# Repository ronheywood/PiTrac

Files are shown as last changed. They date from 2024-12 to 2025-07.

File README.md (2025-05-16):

**Introduction to PiTrac:**

- [Introduction](#introducing-pitrac)
  - [Project Page](#project-page)
- [PiTrac - Start Here](#getting-started)
- [PiTrac - Setup and Configuration](#setup-and-configuration)
- [PiTrac - Join the Discord](#join-the-discord)

## Introducing PiTrac
Introducing [PiTrac](https://hackaday.io/project/195042-pitrac-the-diy-golf-launch-monitor) \- the world’s first (free\!) open-source golf launch monitor (as far as we know). 



PiTrac uses low-cost Raspberry Pi(\*) computers and cameras to determine golf ball launch speed, angles and spin in three dimensions.  PiTrac interfaces with both GSPro and E6/TruGolf simulators, and its output is also accessible on a stand-alone web-based app.  \[We’ve reached out to 2k/TopGolf, but no response yet.\]

PiTrac uses off-the-shelf hardware, and includes a [parts list](https://github.com/jamespilgrim/PiTrac/blob/main/Documentation/PiTrac%20-%20DIY%20LM%20%20Parts%20List.md) with links to potential suppliers.  The only custom part is a small printed circuit board.  The fabrication instructions for that PCB are included in the open-source distribution and it can be manufactured for a few dollars.  The two Pi computers and cameras are the most expensive parts, and cost around $250 in total.

PiTrac is not a commercial product for sale–the full design is being released as open source on GitHub for folks to build themselves.  It’s not easy, but if you’re handy with a soldering iron, can figure out how to 3D print the parts, and are willing to burrow into the Linux operating system to compile and install software, you should be able to create your own PiTrac\!  

We are hoping that we can inspire a community of developers to help test and continue PiTrac’s development.  This is a really immature project right now.  The basic features usually work reliably, but the current release is a bit dodgy.  We’re looking for folks to try building their own PiTracs and help us improve the documentation and design to make it easier for other people to do the same.

## Project Page
Please visit our [project page](https://hackaday.io/project/195042-pitrac-the-diy-golf-launch-monitor) and also our YouTube channel [here](https://www.youtube.com/@PiTrac) for more details and videos.  The [GitHub repository](https://github.com/jamespilgrim/PiTrac) is in the works and already has the 3D printed part designs, the hardware design and initial software documentation.  If you’re interested in more of the details and some of PiTrac’s development history, please look through the [project logs](https://hackaday.io/project/195042-pitrac-the-diy-golf-launch-monitor#menu-logs).  

Finally, any help at our [support page](https://ko-fi.com/Pitrac) would be appreciated to continue this work and complete the release process.

(\*) Raspberry Pi is a trademark of Raspberry Pi Ltd.  The PiTrac project is not endorsed, sponsored by or associated with Raspberry Pi or Raspberry Pi products or services.

## [Getting Started](/Documentation/PiTrac%20–%20START%20HERE.md)
The process of building your own PiTrac DIY Launch Monitor is described here at a high level. There are several more-detailed instruction documents elsewhere in the PiTrac repository that are referred to below for various sub-assemblies and tasks like compiling the code and preparing the build environment.

## [Setup and Configuration](/Documentation/Raspberry%20Pi%20Setup%20and%20Configuration.md)
The instructions which are targeted toward getting setup on a step-by-step basis. These instructions start with a Raspberry Pi with nothing on it, and are meant to describe all the steps to get from that point to a working, compiled version of PiTrac.  PiTrac currently requires two Raspberry Pi’s, so the majority of these instructions will have to be repeated twice.  Because the ‘smaller’ Pi system that connects to Camera 2 is the only Pi that handles the Tomcat/Tomee web-based GUI for the system, there are a few more steps for that system.

## [Join the Discord](https://discord.gg/CP3gVkH7)
The PiTrac discord is where you can get help or show off your PiTrac build, discuss features and get to know other PiTrac builders. PiTrac is still a new project, so the Discord is a way to clear up any fuzzy parts of the initial ecosystem. Click the link above or copy this invite link in Discord: `https://discord.gg/9nEeVrPX`.

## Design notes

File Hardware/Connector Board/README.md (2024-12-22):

**Description:**

A small PCB that supports:

1. high-speed (up to 1MHz), isolated switching of a high-power signal (12V, 100W) to a device such as an LED strobe; and
2. connecting a GPIO camera shutter signal from one Raspberry Pi to the external trigger (XTR) of a Pi Global Shutter (GS) Camera that is connected to a _second_ Raspberry Pi.

The board uses high-speed opto-isolators to keep the power plane of the two Pi’s isolated from each other and from the 12V switching circuit.

The PCB itself can be manufactured fairly inexpensively from the fabrication outputs at place like <https://jlcpcb.com/> and <https://pcbway.com> .

The [PiTrac DIY golf launch monitor project](https://hackaday.io/project/195042-diy-golf-launch-monitor) is using this board to drive its infrared strobe light and to allow one Pi to trigger the shutter of a second Pi. This is all used to capture the stop-motion images for the monitor.

Please consider supporting this work and the DIY LM project here: <https://ko-fi.com/PiTrac>  

**Parts Needed for Assembly:**

| **Item** | **Qty** | **Reference(s)** | **Value** | **LibPart** | **Footprint / Details** |
| --- | --- | --- | --- | --- | --- |
| 1 | 1 | J3  | ~ | [USB B Micro Female Pinboard](https://www.amazon.com/Pinboard-MELIFE-Interface-Adapter-Breakout/dp/B07W6T97HZ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) | The included pin headers can be used for the parts below |
| 2 | 2 | R1, R4 | 330 ohm R | Resistor (1/4 Watt)<br><br>A decent assortment kit is [here](https://www.amazon.com/gp/product/B003UC4FSS/ref=ppx_yo_dt_b_search_asin_title?ie=UTF8&psc=1) | Resistor_THT:R_Axial_DIN0207_L6.3mm_D2.5mm_P10.16mm_Horizontal |
| 3 | 2 | R2, R3 | 270 ohm R | Resistor (1/4 Watt)| Resistor_THT:R_Axial_DIN0207_L6.3mm_D2.5mm_P10.16mm_Horizontal |
| 4 | 3 | Shutter1, Strobe1, Sys1_GND1 | ~ | &lt;These are just test-point holes to solder test wires into&gt; | TestPoint:TestPoint_THTPad_2.5x2.5mm_Drill1.2mm |
| 5 | 1 | Sys1_Conn1 | ~ | 4 Pin Header | Connector_PinHeader_2.54mm:PinHeader_1x04_P2.54mm_Vertical |
| 6 | 1 | Sys2_Conn1 | ~ | 3 Pin Header | Connector_PinHeader_2.54mm:PinHeader_1x03_P2.54mm_Vertical |
| 7 | 2 | U2, U3 | H11L1 | [Isolator:H11L1](https://www.amazon.com/dp/B09KM2BJCF?ref_=pe_386300_442618370_TE_sc_as_ri_0) | Package_DIP:DIP-6_W7.62mm |
| 8 | 1 | U4  | 74HC04 | 74xx:74HC04 | Package_DIP:DIP-14_W7.62mm_Socket |
| 9 | 1 | U5  | ~ | [Dual_Mos_Driver_Module](https://www.amazon.com/Anmbest-High-Power-Adjustment-Electronic-Brightness/dp/B07NWD8W26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) | Verdant_Custom_Footprint_Library:PCB Dual MOS Driver Module |
| | 2 | 2.5M Bolt<br><br>2.5M Nut | | | These help mechanically tie down the USB-B power connector to the board |
| | 2 | 6 - pin DIP socket | | &lt;Optional&gt;<br><br>A decent assortment kit is [here](https://www.amazon.com/dp/B01GOLSUAU?ref=ppx_yo2ov_dt_b_fed_asin_title) | The opto-isolators and the hex inverter chip are the most likely to be blown up or injured by solder over-temps.  So best to put them in sockets. |
| | 1 | 14 - pin DIP socket<br><br>&lt;Optional&gt; | | &lt;Optional&gt; | |

**Note:** A 5V USB-B power supply with a male micro-USB connector is currently necessary to run the board. The supply is used as an isolated, independent (downstream of a transformer) power plane to try to keep the Pi’s and the Pi Camera safe.

**Final view of top/bottom of completed PCB:**





**NOTE:** Don’t be like the people who made the above boards. For example, use flux-cleaner to get rid of the excess flux when you are done!

**Assembly Notes (see supporting images of the board):**

1. If desired (we suggest it), solder the two 6-Pin DIP sockets and one 14 pin DIP socket for the H11 opto-isolators and the 740s4 hex inverter.
2. Use the two 2.5M bolts and nuts (nuts on the bottom of the PCB) to secure the USB board to the lower-left corner. Strip 1” of a thin wire bare and cut in two half-inch pieces that will fit through the VCC and GND holes of the USB board and through the back of the Connector Board PCB. Bend the ends to hold the wires in place and solder and trim.
3. Solder a header pin post (see picture) into the GND and TRIG holes on the left side of the Dual MOS Driver Module so that at least 2mm of pin sticks out the bottom. Using these headers makes it easier to test-probe the trigger signal. Then insert the lower parts of the pins (as well as the four parts of the pins sticking out below the screw terminals) into the Connector Board PCB and solder. Alternatively, the same wire-through-the component-and-board technique used for the USB board can be used here. The four terminals below the screw terminals are not electrically important for the PCB, but soldering them helps mechanically secure the Dual-MOS switching component.
4. It is useful (but not necessary) to solder three wires to the test ports on the left of the PCB. When something is not working, the ability to hook an oscilloscope up to these ports is important. If you strip the wires on the other end away from the board, make sure you protect them from accidentally contacting other component. [These plugs](https://github.com/jamespilgrim/Wire-end-Plug) can be used for that purpose.
5. Attach the 12V input and output wire pairs to the Dual MOS component’s screw terminals. It’s best NOT to tin the ends, as the terminals seem to make better contact that way. Add some plugs (e.g.,  [Ideal Industries 30-102 Power Plug](https://www.amazon.com/Ideal-Industries-30-102-Power-72427/dp/B01LYF1WV9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).) to the ends of the leads to make it easier to connect/disconnect them later to the strobe and the LED power supply. The use of different ends for input and output (e.g., one male, one female) may make it more difficult to later plug these in wrong (output to input)!

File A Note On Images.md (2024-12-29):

One note on images in the documentation.  We don't currently have a good pipeline to convert the documentation we're writing into markdown (.md) files with embedded images.  As a short term work-around for now, we're releasing the documentation in .rtf format--with embedded images--to make it easier for folks to download and view them.  We will add images inline into documents as we can.

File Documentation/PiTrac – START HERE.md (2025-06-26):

**PiTrac – Start Reading Here**

The process of building your own PiTrac DIY Launch Monitor is described here at a high level.   There are several more-detailed instruction documents elsewhere in the PiTrac repository that are referred to below for various sub-assemblies and tasks like compiling the code and preparing the build environment.

First a bit of a caveat – this is not a beginner project.  You’ll need to be at least a little familiar with Linux and to be able to, for example, use an editor like vi that is available on Linux as well as have some experience compiling code in that environment.  Also, please read the [“What is PiTrac” missive](https://github.com/jamespilgrim/PiTrac/blob/main/Documentation/PiTrac%20-%20What%20is%20it.md) to make sure you understand the nature of the project.  We hope you’ll build one of your own PiTracs, but want to make sure you know things like the fact it only works for right-hand players right now (hopefully fixed early next year) and that you’ll have to do a little careful soldering that will void some warranties on the Pi Camera\! 😊  We’re also certain that there are still lots of mistakes in the documentation (not to mention the code).  So, you’ll have to expect that there will be some hiccups.  We are hoping to be able to rely on our first builders to help us correct the early issues, so please check the Issues section in github and email with any questions to [pitrac.lm@gmail.com](mailto:pitrac.lm@gmail.com). 

If you'd like to check out the software without needing Raspberry Pi's or building the enclosure, you can do that, too, in a limited way.  In order to just build the software and step through it's processing (with pre-made images instead of using live cameras), please read  [PiTrac - Debugging and Code Walk-Thrroughs](https://github.com/jamespilgrim/PiTrac/blob/main/Documentation/PiTrac%20-%20Debugging%20and%20Code%20Walk-Throughs.md).

With that said, here is what you need to do to make your own PiTrac:

[0\. Figure out what type of PiTrac you want to build - read the project roadmap](https://github.com/jamespilgrim/PiTrac/blob/main/Documentation/PiTrac%20RoadMap.md)

[1\. Download the PiTrac Repository](#1-download-the-pitrac-repository)

[2\. Gather the Parts You’ll Need](#2-gather-the-parts-youll-need)

[3\. Setup the Raspberry Pi Computers That You Will Use in the PiTrac](#3-setup-the-raspberry-pi-computers-that-you-will-use-in-the-pitrac)

[4\. Print the Parts That Make Up the PiTrac Enclosure](#4-print-the-parts-that-make-up-the-pitrac-enclosure)

[5\. Assemble Your PiTrac](#5-assemble-your-pitrac)

[6\. Perform Startup Testing and Final Configuration](#6-perform-startup-testing-and-final-configuration)

# 1. Download the PiTrac Repository

If you haven’t already done so, download the entire current PiTrac repository.  This can be accomplished using any one of several github utilities.  Exactly how you do this will depend on your particular environment, but here’s a few ways:

* 1\.       If you’re on an Apple or Unix computer, you probably already have git installed.  Just open a terminal window.  Change directories to where you want to land your copy of the PiTrac repository, and do:  
  * a.       git clone https://github.com/jamespilgrim/PiTrac.git  
* 2\.       For Windows (and the Mac, for that matter), there’s lots of YouTube videos.  [Here’s a decent one](https://www.youtube.com/watch?v=7ouVv6PFZGc&t=281).  Once you’ve installed git, you can use one of the tools described in the video to clone the PiTrac project as described above for Macs.  
* 3\.       You can also install Microsoft Visual Studio, which includes git management functionality.

# 2. Gather the Parts You’ll Need

We’ve listed the basic components that you’ll need to build a PiTrac in the [Parts List here](https://github.com/jamespilgrim/PiTrac/blob/main/Documentation/PiTrac%20-%20DIY%20LM%20%20Parts%20List.md).  We (at least currently) don’t sell any of these components. 

The one component that you won’t be able to just buy off the shelf is the little Connector Board printed circuit board.  However, the manufacturing input files are [here](https://github.com/jamespilgrim/PiTrac/tree/main/Hardware/Connector%20Board), and if you send those to a company like [www.jlcpcb.com](http://www.jlcpcb.com/) or [www.pcbway.com](http://www.pcbway.com/), they will often include a small run of this PCB on the unused parts of larger boards they are making for other customers.  This is usually available for only a few dollars, and the slowest shipping option to the US (for example) is also only a few dollars.  It can take a couple of weeks for this process, so you might want to get it going soonest.

The other components can be purchased at places like [www.adafruit.com](http://www.adafruit.com/) and [www.pimoroni.com](http://www.pimoroni.com/) , not to mention Amazon and directly from the [Raspberry Pi folks](https://www.raspberrypi.com/products/raspberry-pi-5/).  Most of the little nuts and bolts are best purchased as part of bulk kits.  See the [Component List](https://github.com/jamespilgrim/PiTrac/blob/main/Documentation/PiTrac%20-%20DIY%20LM%20%20Parts%20List%20.md).

NOTE:  You may want to skim through the rest of the documents to see if you want to modify the parts list.

# 3. Setup the Raspberry Pi Computers That You Will Use in the PiTrac

The next step is to get your Pi computers up and running and to install the software packages that will be needed to build the PiTrac software.  This process is done first, before putting together the 3D-printed enclosure that the Pi computers are eventually mounted to.

See the document for how to prepare the Pi’s and build the PiTrac executables [here](https://github.com/jamespilgrim/PiTrac/blob/main/Documentation/Raspberry%20Pi%20Setup%20and%20Configuration.md).

NOTE: If you are going to have someone else 3D print the enclosure, it’s probably not a bad idea to get that started while you work on getting the Pi’s setup.

# 4. Print the Parts That Make Up the PiTrac Enclosure

If you have your own 3D Printer (or access to one), you can print your own 3D parts using the [3D design models](https://github.com/jamespilgrim/PiTrac/tree/main/3D%20Printed%20Parts/Enclosure%20Models) and [assembly instructions](https://github.com/jamespilgrim/PiTrac/blob/main/Documentation/DIY%20LM%20Enclosure%20Assembly.zip).  We know that some folks have also had some luck having a third-party printing company take the models and documentation and print the parts for a fee.

Please note that there are now TWO versions of the enclosure.  The first (original) one is relatively large, as it includes room for all of the power adapters and other things that are necessary.  The Version 2 enclosure is more compact, and is set up to use the forthcoming (hopefully!) Compute Board.  The Compute Board will have all of the power supplies, networking, connections, etc. on a single board.  The board will use the smaller Pi Compute Modules instead of full Raspberry Pi Model 5s.  However, there is a variant of the Version 2 enclosure that can still use the "standard" Pi's like the Version 1 enclosure uses.

The Version 1 parts are large enough that you’ll need several spools of printer filament, not to mention a few days to get everything printed.  This is our first project open-sourcing 3D part designs, so be ready for some hiccups here.  The Version 2 enclosure can be printed with (barely) a single 1kg spool.

# 5. Assemble Your PiTrac

Once you have PiTrac compiled on each of the two Pi’s, you’re ready to attach the Pi’s to the 3D-printed PiTrac enclosure and assemble the final(ish\!) launch monitor.  See the [assembly instructions](https://github.com/jamespilgrim/PiTrac/blob/main/Documentation/DIY%20LM%20Enclosure%20Assembly.md).  The assembly requires that the cameras be calibrated as the LM is being built.  For that reason, the PiTrac software (which performs some of that calibration) needs to be ready to go before you start putting things together.

# 6. Perform Startup Testing and Final Configuration

Use [this document](https://github.com/jamespilgrim/PiTrac/blob/main/Documentation/PiTrac%20Start-Up%20Documentation.md) to perform some final sanity-checks and testing.  That document also details how to get PiTrac running.

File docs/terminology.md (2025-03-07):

---
title: Terminology
layout: home
parent: Home
nav_order: 1.2
---

### Terminology 

<table>
  <tr>
    <th>Device</th>
    <th>Description</th>
    <th>Notes</th>
  </tr>
  <tr>
    <td>Flight Camera</td>
    <td>This is the modified camera that will be installed on the first floor of the enclosure. Bottom camera.</td>
    <td> 
    - This camera is attached to Core Pi.<br>
    - Previously known as camera 2. In scripts, may be referred as such.
    </td>
  </tr>
   <tr>
    <td>Tee Camera (As in, Tee off)</td>
    <td>This is an unmodified camera that will be installed on the top floor of the enclosure. Top camera</td>
    <td> 
    - This camera is attached to Tee Pi.<br>
    - Previously known as camera 1. In scripts, may be referred as such.
    </td>
  </tr>
     <tr>
    <td>Tee Pi </td>
    <td>This Raspberry Pi that is used for the shared directory--Samba Server. It is recommended that you use a faster Pi (e.g. Pi5) for this Pi. Installed on the top floor of the enclosure.</td>
    <td> 
    - Connected to the Tee Camera (The top floor Camera).<br>
    </td>
  </tr>
       <tr>
    <td>Flight Pi </td>
    <td>Flight Pi - used for messaging running ActiveMQ and Apache Tomee. Installed on the bottom floor of the enclosure.</td>
    <td> 
    - Connected to the Flight camera (the modified camera).<br>
    </td>
  </tr>
</table>

### PiTrac 
<a href="https://1drv.ms/i/c/35c1f51c7fbc7aba/IQSr4Eu550wjRoRfLHclEgkAARA1St3Qvlx-dvPuE9Aupqc?width=1024">
PiTrac
</a>

### Diagram
<a href="https://1drv.ms/i/c/35c1f51c7fbc7aba/IQRJJ03UsL98QbZK4ppRKmdsAQ_Gr50rl9IbFNyvEkk1Wyg?width=1030&height=894">
PiTrac Diagram
</a>

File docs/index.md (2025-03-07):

---
title: Home
layout: home
nav_order: 1
---

### PiTrac - The DIY Golf Launch Monitor

- As seen on [Hackaday](https://hackaday.io/project/195042-pitrac-the-diy-golf-launch-monitor)
- Also on [Reddit](https://www.reddit.com/r/Golfsimulator/comments/1hnwhx0/introducing_pitrac_the_open_source_launch_monitor/)

The PiTrac project is a fully-functional golf launch monitor that avoids the need for expensive high shutter-speed and high frame-rate cameras. We've developed techniques for high-speed, infrared, strobe-based image capture and processing using cameras such as the Pi Global Shutter camera (~US$50 retail) and Raspberry Pi single board computers.

PiTrac determines ball speed, launch angles, and spin in 3 axes. Its output is accessible on a stand-alone web app. Interfaces to popular golf-course simulators including GsPro and E6 are working. 2k/TopGolf never responded to our requests.

<p align="center">Introduction to PiTrac's Enclosure
&nbsp;
<iframe width="640" height="420" src="https://www.youtube.com/embed/1pX95VoKsS4?si=O_Mzlwz3F93mBZXC" frameborder="0" allowfullscreen></iframe>
</p>

----

[^1]: [It can take up to 10 minutes for changes to your site to publish after you push the changes to GitHub](https://docs.github.com/en/pages/setting-up-a-github-pages-site-with-jekyll/creating-a-github-pages-site-with-jekyll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).

[Just the Docs]: https://just-the-docs.github.io/just-the-docs/
[GitHub Pages]: https://docs.github.com/en/pages
[README]: https://github.com/just-the-docs/just-the-docs-template/blob/main/README.md
[Jekyll]: https://jekyllrb.com
[GitHub Pages / Actions workflow]: https://github.blog/changelog/2022-07-27-github-pages-custom-github-actions-workflows-beta/
[use this template]: https://github.com/just-the-docs/just-the-docs-template/generate

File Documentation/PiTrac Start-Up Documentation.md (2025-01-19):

**PiTrac Testing and Start-Up Documentation**

If you are at this point, you should have PiTrac compiled on both Pi’s, your enclosure built, and your cameras calibrated.  If that’s not quite done yet, see the [START HERE](https://github.com/jamespilgrim/PiTrac/blob/main/Documentation/PiTrac%20%E2%80%93%20START%20HERE.md) document to determine where to go first.

**Start-up and Sanity Checks:**

1. Ensure that each account that you will run PiTrac in has the PITRAC\_ROOT set to the directory above the “ImageProcessing” directory where the meson.build file exists, as well as setting the other required environment variables. A typical .zshrc file in your user’s root directory will look like:  
   ```  
   export PITRAC\_ROOT=/Dev/PiTrac/Software  
   \# Note that the \~ symbol is only expanded by the shell, so  
   \# may not work if it is pulled directly into PiTrac code. However,  
   \# these variables are expanded before being injected into PiTrac  
   \# via command-line parameters  
   export PITRAC\_ROOT=/mnt/PiTracShare/Dev/PiTrac/Software/LMSourceCode  
   export PITRAC\_BASE\_IMAGE\_LOGGING\_DIR=\~/LM\_Shares/Images/  
   export PITRAC\_WEBSERVER\_SHARE\_DIR=\~/LM\_Shares/WebShare/  
   export PITRAC\_MSG\_BROKER\_FULL\_ADDRESS=tcp://10.0.0.41:61616  
   \# Only uncomment and set the following if connecting to the  
   \# respective golf sim (e.g., E6/TruGolf, GSPro, etc.)  
   \#export PITRAC\_E6\_HOST\_ADDRESS=10.0.0.29  
   \#export PITRAC\_GSPRO\_HOST\_ADDRESS=10.0.0.29   
   ```  
2. Ensure the golf\_sim\_config.json file is correctly set up.  If not sure, follow the [Configuration File documentation](https://github.com/jamespilgrim/PiTrac/blob/main/Documentation/PiTrac%20configuration%20and%20the%20golf_sim_config.json%20file.md).  
3. Check that the executable at least runs by itself:  
   1. cd $PITRAC\_ROOT/ImageProcessing  
   2. build/pitrac\_lm \--help  
   3. (the executable should show the command-line parameters)

**Check the Strobe Light and Camera Triggering:**

1. Problems can sometimes exist in the pathway from the Pi 1 to the Pi 2 Camera and the Strobe Assembly (though the Connector Board).  For example, sometimes the ribbon cable may be loose or mis-connected from the Pi 1 to the Connector Board.  So a few initial checks are good to perform before going further…  
2. Position the PiTrac so that you can see into the IR LEDs through the LED lens (the small array of square LEDs should be visible)  
3. Run a strobe-light test  
   1. cd $PITRAC\_ROOT/ImageProcessing  
   2. ./RunScripts/runPulseTest.sh  
   3. The above script will periodically send a series of short “on” pulses to the LED strobe light.  Due to the IR wavelengths used by the LED (at least the one on the parts list), you should be able to see very short groups of dark-reddish pulses in the LED lens.  
      1. **NOTE** \- Just in case, look at the LED from at least a couple feet away, especially if you are using a higher-power LED.  
4. If you can’t see the pulsing, double-check the output of the runPulseTest script as well as the connections from the Pi 1 near the top of the LM to the Connector Board.  
   1. If you can’t see the red pulses, check first to see if the little red LED on the Connector Board is pulsing.  If it is, but there is no strobe-light pulses, it’s likely one or more of the following problems:  
      1. The power-supply to the Connector Board is not connected correctly  
      2. The wiring from the output of the Connector Board to the LED strobe assembly not connected correctly  
5. You’ll have to hit Ctrl-C to stop the pulse test.  
6. **WARNING** \- Double-check after stopping the test that the LED is OFF (and not showing any red color\!)  
7. Camera 2 Shutter Triggering  
   1. When the system is running normally, the shutter for Camera 2 is triggered by a pulse from the Pi 1\.  The correct functioning of this signal pathway should be confirmed before starting the system in full.  
   2. To check the triggering, we will set the Pi 2 camera in an “external” triggering mode, where its shutter is controlled by the XTR signal that is sent to the camera from Pi 1 through the connector board.  
   3. On the Pi 2, cd $PITRAC\_ROOT/ImageProcessing  
   4. sudo ./CameraTools/setCameraTriggerExternal.sh  
   5. rpicam-hello  
   6. ./RunScripts/runCam2Still.sh  
   7. Normally, the camera would not take a picture because it is waiting for a signal from the Pi 1\.  Instead, the system’s rpicam-hello program should hang and not do anything while external triggering is set, but then should take a picture as soon as the runPulseTest.sh script is run  
   8. On the Pi 1, do:  
      1. /RunScripts/runPulseTest.sh  
   9. As soon as the Pi 1 script starts sending pulses to the Camera 2 (as well as pulses to the LED strobe array), the Camera 2 program that is running should take a picture.  Of course, the resulting picture is likely to be pretty dark if you have the IR filter on it.  
   10. Finally, return the triggering to internal on the Pi 2:  
       1. $PITRAC\_ROOT/CameraTools/setCameraTriggerInternal.sh  
8. Full System Startup  
   1. To run PiTrac, just start the runCam1.sh on Pi 1 and runCam2.sh on Pi 2\.  Start the Pi 2 executable first so that it’s ready to take a picture as soon as Pi 1 determines the ball has shown up.    
   2. The executables should be run with \--logging\_level=info or higher (e.g., warning).  Setting the executables at DEBUG or TRACE may slow the system down so much that it will not reliably take the images quickly enough to catch the flight of the golf ball.  However, the information from trace-level is often still useful.  
   3. For problems, please see the still-under-construction [troubleshooting guide](https://github.com/jamespilgrim/PiTrac/blob/main/Documentation/PiTrac%20Troubleshooting.md).

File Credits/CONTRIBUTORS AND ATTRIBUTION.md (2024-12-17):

**CONTRIBUTORS AND ATTRIBUTION**

The PiTrac team is grateful for everyone who has authored, supported, maintained and hosted the open-source technology that the system uses.  PiTrac works using, in conjunction with, or at least inspired by the following projects and technologies.  We especially thank the individual developers of these great technologies for their contributions to the community.

1. [Active-MQ](https://activemq.apache.org/) (multi-protocol messaging middleware)  
2. Apache [Jakarta](https://jakarta.apache.org/) Server Pages (serves the web-based default system GUI)  
3. [Boost](https://www.boost.org/) (various foundational libraries for logging, multi-threading, thread-safe data structures, command line processing, etc.)  
4.  [Debian](https://www.raspbian.org/) (Raspbian) Linux (OS)  
5. [ED\_Lib](https://github.com/CihanTopal/ED_Lib) (Edge detection)  
6. [fmtlib/fmt](https://fmt.dev/11.0/) (Formatting library that provides c++20 style formatting)  
7. [FreeCad](https://www.freecad.org/downloads.php) (Parametric 3D CAD/CAM software)  
8. [JSON](https://github.com/google/gson) (serialization)  
9. [JMS](https://www.oracle.com/java/technologies/java-message-service.html#:~:text=The%20Java%20Message%20Service%20\(JMS,coupled%2C%20reliable%2C%20and%20asynchronous.) (messaging)  
10. [KiCad](https://www.kicad.org/) (schematic capture and PCB layout)  
11. [Libcamera](https://libcamera.org/) and [Libcamera/rpicam-apps](https://github.com/raspberrypi/rpicam-apps) App (open-source camera stack & framework)  
12. [Maven](https://maven.apache.org/guides/getting-started/maven-in-five-minutes.html) (java build automation)  
13. [Meson](https://mesonbuild.com/) & [Ninja](https://ninja-build.org/) (build tools)  
14. [Msgpack](https://msgpack.org/index.html) (efficient architecture-independent serialization)  
15. [OpenCV](https://opencv.org/) (image processing & filtering, matrix math)  
16.  [libgpiod](https://github.com/brgl/libgpiod) (GPIO and SPI library)  
17. [Prusa MK4S](https://www.prusa3d.com/product/original-prusa-mk4s-3d-printer-kit/) and [PrusaSlicer](https://www.prusa3d.com/page/prusaslicer_424/)(3D Printer and Slicer)  
18. [Raspberry Pi](https://www.raspberrypi.com/) Single-Board Computers  
19. [Shedskin](https://shedskin.readthedocs.io/en/latest/index.html) (Certain colorsys elements)  
20. [Tomee and other Apache products](https://tomee.apache.org/) (hosts the web-based interface)  
21. [KiCad](https://www.kicad.org/) (Schematic and PCB software)

We are also thankful for individual contributors who—even if we haven’t used their code—have answered questions and who have spent a lot of their time making groups such as the Raspberry Pi community a smarter, better place.  In particular,

1. [Hermann Stamm-Wilbrandt](https://stamm-wilbrandt.de/en/) (@HermannSW)  
2. Jake Hauck and jRhodes95 @ github  
3. Senior Principal Engineer Naushir Patuck and his colleagues at Raspberry Pi  
4. @Arnold Palmer, @mca312, @DJ, @Hank, @kallikarls and others at GSPro Country Club  
5. Professor Shingo W. Kagami, Ph.D., Graduate School of Information Sciences, Tohoku University

We would not have been able to create the golf simulator interfaces without the help of the following folks:

1. The very supportive GSPro business development people  
2. The folks at TruGolf, especially Melissa and Ryan.

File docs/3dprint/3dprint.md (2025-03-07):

---
title: 3D Print
layout: home
nav_order: 3
---

3D Parent page..

----

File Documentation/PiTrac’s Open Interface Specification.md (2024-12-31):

**PiTrac’s Open Interface (POI)**

**TBD \- THIS DOCUMENT IS UNDER CONSTRUCTION**

This document describes the details of the interface PiTrac provides to allow other systems to receive shot data from PiTrac and to accept certain control instructions from outside (such as golf club selection.  The interface is also used to support control and synchronization messages between the two Pi-based computers that comprise PiTrac.  The web-based PiTrac GUI is an example of a client for the POI messages.  The GUI consumes shot data messages and displays them to the user.

The inter-PiTrac messages may be expected to continue to change, at least at this early point in the system’s development.  However, it is hoped that the messages that are sent outside of PiTrac, such as shot data, will remain fairly constant.

POI is built on the Apache [ActiveMQ](https://activemq.apache.org/) open source multi-protocol messaging platform.  Byte-by-byte encoding is based on the [MsgPack](https://msgpack.org/index.html) standard to eliminate typical encoding issues such as big-endian/little-endian, etc.  MsgPack is supported in over a dozen programming languages and across most popular operating systems.  As such, almost anything should be able to communicate with PiTrac with a minimum of code.

ActiveMQ essentially provides a payload (along with a payload type) and the required message-brokering, routing, subscriptions, tracking, etc. for that payload.  The payload is then formatted in a platform-independent manner by the MsgPack standard. 

Although this document presents various constants and formats for the POI, the most authoritative source of this information is to be found in the C++ code of PiTrac, including the following files, and especially within the macros called MSGPACK\_DEFINE:

* gs\_ipc\_message.\*  
* gs\_ipc\_result.\*  
* gs\_ip\_control\_msg.\*  
* gs\_clubs.\*

The above IPC (inter-process communication) classes provide both C++ representations of the IPC messages, as well as methods to help serialize and de-serialize the MsgPack-formatted payloads of the Active MQ messages into these classes.

When this document refers to types such as String or Float, those are to be understood as MsgPack types.

**POI Outputs:**

Each ActiveMQ IPC message sent to/from PiTrac has a particular message type that allows the receiver to determine how to de-serialize and parse the payload of the message.  The potential types and their meanings are described below:

| Value | Message Type | Notes |
| :---- | :---- | :---- |
| 0 | Unknown  | Essentially an error \- should not occur |
| 1 | RequestForCamera2Image  | Sent by the Pi 1 system to signal the Pi 2 system to be ready to take a picture.  This also signals to the Pi 2 that the Pi 1 system is going to expect a picture in a Camera2Image \- type message, and that the Pi 1  will be sending an external trigger to the Pi 2 camera. |
| 2 | Camera2Image  | Sent by the Pi 2 system when it takes a picture.  The message will include the picture itself.  The picture is an OpenCV Mat object packed as a MsgPack serialized data type.  See gpc\_ipc\_mat.\* in the PiTrac C++ source code.  |
| 3 | RequestForCamera2TestStillImage | Reserved for testing modes.  |
| 4 | Results | The result of the current system's operation, such as a ball hit |
| 5 | Shutdown  | Tells the PiTrac system to shutdown and exit  |
| 6 | Camera2ReturnPreImage  | Picture of the 'hit' area before the ball is actually hit.  Can be used for, e.g., subtractive filtering |
| 7 | ControlMessage  | A control message such as a club selection. |

| Element | Field Name | MsgPack Type | Notes |
| :---- | :---- | :---- | :---- |
| 0 | Carry\_meters  (\*) | Integer OR Float | Not currently computed.  The carry is calculated by external golf sims like GSPro. |
| 1 | speed\_mpers  (\*) | Integer OR Float | Ball speed in MPH |
| 2 | launch\_angle\_deg  (\*) | Integer OR Float | Positive degrees are from the ground up to the line of flight. Must check type before decoding, due to an apparent issue in MsgPack for float values that are integer-like (e.g., 123.0). |
| 3 | side\_angle\_deg  (\*) | Integer OR Float | Must check type before decoding. A positive side angle number means the ball will land to the right of the target, while a negative number means it will land to the left |
| 4 | back\_spin\_rpm  (\*) | Integer | Generally positive.  The spin that occurs from, e.g., a chip shot. |
| 5 | side\_spin\_rpm  (\*) | Integer | Negative is left spin (counter-clockwise from above ball) |
| 6 | confidence  (\*) | Integer | A value between 0 and 10\.  10 \- the results are as confident as the system can be.  0 \- no confidence at all, and probably an error occurred.  |
| 7 | club\_type  (\*) | Integer | kNotSelected \= 0, kDriver \= 1, kIron \= 2, kPutter \= 3  |
| 8 | result\_type | Integer |  See Result Types, below  |
| 9 | message | String | Can be NilValue |
| 10 | log\_messages | Array of Strings | Array and each string can be NilValue |

The elements with asterisks and highlighted in green, above, are only set when the result\_type \= kHit (= 6).

In the IPC Result message, the Integer result type can be any one of the following:

| Integer Value | Value | Notes |
| :---- | :---- | :---- |
| 1 | Initializing | TBD |
| 2 | WaitingForBallToAppear |  |
| 3 | PausingForBallStabilization |  |
| 4 | MultipleBallsPresent |  |
| 5 | BallPlacedAndReadyForHit |  |
| 6 | Hit |  |
| 7 | Error |  |
| 8 | CalibrationResults |  |
| 9 | ControlMessage |  |

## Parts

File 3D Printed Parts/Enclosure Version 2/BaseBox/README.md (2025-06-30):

**Description:**

The Basebox is the base of the PiTrac version 2 enclosure.  The Basebox consists of three parts - a Main Body, an End-Cap that fits into the body, and a Light Shield that fits into the other two parts.  The Basebox houses the Meanwell power supply unit and secures the tower that holds all of the electronics, cameras, and other parts. 
A [FreeCAD 1.0](https://www.freecad.org/downloads.php) compatible parameterized model is included here along with .stl files.

**Printing Notes:**

PLA works well for this, but PETG probably would as well. The main body is printed standing on its closed end, which makes for a pretty high print.  You may need to make sure your printer won't have problems near the top of the print.

Recommended print settings: 2 perimeter layers (3 for a little more strength), 15% infill, grid or rectilinear infill patterns, custom painted-on supports (see the Prusa Slicer .3mf file for where the supports are needed). The main body requires glue-stick glue on the printer bed and we recommend a 7mm brim assist because of the height and relatively small print base.  
The end-cap is a pretty easy print, and should not need glue or a brim.

The Light Shield Body prints pretty well with any settings, but we use 2 perimeter layers, 15% infill, grid infill and no supports, brims, or glue.

Note that a beginning of a sketch for an x-shaped leveling support base has been started in the model, but is not finished and not yet printable.

Note also that the "shank shield" is not designed for 3D printing.  The hope is that the .dxf file can be used to laser cut or mill that part out of acrylic or (better) polycarbonite.
**Assembly Notes:**

See the [main assembly instructions](https://github.com/jamespilgrim/PiTrac/blob/main/Documentation/PiTrac%20Version%202%20Assembly.md).

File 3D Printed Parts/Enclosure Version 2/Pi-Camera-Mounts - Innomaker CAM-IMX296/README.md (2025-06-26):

**Description:**

A camera mount that accommodates the Innomaker CAM-IMX296 cameras with an attached 3.6mm M12 or 6mm 3MP Wide Angle Lens for Raspberry Pi Cameras. The mount can tilt up/down and swivel around a bolt that attaches the base of the mount to a flat surface. A [FreeCAD 1.0](https://www.freecad.org/downloads.php) compatible parameterized model is included here along with .stl files.

The [DIY golf launch monitor project](https://hackaday.io/project/195042-diy-golf-launch-monitor) is using these mounts for two Pi Global Shutter Cameras that capture the images for the monitor. Several variations can be printed—see the annotated printed-part image. One variation is relatively low for use with a camera whose up/down tilt is minimal. Another variation is taller, allowing the camera to be tiled down by at least 30 degrees. The model is parameterized, so the mount can easily be modified to fit other needs by modifying the parameters in the “Master Document” spreadsheet, such as the “GSCam2GimbalHoleHeight” parameter. Ensure that there will be sufficient clearance between the CSI ribbon cable on the bottom of the camera and the gimbal base of the mount.

Please consider supporting this work and the DIY LM project here: <https://ko-fi.com/PiTrac>

**Printing Notes:**

PLA or PETG works well with this mount.

Recommended print settings: 4 perimeter layers (less if the bolts are not expected to be tightened very much), 15% infill, grid infill patterns, no supports. For some printers, supports to help with the curved surfaces that rotate around the horizontal axes. See .3mf file. Does not required glue-stick or brim assists.

**Parts Needed for Assembly:**

| **Quantity** | **Hardware** | **Purpose** |
| --- | --- | --- |
| 4 each | 2M x 12mm<br><br>2.0 Hex Nuts | Pi Camera Attachment Bolts (camera to back plate) |
| --- | --- | --- |
| 2 each | M4 x 12mm <br><br>M4 Hex Nuts | Pi Cam Gimbal Attachment Hinge |
| --- | --- | --- |
| 1 each | M5 x 12<br><br>M5 Hex Nut | Pi Cam (Pan) Swivel Mount (on bottom of mount) |
| --- | --- | --- |

**Note:** For the screws, stainless steel seems to be stronger than black carbon steel, though both can work. Especially in the stiffer PLA material, stainless is preferable because black carbon can break if torqued too much. For parts supply examples see [HanTof 525 Pcs 304 Stainless Steel M2 M3 M4 Phillips Pan Head Self Tapping Wood screws Assortment Kit](https://www.googleadservices.com/pagead/aclk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)., mxuteuk M2.5 Screw Assortment Set,M2.5 x 4/6/8/10/12/16/20/25mm Hex Socket Head Cap Screws Bolts Nuts Kit,400PCS 304 Stainless Steel Assorted Screws with Hex Wrench G035-M2.5, and [Besitu 1760pcs M2 M3 M4 M5 Metric Screw Assortment, Grade 12.9 Alloy Steel Hex Socket Head Cap Metric Bolts and Nuts Kit, Black Zinc Plated and Anti Rust Metric Screw Set with 4 pcs Hex Wrenches](https://www.amazon.com/dp/B0C38YFL3D?ref=ppx_yo2ov_dt_b_fed_asin_title)

**Assembly Notes:**

Start by placing the nuts in their positions. It’s easier to place each of the three nuts into its respective indent, and then temporarily place a strip of tape (e.g., scotch) over the nut to keep it in place while assembling the mount. Next, mount the camera to the backplate using 4 2.5M bolts and nuts. Then mount the backplate to the gimbal base using 2 M4 bolts. Finally, secure the entire mount to whatever base will hold it by using an M5 bolt.

The mount’s tilt and pan angles will generally stay put once the nuts are tightened, simply based on the friction between the parts. If the angles cannot be finely tuned, sanding the parts helps.

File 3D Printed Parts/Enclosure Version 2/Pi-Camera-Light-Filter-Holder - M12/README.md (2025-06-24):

**Description:**

This holder secures a 1”x1” filter on the front of a standard M12 Lens for Raspberry Pi Cameras. The filter slips into the pocket (held by friction), and then the holder attaches to the front of the lens via a simple friction mount. A [FreeCAD 1.0](https://www.freecad.org/downloads.php) compatible parameterized model is included here along with .stl files.

The [DIY golf launch monitor project](https://hackaday.io/project/195042-diy-golf-launch-monitor) is using this filter to restrict the light entering a Pi Global Shutter Camera sensor to just infrared (IR) light. The filter for the project is a [1" x 1", Optical Cast Plastic IR Longpass Filter](https://www.edmundoptics.com/p/1quot-x-1quot-optical-cast-plastic-ir-longpass-filter/5421/) (1.5mm nominal thickness), but the model is parameterized, so the holder can easily be modified to fit other thicknesses (or sizes) by modifying the parameter in the “Master Document” spreadsheet named “'PiFilterHolderFilterThickness”.

Consider supporting this work and the DIY LM project here: <https://ko-fi.com/PiTrac> Please and Thank You!

**Printing Notes:**

PETG works better for flexibility of the holder, but PLA also works. The holder is modeled in two pieces because we struggled with the mess added by supports in a single filter. But, if folks can improve on this, that would be great! Maybe print the whole thing at 45 degrees?

Recommended print settings: 2 perimeter layers, 20% infill, gyroid infill patterns, no supports. Does not required glue-stick or brim assists.

**Assembly Notes:**

Use just a few small drops of cyanoacrylate (super) glue to attach the outer filter holder to the part of the holder that slips over the lens. Otherwise, the glue may restrict the passage into which the filter is placed. Use the little lip around the holder to position the two pieces while gluing. Avoid gluing top portion of filter window where the little retainer bumps are. This allows the retainer to flex a bit when the filter moves past it. After setting/drying, a 1” filter should just slip in and click securely into place.

To remove the filter, if necessary, use a small screw-driver to push the filter out using the little window on the bottom of the holder.

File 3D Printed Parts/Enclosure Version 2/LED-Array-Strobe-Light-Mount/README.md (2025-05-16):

**Description:**

A 3D-printed mount that secures an LED array with a lens in front of the LED. An example infrared LED is: [High Power LED Chip IR 850nm 100W COB Integrated Matrix Light Beads for Night Vision Camera](https://www.amazon.com/dp/B09DPJYRQN?ref=ppx_yo2ov_dt_b_product_details&th=1), and an example lens is: [60 / 120 Degree LED Lens Optical Glass 44mm + Reflector Collimator + Fixed Bracket for 20W 30W 50W 100W COB High Power Chip (60Degree 100W lens kit](https://www.amazon.com/dp/B09XK7QTV5?ref=ppx_yo2ov_dt_b_fed_asin_title)).

**WARNING: This mount is not designed for high temperatures, and would melt if a high-power (>= 20W) LED array was left on for any more than a second or so. There is no room for a heat sink. This mount is intended ONLY for an LED that is operated as a very short-pulse strobe light, where the LED is powered for only a few milliseconds per second and with a very low duty cycle. Ensure that the LED is not inadvertently powered.**

The mount can tilt up/down and swivel around a bolt that attaches the base of the mount to a flat surface. A [FreeCAD 1.0](https://www.freecad.org/downloads.php) compatible parameterized model is included here along with .stl files.

The [DIY golf launch monitor project](https://hackaday.io/project/195042-diy-golf-launch-monitor) is using this mount for its infrared strobe light that helps capture the stop-motion images for the monitor. The mount assumes that the power wires that go to the LED will be attached to the sides of the array (see image of printed part).

Please consider supporting this work and the DIY LM project here: <https://ko-fi.com/jamespilgrim>

**Printing Notes:**

PLA or PETG works well with this mount.

Recommended print settings: 4 perimeter layers (less if the bolts are not expected to be tightened very much), 15% infill, grid infill patterns, no supports. See .3mf file. Does not required glue-stick or brim assists.

**Parts Needed for Assembly:**

| **Quantity** | **Hardware** | **Purpose** |
| --- | --- | --- |
| 4 each | M3 x 8mm self-tapping screws | LED Array Attachment Screws (array to back plate) |
| --- | --- | --- |
| 4 each | M3 x 10mm self-tapping screws | LED Lens Holder Attachment Screws (lens to back plate) |
| --- | --- | --- |
| 2 each | M4 x 12mm <br><br>M4 Hex Nuts | Strobe Gimbal Attachment Hinge |
| --- | --- | --- |
| 1 each | M5 x 12<br><br>M5 Hex Nut | Strobe (Pan) Swivel Mount (on bottom of mount) |
| --- | --- | --- |

Also required is the LED array and lens (see example suppliers, above).

**Note:** For the screws, stainless steel seems to be stronger than black carbon steel, though both can work. Especially in the stiffer PLA material, stainless is preferable because black carbon can break if torqued too much. For parts supply examples see [HanTof 525 Pcs 304 Stainless Steel M2 M3 M4 Phillips Pan Head Self Tapping Wood screws Assortment Kit](https://www.googleadservices.com/pagead/aclk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)., mxuteuk M2.5 Screw Assortment Set,M2.5 x 4/6/8/10/12/16/20/25mm Hex Socket Head Cap Screws Bolts Nuts Kit,400PCS 304 Stainless Steel Assorted Screws with Hex Wrench G035-M2.5, and [Besitu 1760pcs M2 M3 M4 M5 Metric Screw Assortment, Grade 12.9 Alloy Steel Hex Socket Head Cap Metric Bolts and Nuts Kit, Black Zinc Plated and Anti Rust Metric Screw Set with 4 pcs Hex Wrenches](https://www.amazon.com/dp/B0C38YFL3D?ref=ppx_yo2ov_dt_b_fed_asin_title)

**Assembly Notes:**

Start by placing the three nuts in their recessed positions on the two sides of the backplate and the one nut in the top of the base. It is easier to place each of the three nuts into its respective indent, and then temporarily place a strip of easy-to-remove tape (e.g., scotch) over the nut to keep it in place while assembling the mount.

If not already done, securely solder the two power lead wires to the LED array. Make sure that the positive and negative terminals and wires are clearly (and correctly!) labelled.

Mount the LED array to the backplate using four M3 self-tapping screws. Avoid touching the LEDs in the process. Run the power wires through the clips on either side of the top of the mount. It’s best to have these wires terminated in a quick-connect like an [Ideal Industries 30-102 Power Plug](https://www.amazon.com/Ideal-Industries-30-102-Power-72427/dp/B01LYF1WV9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).

Next, place the lens standoff/riser, lens, and lens holder bracket on top of the array, making sure that the mirrored separate between the LED and the lens is centered and appropriately aligned.

Then mount the lens to the backplate using four more M3 self-tapping screws. **IMPORTANT: Only tighten the screws enough to secure the holder bracket lightly against the lens and mirrored riser. There will be a gab between the bracket and the plastic risers that accept the screws of the mount. This is by design. Over-tightening can crack or break the lens, standoff, and/or LED itself. Note the gap in the annotated print part image.**

Mount the backplate to the gimbal base using 2 M4 bolts. Finally, secure the entire mount to whatever base will hold it by using an M5 bolt.

The mount’s tilt and pan angles will generally stay put once the nuts are tightened, simply based on the friction between the parts. If the angles cannot be finely tuned, sanding the parts helps.

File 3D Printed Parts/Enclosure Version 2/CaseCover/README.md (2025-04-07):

**Description:**

The Case Cover is the output protective (and aethetic) case that surrounds the inner component tower of the PiTrac version 2 enclosure.  The Case Cover consists of two parts - a Lower Half and an Upper Half.  This part separation is to allow the cover to printed on most standard-size 3D printers. The top part of the Case Cover also acts as a way of easily picking up the entire PiTrac unit.
A [FreeCAD 1.0](https://www.freecad.org/downloads.php) compatible parameterized model is included here along with .stl files.

**Printing Notes:**

PLA works well for this, but PETG probably would as well. 

Recommended print settings: 2 perimeter layers, 15% infill, grid or rectilinear infill patterns, custom painted-on supports (see the Prusa Slicer .3mf file for where the supports are needed). Both upper and lower halves require glue-stick glue on the printer bed and we recommend a 7mm brim assist because of the very small print base surface.
You'll want to paint on supports and support-exclusions so that the only places with support on the upper half of the case are the three rectangular holes that provide access to the Compute Board.

**Assembly Notes:**

See the [main assembly instructions](https://github.com/jamespilgrim/PiTrac/blob/main/Documentation/PiTrac%20Version%202%20Assembly.md).
Ultimately, the two parts will be glued together with something like thick, slower-drying super-glue such as Starbond Gap Filler Thick High Performance Super Glue.

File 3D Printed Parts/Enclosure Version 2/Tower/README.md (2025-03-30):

**Description:**

The Tower component is the backbone of PiTrac.  Most of the components (cameras, strobe, and Compute Board PCBA) are mounted on the front of the Tower. The Tower consists of two parts - a Frontplate and a Backplate.  This part separation is to allow the Tower to printed with a minimum of supports.  The top part of the Case Cover (and particularly the Shank Shield risers that the shield scews into) can also act as a way of easily picking up the entire PiTrac unit.
The Tower does not include the Shank Shield, which is made from a piece of 3/16" or 1/4" polycarbonite (recommended for durability) or plexiglas.
The Frontplate and Backplates parts are each further split into two halves to allow printing.  The height would otherwise be too tall for most printers.  
As discussed in the Assembly Notes, these resulting four parts are glued and screwed together to make up the tower.
A [FreeCAD 1.0](https://www.freecad.org/downloads.php) compatible parameterized model is included here along with .stl files.

**Printing Notes:**

If you are slicing the parts yourself, you will need to manually split each of the Frontplate and Backplate.  See the [FIGURE- 'Frontplate Split Example - Prusa.png'] for how to do this on the Prusa Slicer.  Other Slicers have a similar ability to slice the parts.  
In order to result in a strong combined tower part with strong lap-joints, we suggest splitting the Frontplate 104mm up from the bottom and the Backplate up 145mm).  See the two Datum planes in the FreeCad 3D model called 'Suggested Frontplate Split DatumPlane' and 'Suggested Backplate Split DatumPlane' for confimation of these cut-planes.

PLA works well for this, but PETG probably would as well. 

Recommended print settings: 2 perimeter layers, 15% infill, grid or rectilinear infill patterns.  No supports or brims should be necessary.

**Assembly Notes:**

See the [main assembly instructions](https://github.com/jamespilgrim/PiTrac/blob/main/Documentation/PiTrac%20Version%202%20Assembly.md).
Ultimately, the four parts will be glued together with something like thick, slower-drying super-glue such as Starbond Gap Filler Thick High Performance Super Glue and then screwed together with 
12 M2 x 6 self-tapping screws.

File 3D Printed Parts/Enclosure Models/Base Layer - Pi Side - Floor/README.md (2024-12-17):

**Middle  Layer – Pi Side – Floor - Description:**

Please see the main Enclosure Assembly instructions in the Documentation folder for additional information on this part.

This is the lower-right-most floor portion of the PiTrac Launch Monitor. A [FreeCAD 1.0](https://www.freecad.org/downloads.php) compatible parameterized model is included here along with .stl files. This part provides a floor to mount the Pi 2 computer component and the Camera 2. The floor mounts to the four screw holes on the tops of the mounting pads of the Base Layer – Pi Side – Wall part.

The model is parameterized for ease of modifications, though the part is complex enough that any changes can sometimes lead to issues in FreeCAD. Modifiable parameters are in the “Master Document” spreadsheet, which is assumed to be in the directory immediately above wherever this part’s FreeCAD file exists.

Please consider supporting this work and the DIY LM project here: <https://ko-fi.com/PiTrac>

**Printing Notes:**

Both PLA or PETG can work for this part. It is a fairly simple part to print successfully.

Recommended print settings: 3 perimeter layers), 15% infill, gyroid infill patterns, no supports (see Prusa Slicer .3mf file for details). Some JT16 Glu-Stick glue (or similar) is recommended to prevent pull-up and warping of the part if printing in PLA.

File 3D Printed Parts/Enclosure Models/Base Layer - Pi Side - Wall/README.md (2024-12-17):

**Base Layer – Pi Side – Wall - Description:**

Please see the main Enclosure Assembly instructions in the Documentation folder for additional information on this part.

This is the lower-right-most portion of the PiTrac Launch Monitor. A [FreeCAD 1.0](https://www.freecad.org/downloads.php) compatible parameterized model is included here along with .stl files. It provides a base for the Pi-Side (right) portion of the LM, including an area to mount LED light strips. This part of the LM houses the Pi 2 computer and the Camera 2, along with an LED Light Power Supply that screws into the bottom of this base. A nut-insert area is provided on the bottom, but is not currently used.

The model is parameterized for ease of modifications, though the part is complex enough that any changes can sometimes lead to issues in FreeCAD. Modifiable parameters are in the “Master Document” spreadsheet, which is assumed to be in the directory immediately above wherever this part’s FreeCAD file exists.

Please consider supporting this work and the DIY LM project here: <https://ko-fi.com/PiTrac>

**Printing Notes:**

The two base parts (this one included) are the most difficult to print in the entire PiTrac project. Both PLA or PETG can work for this part, though we recommend PLA. PLA is more likely to have warping issues, but is generally more forgiving, and PETG is more likely to have issues with layer separation or drooping or mis-aligned supports, which are harder to deal with.

Ensure that automatic supports in your slicer do not accidentally create supports within the screw and bolt holes and nut indents.  They can be hard to remove.  See the Prusa Slicer file’s custom support painting for how we print this part.
Recommended print settings: 4 perimeter layers (less if the bolts are not expected to be tightened very much), 15% infill, gyroid infill patterns, custom-assigned supports (see Prusa Slicer .3mf file for details). Due to potential warping issues (especially in what will be the center (left-most) portion of the print), we recommend using a glue-stick (see here) and brim assists.

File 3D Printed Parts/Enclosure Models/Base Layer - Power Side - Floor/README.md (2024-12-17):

**Base Layer – Power Side – Floor - Description:**

Please see the main Enclosure Assembly instructions in the Documentation folder for additional information on this part.

This is the lower-left-most floor portion of the PiTrac Launch Monitor. A [FreeCAD 1.0](https://www.freecad.org/downloads.php) compatible parameterized model is included here along with .stl files. This part provides a support to keep a utility power strip up off the bottom of the base as well as a wall to prevent the power supplies and associated wiring from spilling into the area on the Pi side that is reserved for the Pi Camera.

The model is parameterized for ease of modifications, though the part is complex enough that any changes can sometimes lead to issues in FreeCAD. Modifiable parameters are in the “Master Document” spreadsheet, which is assumed to be in the directory immediately above wherever this part’s FreeCAD file exists.

Please consider supporting this work and the DIY LM project here: <https://ko-fi.com/PiTrac>

**Printing Notes:**

Both PLA or PETG can work for this part. It is a fairly simple part to print successfully.

Recommended print settings: 3 perimeter layers), 15% infill, gyroid infill patterns, no supports (see Prusa Slicer .3mf file for details). Some JT16 Glu-Stick glue (or similar) is recommended to prevent pull-up and warping of the part if printing in PLA.

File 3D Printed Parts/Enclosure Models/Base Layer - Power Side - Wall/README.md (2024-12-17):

**Base Layer – Power Side – Wall - Description:**

Please see the main Enclosure Assembly instructions in the Documentation folder for additional information on this part.

This is the lower-left-most portion of the PiTrac Launch Monitor. A [FreeCAD 1.0](https://www.freecad.org/downloads.php) compatible parameterized model is included here along with .stl files. It provides a base for the Power-Side (left) portion of the LM, including an area to place a power strip and all of the required power supplies. This part of the LM may also store a small network switch to allow for a hard-line connect of the LM. A nut-insert area is provided on the bottom, but is not currently used.

**NOTE:** This part was created by taking the right-side base-layer, modifying a few things, and then creating a re-scaled, basically reversed, object. We have not figured out how to create the mirror-image part without still retaining the original part. For that reason, please ignore the right-hand-side (Pi-side) part when printing.

The model is parameterized for ease of modifications, though the part is complex enough that any changes can sometimes lead to issues in FreeCAD. Modifiable parameters are in the “Master Document” spreadsheet, which is assumed to be in the directory immediately above wherever this part’s FreeCAD file exists.

Please consider supporting this work and the DIY LM project here: <https://ko-fi.com/PiTrac>

**Printing Notes:**

Print only the body named “Base Layer - Wall - Power Side Scale”. The other body is the base part from which this mirrored-image Power-side part is created.

Ensure that automatic supports in your slicer do not accidentally create supports within the screw and bolt holes and nut indents. They can be hard to remove. See the Prusa Slicer file’s custom support painting for how we print this part.

The two base parts (this one included) are the most difficult to print in the entire PiTrac project. Both PLA or PETG can work for this part, though we recommend PLA. PLA is more likely to have warping issues, but is generally more forgiving, and PETG is more likely to have issues with layer separation or drooping or mis-aligned supports, which are harder to deal with.

Recommended print settings: 4 perimeter layers (less if the bolts are not expected to be tightened very much), 15% infill, gyroid infill patterns, custom-assigned supports (see Prusa Slicer .3mf file for details). Due to potential warping issues (especially in what will be the center (left-most) portion of the print), we recommend using a glue-stick (see here) and brim assists.

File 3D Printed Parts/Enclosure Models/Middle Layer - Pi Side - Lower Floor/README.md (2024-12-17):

**Middle Layer – Pi Side – Lower Floor - Description:**

Please see the main Enclosure Assembly instructions in the Documentation folder for additional information on this part.

This is the lower floor of the middle-right-most portion of the PiTrac Launch Monitor. A [FreeCAD 1.0](https://www.freecad.org/downloads.php) compatible parameterized model is included here along with .stl files. This part provides a floor to mount the PiTrac Connector Board component and the LED Strobe assembly. The floor mounts to the four screw holes on the bottom of the bottom pads of the Middle Layer – Pi Side – Wall part.

The model is parameterized for ease of modifications, though the part is complex enough that any changes can sometimes lead to issues in FreeCAD. Modifiable parameters are in the “Master Document” spreadsheet, which is assumed to be in the directory immediately above wherever this part’s FreeCAD file exists.

Please consider supporting this work and the DIY LM project here: <https://ko-fi.com/PiTrac>

**Printing Notes:**

Both PLA or PETG can work for this part. It is a fairly simple part to print successfully.

Recommended print settings: 3 perimeter layers), 15% infill, rectilinear infill patterns, no supports (see Prusa Slicer .3mf file for details). Some JT16 Glu-Stick glue (or similar) is recommended to prevent pull-up and warping of the part if printing in PLA.

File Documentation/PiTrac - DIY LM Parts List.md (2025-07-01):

**PiTrac \- DIY LM  Parts Lists**

**Computing Hardware:**

| Quantity | Hardware | Purpose |
| :---- | :---- | :---- |
| 1 | [Raspberry Pi 5](https://www.raspberrypi.com/products/raspberry-pi-5/) and power supply, 4 GB minimum, 8 FB recommended. | Getting a bundled kit with the Pi and power supply and some other things can be economical if you don’t have any Pi-related stuff yet. |
| 1 | [MAY BE DEPRCATED SOON] Raspberry Pi 4 Model B](https://www.raspberrypi.com/products/raspberry-pi-4-model-b/) and power supply, 4 GB minimum.  It may also make sense for a little more money just to get a second Pi 5\.  PLEASE NOTE - An experimental version of a PiTrac that requires only a single Pi 5 appears to be working and the code has been checked in.  So, if you're building a new PiTrac, you probably don't need a second Pi. |  |
| 1 | [Pimoroni NVMe Base for Raspberry Pi 5 \- PIM699](https://www.adafruit.com/product/5845) ((optional, but recommended for speed and longevity). [This board](https://www.amazon.com/gp/product/B0CQ4D2C9S/ref=ppx_yo_dt_b_search_asin_title?ie=UTF8&psc=1) or the 
Geekworm M901 PCIe to M.2 HAT Key-M NVMe SSD PIP PCIe Peripheral Board for Raspberry Pi 5 Support M.2 2230/2242/2260/2280 SSD works well, too.  Whatever you use, try to get one that leaves access for jumpers into the GPIO pins. | For the Pi 5, this allows use of an NVMe memory drive instead of an MicroSD card. |
| 1 | An [NVMe solid state (SSD) memory drive](https://www.amazon.com/gp/product/B0BGFRZDTB/ref=ppx_yo_dt_b_search_asin_title?ie=UTF8&psc=1) (optional, but recommended for speed and longevity) | Typically with an M.2 M key edge connector, in the 2230 and 2242 form factors.  Should probably get at least 256 GB capacity. |
| 2 | Micro SD cards (to bootstrap the Pi’s). | We recommend 64GB size |
| 1 | An Active Cooler fan for the Pi 5 (optional) | The Pi 5 can get pretty hot if you’re doing a lot of big compiles on it.  If so, having a cooler seems like decent insurance. |

**Hardware \- Bolts and Nuts:[^1]**

| Quantity | Hardware | Purpose |
| :---- | :---- | :---- |
| 4 | M4 x 12 screws | LED Power supply hold-downs |
|  |  |  |
| 4 | 2.5M x 12mm bolt | Pi 1 Board Bolt-down |
| 4 | 2.5 Hex Nuts | Pi 1 Board Bolt-down |
| 3 | 2.5M x 10mm bolt | Pi 2 Board Bolt-down |
| 1 | 2.5M x 12mm bolt (odd one\!) | Pi 2 Board Bolt-down |
|  |  |  |
| 2 x 4 | 2.5M x 16mm 2.5 Hex Nuts | Pi Camera Attachment Bolts (to back plate) |
| 3 x 2 3 x 2 | M4 x 12mm  M4 Hex Nuts  | Pi Cam Gimbal Attachment Hinge (2 cameras and strobe gimbal) |
| 2 x 1 2 x 1 | M5 x 12 M5 Hex Nut | Pi Cam (Pan) Swivel Mount (on bottom of mount) |
|  |  |  |
| 3 x 2 | M3 | Horizontal Center-Side Body Attachment |
| 4 | 2.5 x 10 or 12 | Connector Board Bolt-down |
| 3 x 6 \= 18 | M3 x 10mm | Floor hold-down screws |
|  |  |  |
| 2 x 4 | 2.5M x 12mm bolt | Connector Board Mounting Bolts |
| 2 x 4 | 2.5 Hex Nuts | Connector Board Mounting Bolts |
| 8 | M3 x 8mm | LED and LED Lens Hold-down screws |
|  |  |  |
| 2 2 | M3 x 12mm M3 Nuts | Half-Join bolts and nuts for ceiling level walls |
| 2 2 | M3 x 16mm M3 Nuts | Half-Join bolts and nuts for base and middle level walls |
| 5 x 4 | M3 x 10mm self-tapping screws | These screws secure the five “floor” components to their respective “wall” components and/or other floor components |

**Camera and Lighting Hardware:**

| 2  | [Raspberry Pi Global Shutter Camera – CS Lens Mount](https://www.adafruit.com/product/5702)&nbsp; Alternatively, the following camera also appears to work with PiTrac.  This camera should be much easier to work with than the 'official' Raspberry Pi camera, but we haven't had a chance to test it much.  Consider trying it out!  [innomaker GS Camera Module with IMX296 Mono Sensor ](https://www.amazon.com/gp/product/B093BY2TK2/ref=ewc_pr_img_1?th=1)| The cameras currently used by the LM.  The Pi cameras do not come with lenses (see below), but the Innomakers come with M12 lenses.  The M12 lenses are not tested out with PiTrac yet, but may work if the ball is close.  The Innomakers also come with a short ribbon cable to connect the Pi 5 to the camera, but it's probably only long enough to work with one of the two PiTrac cameras, so you'll want a longer one. |
| :---- | :---- | :---- |
| 1 | [Raspberry Pi 5 FPC Camera Cable \- 22-pin 0.5mm to 15-pin 1mm \- 300mm long](https://www.adafruit.com/product/5819) | The current Pi Cameras have a CSI cable that needs a conversion to fit into the smaller CSI ports on the Pi 5\.  The 200mm should probably work as well. |
|  | [200 mm Flex Cable for Pi 4](https://www.adafruit.com/product/2087) | This likely comes with most Pi Cameras, so may not be necessary |
| 2 | [6mm 3MP Wide Angle Lens for Raspberry Pi HQ Camera \- 3MP](https://www.adafruit.com/product/4563) | Wide angle lens for the Pi GS cameras (which come without a lens) |
| 1 | [1" x 1", Optical Cast Plastic IR Longpass Filter](https://www.edmundoptics.com/p/1quot-x-1quot-optical-cast-plastic-ir-longpass-filter/5421/) (1.5mm nominal thickness) | Blocks visible light below ~700nm from entering the Camera 2 sensor |
|  |  |  |
| 1 | [60 / 120 Degree LED Lens Optical Glass 44mm \+ Reflector Collimator \+ Fixed Bracket for 20W 30W 50W 100W COB High Power Chip (60Degree 100W len kit)](https://www.amazon.com/dp/B09XK7QTV5?ref=ppx_yo2ov_dt_b_fed_asin_title) \Consider getting both a 60 an 120-degree lens for flexibility. | The lens helps focus the infrared IR light. |
| 1 | [High Power LED Chip IR 730nm (you want the 730nm) 850nm 940nm 3W 5W 10W 20W 30W 50W 100W COB Integrated Matrix Light Beads for Night Vision Camera (Select the 730NM, 100W 1Pieces)](https://www.amazon.com/dp/B09DNRT2R4?ref=ppx_yo2ov_dt_b_product_details&th=1)  | The 730nm IR Led used for strobe light.  NOTE \- this device can get very hot if left constantly on for even a few seconds.  PiTrac just uses it in short pulses. |
| 1 | [Aclorol USB COB LED Strip Lights for TV 5V USB Powered LED Tape Lights Daylight White 6.56FT 320Leds/M 6000K COB Flexible Light Strip TV Led Backlight for Bedroom Under Cabinet Kitchen DIY](https://www.amazon.com/Aclorol-Powered-Daylight-Flexible-Backlight/dp/B0D1FYV3LM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) | LED strip for lighting the teed-up ball- long enough to double it for more light. 
NOTE - The Strip should produce NO infrared light, or else it will interfere with the IR strobing that the system uses.
|

**Power-Related Parts:**

| 1 | RECOMMENDED NOW: At this point in time, it's probably safe (and better) to get a higher-power LED driver that can over-voltage the LED.  For example, [a 3000mA 18-39V 120W driver](https://www.aliexpress.com/i/2251832563139779.html?gatewayAdapt=4itemAdapt) | Driver for LED strobe array. Because of the short pulses that are used in the LM, a much smaller (and cheaper) driver may also work, possibly even a non-constant-current driver. ORIGINAL VERSION:  LED Driver, 12-26V, Output Current DC 3600mA, such as: https://www.aliexpress.us/item/2251832563139779.html NOTE - Also need a power-plug for some of these drivers that just come with power wires.  For the US, see, e.g., [this](https://www.amazon.com/sspa/click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)  |
| :---- | :---- | :---- |
| 1 | A 5V USB-B power supply with a male micro USB connector  | This is currently necessary to run the Connectro Board.  The supply is used as an isolated, independent (downstream of a transformer) power plane to try to keep the Pi’s and the Pi Camera safe. |
|  |  |  |

**Connector Board Parts:**

| Item | Qty | Reference(s) | Value | LibPart | Footprint / Details |  |
| :---- | :---- | :---- | :---- | :---- | :---- | ----- |
| 1 | 1 | J3 | \~ | [USB B Micro Female Pinboard](https://www.amazon.com/Pinboard-MELIFE-Interface-Adapter-Breakout/dp/B07W6T97HZ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) | The included Pin headers can be used for the parts below |  |
| 2 | 2 | R1, R4 | 330 ohm R | Resistor A decent assortment kit is [here](https://www.amazon.com/gp/product/B003UC4FSS/ref=ppx_yo_dt_b_search_asin_title?ie=UTF8&psc=1) | Resistor\_THT:R\_Axial\_DIN0207\_L6.3mm\_D2.5mm\_P10.16mm\_Horizontal |  |
| 3 | 2 | R2, R3 | 270 ohm R | Resistor | Resistor\_THT:R\_Axial\_DIN0207\_L6.3mm\_D2.5mm\_P10.16mm\_Horizontal |  |
| 5 | 1 | Sys1\_Conn1 | \~ | 4 Pin Header | Connector\_PinHeader\_2.54mm:PinHeader\_1x04\_P2.54mm\_Vertical |  |
| 6 | 1 | Sys2\_Conn1 | \~ | 3 Pin Header | Connector\_PinHeader\_2.54mm:PinHeader\_1x03\_P2.54mm\_Vertical |  |
| 7 | 2 | U2, U3 | H11L1 | [Isolator:H11L1]([https://www.amazon.com/dp/B09KM2BJCF?ref_=pe_386300_442618370_TE_sc_as_ri_0](https://www.amazon.com/10PCS-H11L1M-Photoelectric-Coupler-Optocoupler/dp/B09PK3V339)) | Package\_DIP:DIP-6\_W7.62mm. NOTE: Make sure you get the DIP pin style, NOT the shorter surface-mount style.  The Connector Board is setup for through-hole pins, not surface mounting. |  |
| 8 | 1 | U4 | 74HC04 | 74xx:74HC04 | Package\_DIP:DIP-14\_W7.62mm\_Socket |  |
| 9 | 1 | U5 | \~ | [Dual\_Mos\_Driver\_Module](https://www.amazon.com/Anmbest-High-Power-Adjustment-Electronic-Brightness/dp/B07NWD8W26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) | Verdant\_Custom\_Footprint\_Library:PCB Dual MOS Driver Module |  |
|  | 1 | 2.5M Bolt 2.5M Nut |  |  | These help mechanically tie down the USB-B power connector to the board |  |
|  |  | \<Optional\> |  |  |  |  |
|  | 2 | 6 \- pin DIP socket |  | A decent assortment kit is [here](https://www.amazon.com/dp/B01GOLSUAU?ref=ppx_yo2ov_dt_b_fed_asin_title) | The opto-isolators and the hex inverter chip are probably the most likely to be blown up or injured by solder over-temps.  So best to put them in sockets |  |
|  | 1 | 14 \- pin DIP socket |  | A decent assortment kit is [here](https://www.amazon.com/dp/B01GOLSUAU?ref=ppx_yo2ov_dt_b_fed_asin_title) |  |  |

**Miscellaneous Parts/Supplies:**

| Quantity | Hardware | Purpose / Notes |
| :---- | :---- | :---- |
| 2 |  [Ideal Industries 30-102 Power Plug](https://www.amazon.com/Ideal-Industries-30-102-Power-72427/dp/B01LYF1WV9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). | Enables easy connect/disconnects |
| N/A | 3 and 4-pin ribbon cables For example, [here](https://www.amazon.com/Kidisoii-Dupont-Connector-Pre-Crimped-5P-10CM/dp/B0CCV1HVM9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). | These are used for the wiring harness connects between the various GPIO pins and the Connector Board |
| 1 | 15.5cm x 24cm plexiglass anti-ball-strike protective window | Protects the cameras and strobe **NOTE:**  Ensure the plexi is not IR-blocking\!  Most hardware stores can cut plexi in this size for a few US$ |
| 1 | Power Strip | A relatively short power strip that is compact enough to fit into the enclosure. 10” or less, and with some type of power filtering to protect the rest of the components |

[^1]:  Stainless Steel seems to be stronger than black carbon steel, though both can work.  Especially in the stiffer PLA material, stainless is preferable because black carbon can break if torqued too much..  For parts supply example see [HanTof 525 Pcs 304 Stainless Steel M2 M3 M4 Phillips Pan Head Self Tapping Wood screws Assortment Kit](https://www.googleadservices.com/pagead/aclk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)., 

**NOTE \-The following is a work in progress \- Version 2 of the Enclosure is not complete**

**Enclosure Ver. 2 \- Hardware \- Bolts and Nuts:[^2]**

| Quantity | Hardware | Purpose |
| :---- | :---- | :---- |
| 2 | M3 x 8 self-tapping screws | AC Power inlet plug (side of base box) (if using a PSU, or potentially putting a LED driver inside the basebox. |
| 2 | M3 x 8 self-tapping screws | Secures the end-cap of the base box into the rest of the box |
| 2 | M3 x 8 machine screws | Secures PSU to bottom of base box.  No PSU will generally be used if using the original Connector Board variant of the Version 2 enclosure. |
| 3 | M3 x 10 machine screws (or x 8\) | Secures PSU to the side of the base box (If using the new PiTrac Compute Board). NOTE \- in order to efficiently use screw assortment sets, either x8 or x10 screws can be used.  There is space in the PSU for either, so just use what you have more of. |
| 12 | M2 x 6 self-tapping screws | Secures and aligns the tower back and front plate parts |
| 2 x 4 | M3 x 6 self-tapping screws | Secures Pi Microcontrollers to Backplane (Only if using Compute Board variant and Pi Microcontrollers instead of Compute Modules |
| 4 | M4 x 12  self-tapping screws | Secures tower (feet) to top of base box.  Could use longer screws if they don’t interfere with the power supply. |
| 2 | Pan head M4\*12 or \*16 self-tapping screws  | For the top of the Shank Shield.  Pan-head is preferred in order to avoid countersinking, but could also use flat-head. |
| 2 | Flat head self-tapping M4\*12 or \*14 screws | For the bottom of the Shank Shield \- screws go through the front of the basebox and the shield. |
| 4 | M4 x 12 | Secures Case Cover to the top of the Basebox |
| 6 12 (variant) | Self-tapping M2.5 x 8 screws | Secure Compute Board to the Backplane of the Tower.  If using the original Connector Board and two Raspberry Pi’s, will need 12, not 6 screws. |
| 5 | Heat Shrink Ring-type Wire Connectors | [Ring connectors](https://www.amazon.com/dp/B0CYM3J44Q?ref=ppx_yo2ov_dt_b_fed_asin_title&th=1) to connect the various power supply wires to the screw terminals of the PSU. |

**Enclosure Ver. 2 \- Components (WORK IN PROGRESS)**

| 1 | AC 250V 15A IEC320 C14 Male Power Cord Inlet Socket with Fuse Holder,3Pin Inlet Module Power Connector Socket with 3pcs Wires | [AC Power inlet plug](https://www.amazon.com/IEC320-Socket-Holder-Module-Connector/dp/B081ZFHRGW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) (for the side of base box)  (when using a PSU, or potentially putting a LED driver inside the basebox. |
| :---- | :---- | :---- |
| 1 | Mean Well LRS-150-24 150W Single Output Switching Power Supply(24V 6.5A) (ONLY when we get the new PiTrac Compute Board that doesn't use AC adapters) | [150 W Power supply unit.](https://www.amazon.com/dp/B07GTY6R4H?ref=ppx_yo2ov_dt_b_fed_asin_title) |
| TBD | TBD | TBD |

[^1]:  Stainless Steel seems to be stronger than black carbon steel, though both can work.  Especially in the stiffer PLA material, stainless is preferable because black carbon can break if torqued too much..  For parts supply example see [HanTof 525 Pcs 304 Stainless Steel M2 M3 M4 Phillips Pan Head Self Tapping Wood screws Assortment Kit](https://www.googleadservices.com/pagead/aclk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)., 

[^2]:  You may choose to buy some assortment sets of screws and bolts.  That hardware on this list can be satisfied by a combination of:

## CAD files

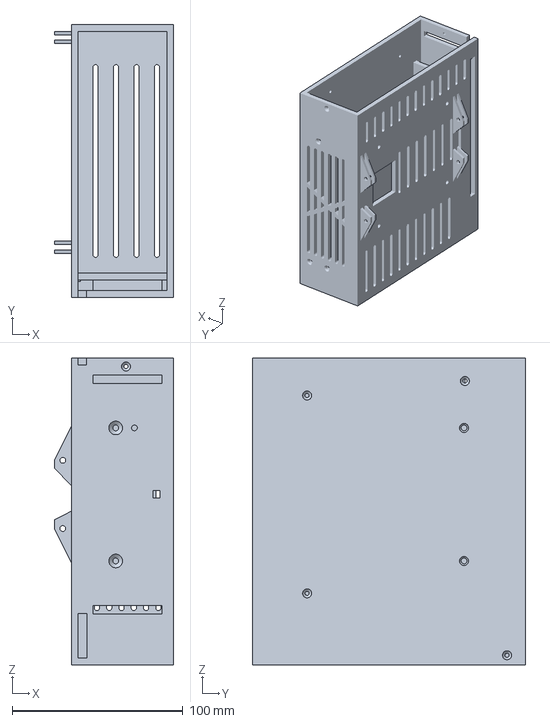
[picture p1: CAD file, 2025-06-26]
3D Printed Parts/Enclosure Version 2/BaseBox/BaseBox- Main Body.3mf
70.0 x 160.0 x 180.0 mm

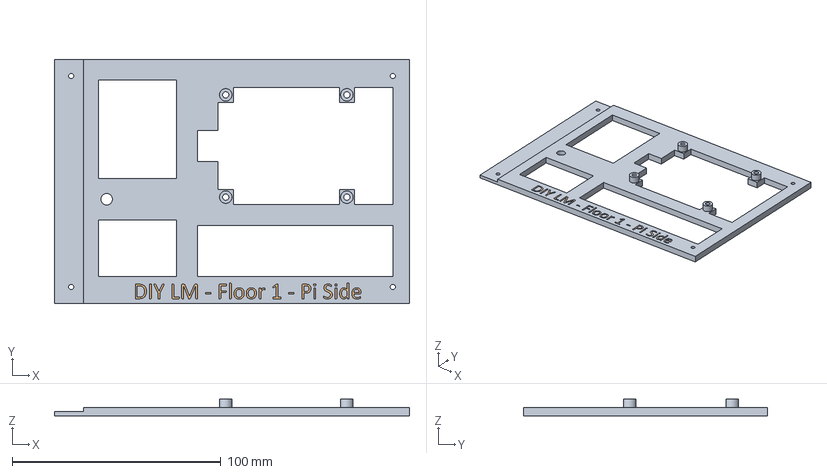
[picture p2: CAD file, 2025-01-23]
3D Printed Parts/Enclosure Models/Base Layer - Pi Side - Floor/Base Layer - Pi Side - Floor.FCStd
170.0 x 117.0 x 8.00 mm
Base Layer - Pi Side - Lower Floor Body
ShapeString001

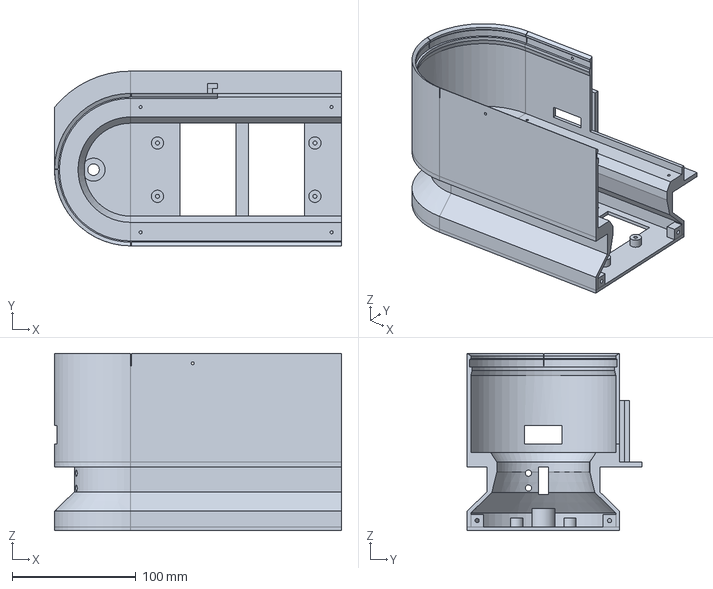
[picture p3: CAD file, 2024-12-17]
3D Printed Parts/Enclosure Models/Base Layer - Pi Side - Wall/Base Layer - Pi Side - Wall.FCStd
231.5 x 141.0 x 143.0 mm

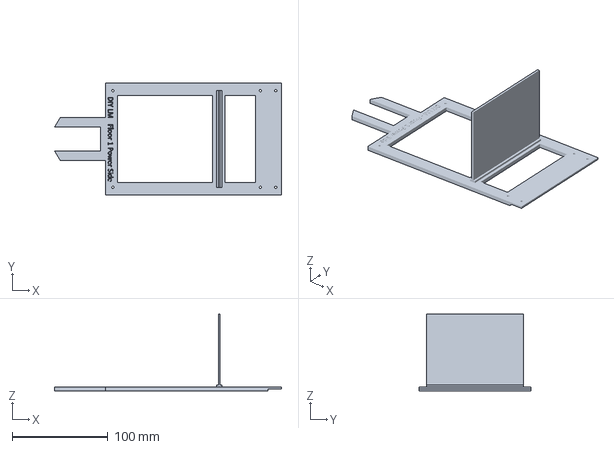
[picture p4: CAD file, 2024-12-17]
3D Printed Parts/Enclosure Models/Base Layer - Power Side - Floor/Base Layer - Power Side - Lower Floor.3mf
237.0 x 117.0 x 80.0 mm

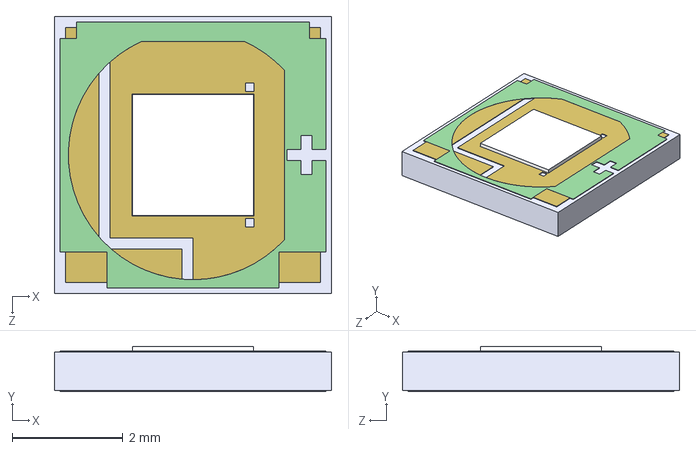
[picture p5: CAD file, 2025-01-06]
3D Printed Parts/Enclosure Models/Combined Enclosure Model (DO NOT PRINT)/Cree XLamp XM-L LED.STEP
5.00 x 0.815 x 5.00 mm

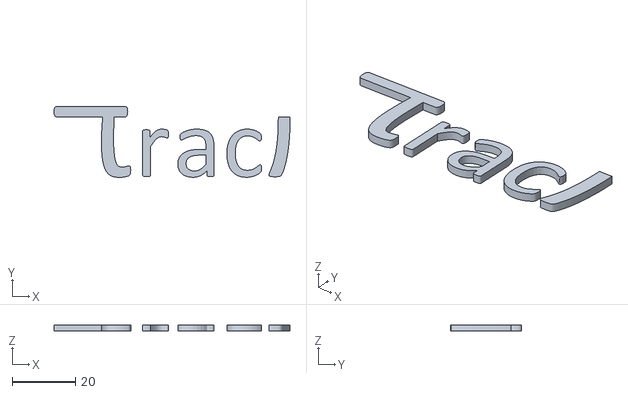
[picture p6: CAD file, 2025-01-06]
3D Printed Parts/Enclosure Models/Logo Badge/PiTrac Logo-Individual Characters Body.stl
74.5 x 22.4 x 2.00

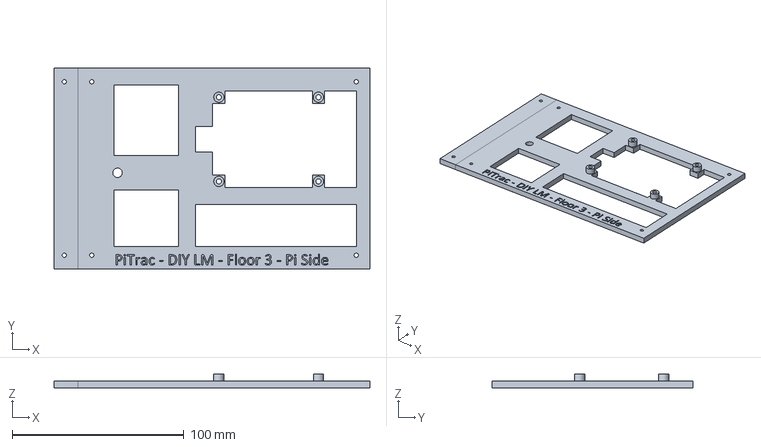
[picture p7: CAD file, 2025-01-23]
3D Printed Parts/Enclosure Models/Middle Layer - Pi Side - Upper Floor/Middle Layer - Pi Side - Upper Floor.FCStd
184.0 x 117.0 x 8.00 mm

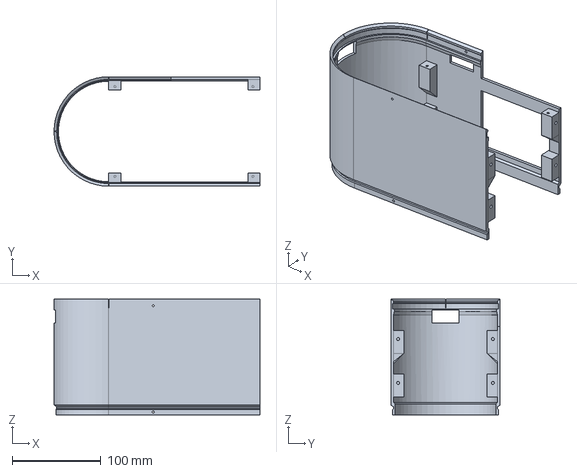
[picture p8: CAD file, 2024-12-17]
3D Printed Parts/Enclosure Models/Middle Layer - Pi Side - Wall/MIddle Layer - Pi Side - Wall.FCStd
231.5 x 123.0 x 130.0 mm

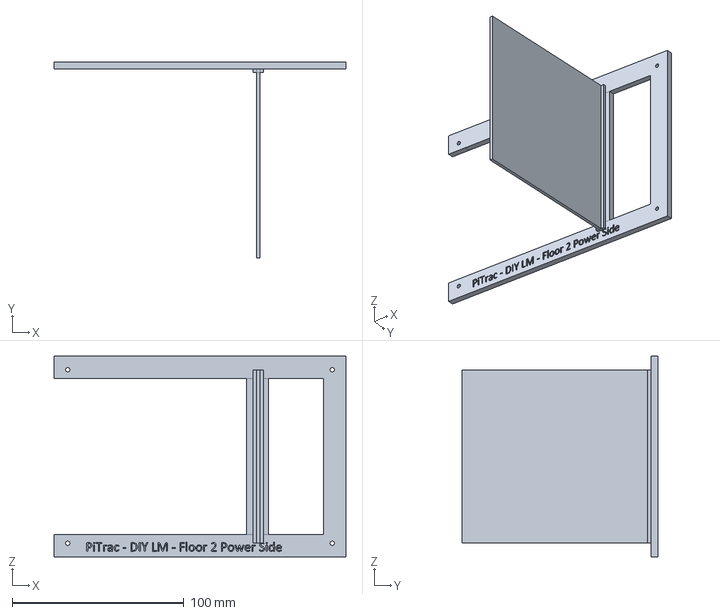
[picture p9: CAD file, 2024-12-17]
3D Printed Parts/Enclosure Models/Middle Layer - Power Side - Lower Floor/Middle Layer - Power Side - Lower Floor.FCStd
170.0 x 114.0 x 117.0 mm

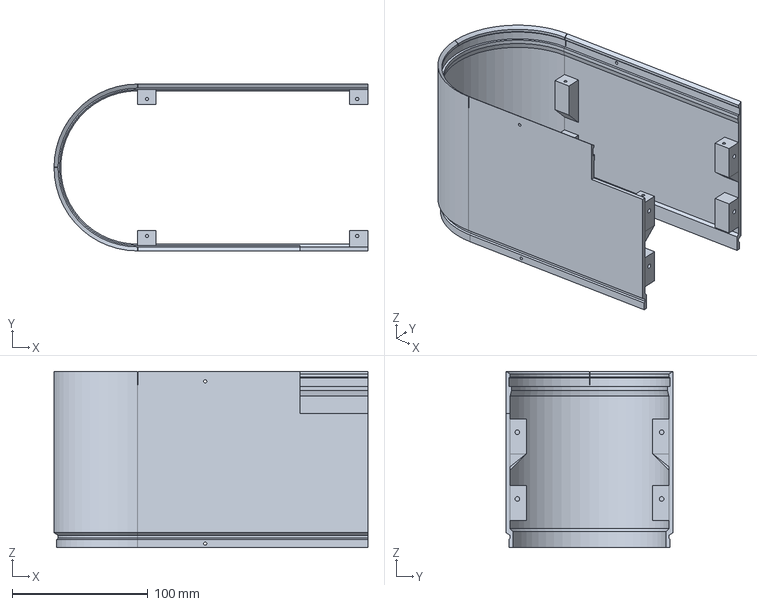
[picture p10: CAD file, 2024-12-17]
3D Printed Parts/Enclosure Models/Middle Layer - Power Side - Wall/Middle Layer - Power Side - Wall.FCStd
231.5 x 123.0 x 130.0 mm

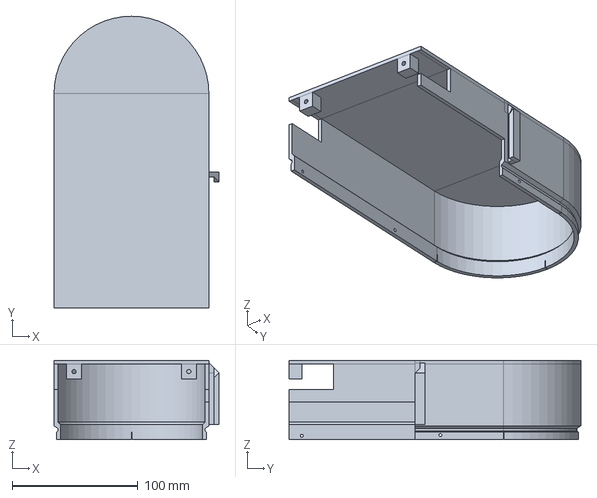
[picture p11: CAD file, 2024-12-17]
3D Printed Parts/Enclosure Models/Top Layer - Pi Side - Wall/Top Layer - Pi Side - Wall.FCStd
131.0 x 231.5 x 63.0 mm

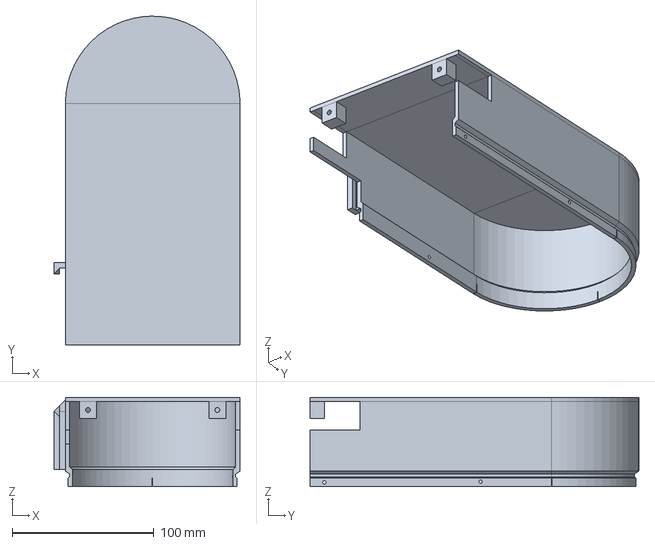
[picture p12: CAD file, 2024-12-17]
3D Printed Parts/Enclosure Models/Top Layer - Power Side - Wall/Top Layer - Power Side - Wall.FCStd
131.0 x 231.5 x 63.0 mm

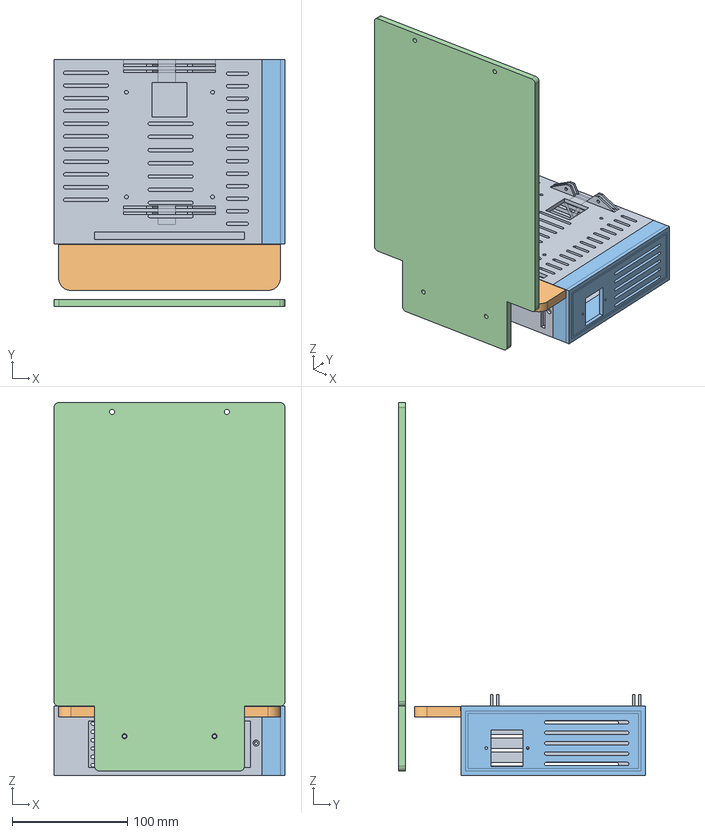
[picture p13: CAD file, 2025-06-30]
3D Printed Parts/Enclosure Version 2/BaseBox/BaseBox.FCStd
200.0 x 214.1 x 323.0 mm
BaseBox Body
Light Shield Body
Cap Body
Shank Shield Body

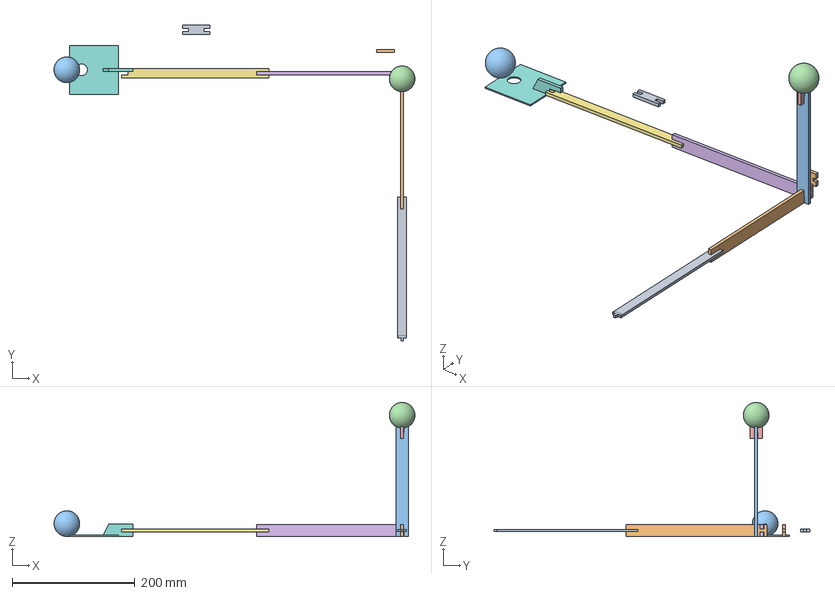
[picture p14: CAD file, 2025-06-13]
3D Printed Parts/Enclosure Version 2/Calibration Rig/CalibrationRig.FCStd
588.7 x 514.5 x 218.9 mm
Base Connection Leg Body
Z-Axis Leg Body
High Ball Holder Body
Test Golf Ball 1
High Ball Holder Cross Body
X Axis Near Leg
X Axis Far Leg
X-Axis Ball Holder Body
X Axis Far Leg Short Version
X Axis Near Leg Short Version
Test Golf Ball 2

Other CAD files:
3D Printed Parts/Enclosure Models/Base Layer - Power Side - Wall/Base Layer - Power Side - Wall.FCStd
3D Printed Parts/Enclosure Models/Master Document.FCStd
3D Printed Parts/Enclosure Models/Middle Layer - Pi Side - Lower Floor/Middle Layer - Pi Side - Lower Floor.FCStd
3D Printed Parts/Enclosure Version 2/CaseCover/CaseCover.FCStd
3D Printed Parts/Enclosure Models/Base Layer - Pi Side - Floor/Base Layer - Pi Side - Floor.3mf
3D Printed Parts/Enclosure Models/Base Layer - Pi Side - Floor/Base Layer - Pi Side - Floor.stl
3D Printed Parts/Enclosure Models/Base Layer - Pi Side - Wall/Base Layer - Pi Side - Wall.3mf
3D Printed Parts/Enclosure Models/Base Layer - Pi Side - Wall/Base Layer - Pi Side - Wall.stl
3D Printed Parts/Enclosure Models/Base Layer - Power Side - Floor/Base Layer - Power Side - Lower Floor.stl
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

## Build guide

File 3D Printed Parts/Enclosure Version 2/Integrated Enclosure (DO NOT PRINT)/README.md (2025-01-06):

DO NOT PRINT FROM THIS DIRECTORY!

Please note that this model is build using a technique where most of the parts are symbolic links to the individual 3D part models in the sibling directories.  This makes the model pretty fragile, but this is the best practice we've developed so far to avoid making copies of the individual parts.

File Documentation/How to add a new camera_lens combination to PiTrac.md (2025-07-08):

**How to add a new camera/lens combination to PiTrac**

This document describes how to add a new camera type and/or a new lens type to the PiTrac source code so that the system will behave in a (hopefully) optimal manner with that equipment.  For our example, we will be adding a new combination of an Innomaker GS camera with a 3.6 focal length M12 lens.

1. Make sure you have your own github “fork”.  A fork will allow you to make changes and then make a push request (PR) to have those changes checked into the main github repository so that everyone can benefit.  
2. Check out the latest source code in your fork.   Usually, just go to wherever your forked source code resides and execute:   git pull  
3. Edit the file camera\_hardware.h and add a new camera/lens combination with a new (and next-highest) ordinal number (emphasized part is new).  
   1.   
   2.             enum CameraModel {  
   3.                 PiCam13 \= 1,  
   4.                 PiCam2 \= 2,  
   5.                 PiHQCam6mmWideLens \= 3,  
   6.                 PiGSCam6mmWideLens \= 4,  
   7.                 PiGSCam3\_6mmLens \= 5,  
   8.                 **InnoMakerIMX296GS3\_6mmM12Lens \= 6,**  
   9.                 kUnknown \= 100  
   10.             };  
4. Add a corresponding line in the camera\_hardware.cpp file:  
   1.   
   2.         std::map\<std::string, int\> camera\_table \=  
   3.         { { "1", CameraModel::PiCam13 },  
   4.             { "2", CameraModel::PiCam2 },  
   5.             { "3", CameraModel::PiHQCam6mmWideLens },  
   6.             { "4", CameraModel::PiGSCam6mmWideLens },  
   7.             { "5", CameraModel::PiGSCam3\_6mmLens },  
   8.             **{ "6", CameraModel::InnoMakerIMX296GS3\_6mmM12Lens },**  
   9.             { "100", CameraModel::kUnknown },  
   10.         };  
5. Add whatever code is necessary to setup the camera’s member parameter values in the camera\_hardware.cpp file’s CameraHardware::init\_camera\_parameters method.  Typically, this will be the focal length, resolution, whether it is a monochrome camera, and importantly, the expected\_ball\_radius\_pixels\_at\_40cm\_ value.  That value can be determined by running rpicam-still of a ball at that distance from the camera.  This value helps the system to pick a reasonable range of ball radii when searching for ball circles.    
6. Most of the code will probably be taken care of by a similar camera, so you can just piggy-back on that code by adding your camera as a potential alternative in an OR statement:  
   1.         // This section deals with the common characteristics of some of the cameras  
   2.         if (model \== PiGSCam6mmWideLens **|| model \== InnoMakerIMX296GS3\_6mmM12Lens**) {  
7. Otherwise, add your specifics prior to the common code:  
   1.         **if (model \== InnoMakerIMX296GS3\_6mmM12Lens) {**  
   2.             **focal\_length\_ \= 3.6f;**  
   3.             **horizontalFoV\_ \= 70.0f;**  
   4.             **verticalFoV\_ \= 70.0f;**  
   5.             **is\_mono\_camera\_ \= true;**  
   6.             **expected\_ball\_radius\_pixels\_at\_40cm\_ \= 57;**  
   7.         **}**  
8. Recompile (ninja) and then setup your environment variables (typically in .basrc or .zshrc) to reference the new ordinal number, e.g.:  
   1. PITRAC\_SLOT1\_CAMERA\_TYPE=6  
   2. PITRAC\_SLOT2\_CAMERA\_TYPE=6

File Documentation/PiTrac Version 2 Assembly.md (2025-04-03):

**The PiTrac Assembly Guide - Version 2**

Overview:  
This document explains the process of building a typical PiTrac DIY Launch Monitor (LM) using the Version 2 Enclosure and the new PiTrac Compute Board.  This process includes the assembly of all of the physical components, including the 3D-printed parts and hardware, such as cameras and Raspberry Pi computers.  Detailed printing instructions for the 3D parts are contained in the directories that have the respective part files.  Instructions for certain stand-alone sub-assemblies such as the camera mounts are contained in separate documents, but linked to from this main document.  Instructions for the software components of the LM are separate and available [here](https://github.com/jamespilgrim/PiTrac/blob/main/Documentation/Raspberry%20Pi%20Setup%20and%20Configuration.md).

TBD - This is just a placeholder document for now - Please ignore.

New Material for Enclosure 2:
Tower Construction
Screw the M2x6 self-tapping screws into the back plate just far enough so that a little of the tip of the screw goes beyond the other side.
WARNING - These little screws are delicate (especially if carbon steel), so don't over-tighten
The screws will act to help register the back plate and front plate halves of the parts of the tower.
Use thick, slower-drying super-glue such as Starbond Gap Filler Thick High Performance Super Glue to glue the halves together
The tower halves do not always have material in the same places, so take care not to add glue to portions of one half that will not be adjacent to the other half.
NOTE - make sure that the bottoms of the halves (especially for the base parts) are well-registered so that the completed, glued tower will sit and attach flat to the base box.
<PICTURES>
Use clamps judiciously to make sure the parts are glued securely
Tight the screws through the two sides as you work your way up the tower

Shank Shield Installation
2 x Pan head M4*12 or *16 self-tapping screws for the top of the shield (avoid counter-sinking, but could also use flat-head)
2 x flat head self-tapping M4*12 or *14 screws for the bottom of the shield
Put the shield in place and mark where the upper-left hold should be that goes into the top-left riser of the tower frontplate
Drill a hole in the shield using a 5/32" drill bit or something else that is very nearly as wide as the screw threads
WARNING - it's very easy to shatter or chip the shield when screwing in the screws.  For that reason, the holes must be nearly as large (or even larger) than the screws.  This may compromise the rigidity of the lower-shield mount, but better than a cracked shield.
WARNING - Plexiglas or polycarbonite is very sharp.  Make sure you sand everything.
Mount the shield using just the top-left screw.  Using a 1/8" (or other small bit), drill through the sheild in the top-right where tthe shield will mount into the top-right tower riser.  
Drill (straigh) through the two counter-sunk shield-securing holes in the front of the base-box.  The reasons for using the smaller bit is sot that there is enough plastic in the basebox hole to tightly grip the screw.
Unattach the shield, put it on something you can drill into, and drill out the three new holes with a 5/32" drill.
Attach the shield using the four screws listed above.

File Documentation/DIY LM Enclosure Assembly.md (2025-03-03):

**The PiTrac Assembly Guide**

Overview:  
This document explains the process of building a typical PiTrac DIY Launch Monitor (LM).  This process includes the assembly of all of the physical components, including the 3D-printed parts and hardware, such as cameras and Raspberry Pi computers.  Detailed printing instructions for the 3D parts are contained in the directories that have the respective part files.  Instructions for certain stand-alone sub-assemblies such as the camera mounts are contained in separate documents, but linked to from this main document.  Instructions for the software components of the LM are separate and available [here](https://github.com/jamespilgrim/PiTrac/blob/main/Documentation/Raspberry%20Pi%20Setup%20and%20Configuration.md).

This document also refers to the calibration steps for the camera sub-system, which should be consulted prior to building the enclosure.  This calibration is most easily done *as the LM is being assembled*, because doing so allows for easier access to the cameras and camera mounts before the LM is completed.  The calibration process can be found [here](https://github.com/jamespilgrim/PiTrac/blob/main/Documentation/PiTrac%20-%20Camera%20Calibration.zip).

At least currently, the LM is not a simple, complete kit that just requires attaching Part A to Part B.  Instead, it’s a general design for an LM that we hope the builder will customize, adapt and improve depending on their own goals and skills.  The particular parts referenced here may not even be available when someone builds the LM. For that reason, this document is less of a plan and more of a guide for building what is expected to be a ‘typical’ PiTrac LM.  The authors hope that the individual creativity, and ingenuity of the builders will help improve PiTrac and help it continue to evolve.

Conventions:  
Any references to left/right/back/front in this document are by default referring to the LM as it faces the user, with the camera side toward the builder.  “Pi-side” refers to the right half where the Pi’s, cameras, and the Connector Board are placed.  “Power side” refers to the left side where the power adapters and cables are contained.

The 3D parts are named using a house analogy.  The curved parts that make up the outside of the LM are referred to as walls.  The flat horizontal parts that will be mounted within those walls are called floors.  Some additional terminology is shown below:  


Tools Needed:

1. M2.5, M3, M4, and M5 hex wrenches.  Right-angle wrenches as well as straight (screw-driver-type) wrenches are helpful.  
2. Needle-nose pliers.  
3. Medium-sized Phillips screwdriver, at least a 6” length  
4. Soldering tools  
5. Wiring tools such as wire strippers, clippers, and anything necessary to build custom wiring harnesses  
   1. If custom-making the harnesses ribbon cable, a pin connector kit, crimping tool, etc.  
6. Optional:  
   1. A magnifying, lighted headband and/or a magnifying desk light  
   2. A Dremel tool can come in handy for trimming parts if needed.  
   3. A soft/hard rubber hammer or mallet.  Because sometimes things need a little gentle persuasion.

Parts  and Materials:

1. See the [parts list document](https://github.com/jamespilgrim/PiTrac/blob/main/Documentation/PiTrac%20-%20DIY%20LM%20%20Parts%20List.md) for a full list of parts, including all of the bolts and screws  
2. The 3D-printed parts that make up the enclosure (of course).  
3. Solder, flux, flux-cleaner  
4. Wires.    
   1. We use stereo-speaker wire for higher-voltage portions of the system and whenever keeping the two \+/i wires together for most of the wire-run is helpful.  
5. Optional:  
   1. Sand paper, sanding block  
   2. To use as a contrasting backdrop, a half-dozen (or so) square feet of non-IR-reflective cloth material, such as most black felts  
      1. You’ll have to experiment with what types of cloth show up as black when lit with IR light.  Some cloth that appears black to the eye actually looks white in IR light, which makes a poor-contrasting backdrop with a white-colored ball.

Assembly Instructions:

1. Printing the Enclosure Components  
   1. First, see the individual printing and assembly instructions for each of the 3D parts that make up the LM, [here](https://github.com/jamespilgrim/PiTrac/tree/main/3D%20Printed%20Parts/Enclosure%20Models). The 3D printing is a multi-day project in itself due to the size of some of the parts.  
   2. If possible, having the hardware components that you expect to use in hand ***before*** printing the parts will allow you to customize the part models as necessary to fit those parts.  For example, if your LED power supply is different from the one used by the authors, you’ll want to customize the mounting risers and holes on the Pi-Side Base layer to accommodate it.  
2. Base Layer (the part of the LM that touches the ground\!\!)  
   1. Overview  
      1. Several parts such as the LED power supply will be placed in the lowest section of each of two Base Layer wall parts first.  Then, the two base wall parts are connected together in the middle.  The camera assembly and Pi 2 are then attached to the Pi-side Floor.  Finally, the Pi-side and power-side floors are screwed into the mounting risers on the inside of the walls.  
   2. Wall Halves and Lower Component Bays (the areas just above the floor)  
      1. Before putting anything in the base bays, place two M3 nuts into the indents on the Pi-side half-join pads while there is still room to do so.  If tight, the nuts can be pulled into the indents by using a temporary bolt from the outside.  A little temporary scotch tape really helps hold the nuts in.  
      2. It’s easier to install the LED supply before the two bottom wall halves are joined.  The part is typically heavy, so best to keep it low in the enclosure.   
      3. Place the LED power supply in the right-hand half and secure to the risers on the floor with four M4 x 12 screws.  The design is set up to accommodate [this supply](https://www.aliexpress.us/item/2251832563139779.html), though others should work.  Different supplies will require different distances between the LED supply riser mounts, of course.    
      4. The output wires of the supply should have a quick-connect to make it easier to connect to the Connector Board later.  Make sure the polarity of the two wires is clearly marked.  Putting polarity markings on the quick-connect helps.  The input should have a 3-prong plug that can be plugged into a utility strip on the power-side of the LM.    
      5. If your network switch will fit and still allow for cable connections, place it in the Power-side bay now.  One cable will be routed out the back of the LM, and two cables will lead from the switch over to the Pi’s on the right side of the LM.  
         1. It may be easier to lay down two Cat-5/6 cables through the Pi-Side bay now rather than after the floor is attached.  They may be threaded between the LED power supply and the base floor later (see completed Base Layer, below)  
      6. Join the two base halves using two pairs of M3 x 16mm bolts and nuts.  
   3. External (Tee-up) LED lighting  
      1. Install LED lighting under the overhang near the bottom of the Base Layer.  This lighting helps the high-FPS camera 1 see the ball more clearly despite the short shutter speeds.  This can be done after mounting the floors, but it’s more difficult.  However, the pictures below show the LED strips being installed after the floor.  Because we messed up.  
      2. If you’re using [the same LED strips we are](https://www.amazon.com/Aclorol-Powered-Daylight-Flexible-Backlight/dp/B0D1FYV3LM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), it’s best to make it brighter by using two levels of stripping.  To do this, start by tacking down one end of the strip on the left-side of the Base Layer under the overhang.  Position it so the end goes inside the LED light port by a few inches     
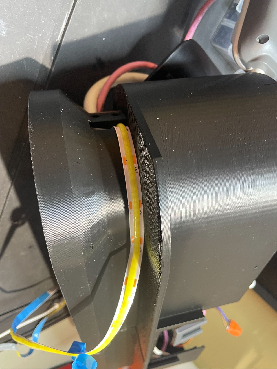
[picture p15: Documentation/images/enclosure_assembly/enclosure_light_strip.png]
      3.   
      4. Then, remove the sticky backing and stick one layer down just below the overhang, making a small, loose bend that is pushed about 4 inches into the right-hand LED port.  Stick down the next layer of the strip just below the first layer so that there are two rows of LED lights under the overhang.  
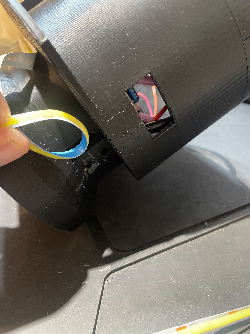
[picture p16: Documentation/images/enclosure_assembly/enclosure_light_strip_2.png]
      5.  
      6. Pull the end of the LED strip that has the USB (or whatever) power plug through the left-most LED port.  This end will either plug into the power strip within the PiTrac, or (usually better), will be pulled back out the back port that has the main power cable and the network cable.  Doing so allows the power to stay on to the Pis and the rest of the monitor, but the LED strip can be turned off when the ball is not actively being hit.  It’s quite bright and can get warm, so it’s nice to be able to turn it off.  
      7. Use the two small holes at the ends of the Base Layers to thread zip-ties through.  Use the zip-ties to (lightly) secure the ends of strips.  If your LED strip is super-sticky, you may not need the zip-ties.  
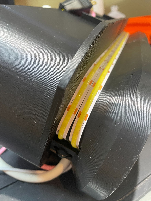
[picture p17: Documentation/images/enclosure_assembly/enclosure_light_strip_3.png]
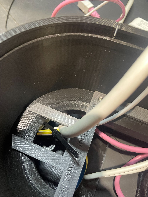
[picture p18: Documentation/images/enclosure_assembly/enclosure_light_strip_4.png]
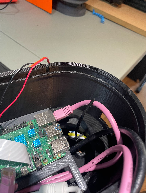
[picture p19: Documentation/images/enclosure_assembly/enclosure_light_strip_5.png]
      8.   
   4. Camera 2 (the camera on the bottom that takes pictures of the ball in flight)  
      1. Camera modifications  
         1. First, one [GS camera](https://www.raspberrypi.com/products/raspberry-pi-global-shutter-camera/) has to be modified to (1) use IR light instead of visible light, and (2) to allow for external triggering of its shutter .    
            1. **WARNING** \- these modifications will void the warranty on the camera.  They are also pretty delicate, and can wreck the camera if performed incorrectly  
         2. Remove the internal IR filter that would otherwise keep any IR light from entering the sensor.  Use [official instructions here](https://www.raspberrypi.com/documentation/accessories/camera.html#filter-removal).  
         3. Modify the Global GS Camera to accept external triggering.  Use the [instructions from RPi](https://github.com/raspberrypi/documentation/blob/develop/documentation/asciidoc/accessories/camera/external_trigger.adoc) as a guideline. The removal of the resistor is a particularly difficult step, and you’ll want to use a good magnifying work light and some steady hands\!  
         4. Because you’ll likely be connecting and disconnecting the camera several times, use wires with jumper pin ends (or other quick-connect devices) to make the process easier.    
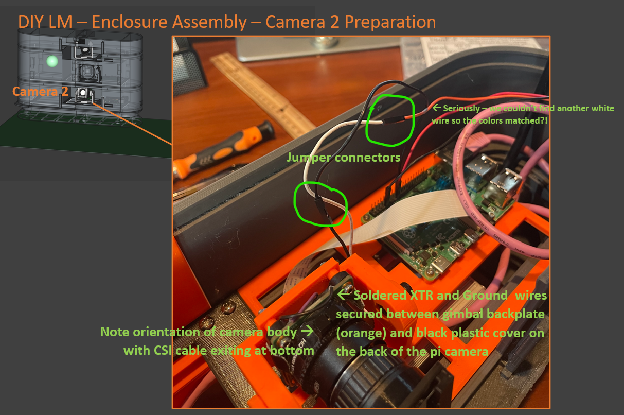
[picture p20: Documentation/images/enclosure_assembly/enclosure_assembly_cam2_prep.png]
         5.  
         6. This is the most delicate part of the entire DIY LM assembly process, so work slowly.  Removing the extra resistor is especially difficult, so consider practicing first on an old surface-mount PCB that you don’t use any more. (doesn’t everyone have those?:)  
         7. Once the XTR and GND wires are soldered to the board, add a small drop of thick glue over the wire and solder to help act as a strain relief.  Also for strain relief, we ran the wires down from the top of the camera (see picture above) and gently pinched the wires between the camera and the backplate of the camera gimbal assembly.  Doing so protects the wires a bit by having them come out near the bottom of the gimbal away from other things they might snag on.  
      2. Assemble the Pi GS Camera and its gimbal camera mount for the bottom camera 2  
         1. NOTE:  The bottom camera mount is shorter than the top camera mount because the bottom camera (camera 2\) does not need to point downward  
         2. Use the instructions in the Camera Mount sub-project’s README.md file [here](https://github.com/jamespilgrim/PiTrac/tree/main/3D%20Printed%20Parts/Enclosure%20Models/Pi-Camera-Mounts).  
      3. Mounting the camera to the gimbal  
         1. It is easier to attach the camera CSI cable ***before*** bolting the camera to the camera assembly’s backplate.  Make sure the cable-lock is locked on the camera so that the ribbon cable doesn’t fall out..  
         2. Carefully thread the CSI ribbon cable out the back of the camera mount making sure it does not get pinched between the backplate and the gimbal mounting base.  
      4. Add visible-light cut filter  
         1. Assemble the filter holder by gluing the two parts of the filter together using the registration wings to position the two parts together.:  
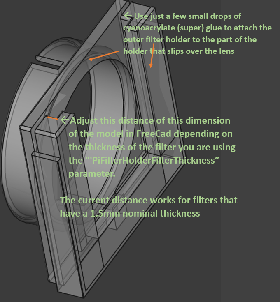
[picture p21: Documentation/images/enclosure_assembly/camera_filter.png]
         2.  
         3. See instructions [here](https://github.com/jamespilgrim/PiTrac/tree/main/3D%20Printed%20Parts/Enclosure%20Models/Pi-Camera-Light-Filter-Holder).   
         4. Insert the visible light-cut filter and attach the holder to the lens with the opening at the top so the filter doesn’t drop out  
   5. Pi-side Base Layer Floor  
      1. NOTE:  The two floors holding the RPis are similar.  Double check the labeling on the part to ensure the correct floor is used in each step  
      2. Mount Camera 2 on Floor 1 using an M5 bolt and nut.  It’s best to have the CSI cable and GND and XTR (external trigger) wires all in place and secure before mounting.  
      3. Mount the Pi 4 (a 5 works, too) on the right side of Floor 1 using 4 M2.5 x 12 bolts and nuts, with the nuts on the bottom side.  Put the Micro-SD card (if used) in place beforehand when it’s more accessible.    
      4. Connect the camera’s flat CSI cable to the Pi.  
      5. Connect the camera’s GND to pin 9 of the Pi.  
      6. Create the Pi 2-to-Connector-Board ribbon cable and plug it in  
         1. To do so, fashion a three-wire ribbon cable harness with female plugs on each end.  If possible, have a black and a red wire, with the third wire for the Camera 2 XTR.  See the lower half of this photo for finished wiring:  
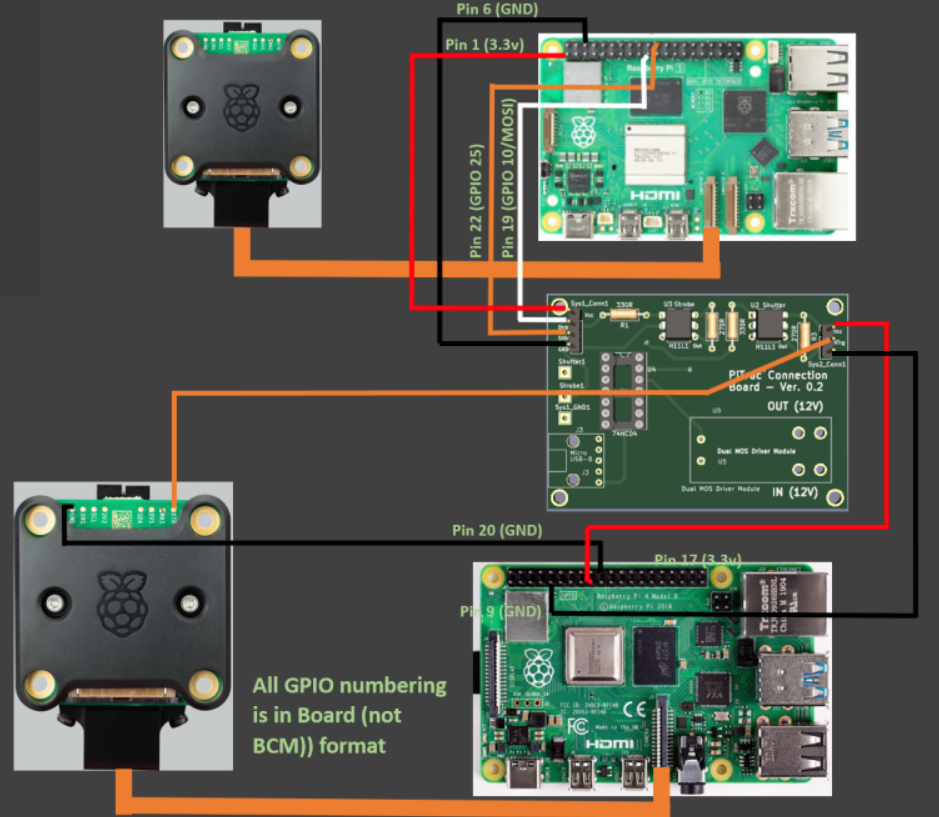
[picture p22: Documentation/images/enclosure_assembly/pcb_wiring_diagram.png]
         2. 
         3. NOTE \- Low-quality wiring harnesses in this part of the build can lead to random, difficult-to-diagnose problems later.  Make sure that the wiring harnesses will connect firmly and without any play to the pins on the Connector Board.  Making the cables a little longer than necessary also makes life easier.  
         4. Pre-crimped ribbon cable parts are by far easier to use than having to solder your own.  See [here](https://www.amazon.com/Kidisoii-Dupont-Connector-Pre-Crimped-5P-10CM/dp/B0CCV1HVM9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) for an example assortment kit.  
         5. An example (with more intermediate connectors than necessary) is:  
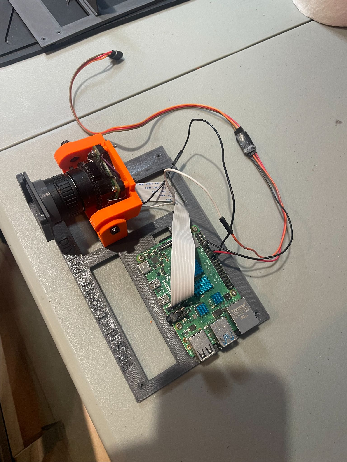
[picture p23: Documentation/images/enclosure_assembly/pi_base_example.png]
         6.  
   6. Joining the two Base Layer Floor halves  
      1. The two base-floor halves join in an overlapping lap joint in the middle.  The lap joint helps secure the two halves of the LM together.  
      2. Ensure that any printing supports on the power-side floor lap joint are removed and that the joint is smooth and will mate well with the pi-side floor.  A careful belt-sanding may help.  
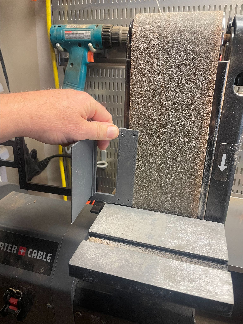
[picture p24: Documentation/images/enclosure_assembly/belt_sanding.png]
      3. 
      4. Start by screwing 6 M3 x 10mm screws a few turns into the 4 holes on the power-side floor and the right-most (outside) 2 holes on the Pi-side floor.  It’s easier than placing them later  
      5. Slip the lap joint of the Power-side floor between the camera base and the lap joint of the Pi-side floor so that the right-most screws of the power-side are aligned with the left-most two holes on the Pi-side.  It will likely be a little tight.  Screw just the two screws in the overlapping holes so that the two sides are held (barely) together.  This process is easier than trying to join the two floors after they are both placed inside the base walls.  
      6. Set the tenuously-joined Pi-side Floor 1 and Pi-side Floor into the joined Base-Layer walls, with the Pi on the right..  The lap-joint (and two screw holes) should be aligned in the middle.   
      7. Screw the floors into the mounting pads on the side of the walls using M3 x 10mm screws.  Note that the two screws on the lap joint go through both floors and into the side pads of the Pi-side wall.  
      8. Make sure any cables you will need later such as network cables are not trapped or pinched.  Also make sure the LED Power Supply power cable is accessible on the left side.  
      9. The joined base layer assembly will look like:  
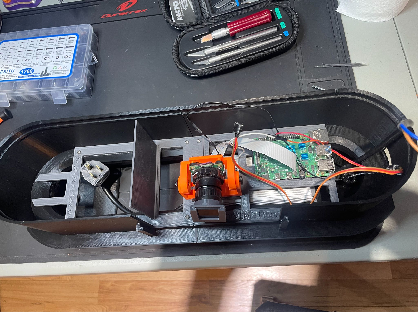
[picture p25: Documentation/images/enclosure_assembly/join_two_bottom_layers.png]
      10. 
   7. Completing the Base Layer  
      1. Run the power cable from whatever power-strip will be used down through the left-most power-strip support and down and out the hole on the power-side base.  This is usually a tight fit, so do it first.  
      2. Route a power cable from the Pi power supply to the Pi 2 computer board.  It may be a little tight with the network cables.  
      3. Route one of the network cables to the Pi.  
      4. The completed Base (lowest) Layer should look similar to:  
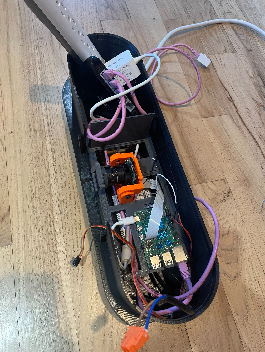
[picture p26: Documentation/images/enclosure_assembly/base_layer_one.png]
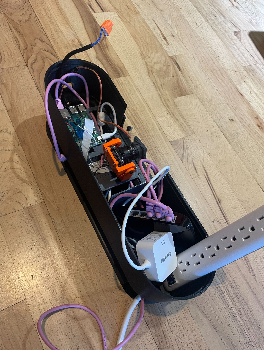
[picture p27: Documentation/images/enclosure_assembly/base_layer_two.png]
      5.  
      6.   
      7. Preparation for Middle Layer  
         1. In preparation for mounting the Middle Layer on the Base Layer, gently move the cables that will connect from the Base Layer to components in the Middle (and above) layers:  These cables include:  
            1. Network cable from the network switch (will connect to the Pi 1 on the upper floor of the Middle Layer)  
            2. 3-wire wiring harness from the Pi 2 on the base layer (will connect to the Connector Board on the lower floor of the Middle Layer  
            3. LED strobe power cable from the LED power supply in the Base Layer (will connect to the LED strobe on the lower floor of the Middle Layer  
         2. Each of these cables typically are routed off to the right.  
   8. Camera 2 Calibration  
      1. Now is the time to calibrate Camera 2\.  The camera is easily accessible at this point, and it will be more difficult to deal with once the Middle Layer of the LM is in place above it.  
      2. See Calibration Document [here](https://github.com/jamespilgrim/PiTrac/blob/main/Documentation/PiTrac%20-%20Camera%20Calibration.zip).  
3. Middle Layer assembly, including Second (middle) and Third (top) floors  
   1. Overview  
      1. Like the Base Layer, the Middle Layer consists of two wall halves that join together in the middle.  However, there are two floors on the right (Pi) side in the Middle Layer.  The lower Pi-side floor holds the strobe LED and the Connector Board.  The upper floor holds the Pi 1 computer and Camera 1\.  The wall halves are joined first.  Then, the components are attached to the Pi-Side lower floor half, and then the Pi-side and Power-Side Lower Floors are secured to the lower part of the Middle Layer.  Inter-floor wiring is completed, then the Pi-side Upper Floor is put in place in its respective half above the Lower Floor.  
   2. Build the Strobe Assembly  
      1. See Strobe Mount instructions [here](https://github.com/jamespilgrim/PiTrac/tree/main/3D%20Printed%20Parts/Enclosure%20Models/LED-Array-Strobe-Light-Mount).  
   3. Build the Connector Board  
      1. See Connector Board instructions (separate project) [here](https://github.com/jamespilgrim/PiTrac/tree/main/Hardware/Connector%20Board).  
      2. Ensure the two 12V IN and OUT wiring pairs and the 4-wire harness is attached to the Connector Board’s screw terminals before mounting the Floor to the Wall half  
         1. Attaching the wiring harnesses to the Connector Board on the ***lower*** floor early is essential because it is difficult to access the board once the ***top*** layer Pi-side floor is installed.  
         2. The 3-wire harness should already have been attached to the Pi 2 and the Pi Camera 2 in the Bottom Layer  
   4. Joining the Middle Layer Wall Halves  
      1. Place four M3 nuts into the indents on the Pi-side half-join pads.  If the fit is tight, the nuts can be pulled into the indents by using a temporary bolt from the outside.  Tape can help hold the nuts in their indents.  
      2. Join the two base halves using four pairs of M3 x 16mm bolts and nuts.  
      3. If necessary, disconnect the two sides and sand the half-join areas to ensure the two halves come together tightly without unsightly gaps.  
   5. Build the Middle Layer Lower Floor (Strobe & Connector Board) Assembly  
      1. Mount the Connector Board to the Lower Floor so that the 4-pin connection header is on the left and the writing is upright.  Mount the Board with four self-tapping M3 x 8mm or 10mm screws.    
      2. Mount the strobe assembly (LED and gimbal) using an M5 bolt that comes up from below the floor through an M5 nut in the indent in the base below the LED strobe light.  Position the LED power wires so that they lead back through the side wire holders on the Strobe Assembly.  Face the strobe straight out from the LM and tighten the M5 bolt now while it is easily accessible.  
   6. Mount the Lower Pi-side and power-side Middle Layer floors to the bottom of the lower mounting pads on the side of the Middle Layer walls.  
      1. Both of the lower floors mount on four screw holes on the ***underside*** of the lower floor mount pads using four self-tapping M3 x 10mm screws.  Do not over-tighten.  Note that the floor is below the pads, but the components are on the upper side of the floor.    
      2. The Middle Layer (without the 3- and 4- wire wiring harnesses or power) with the two lower floors looks like:  
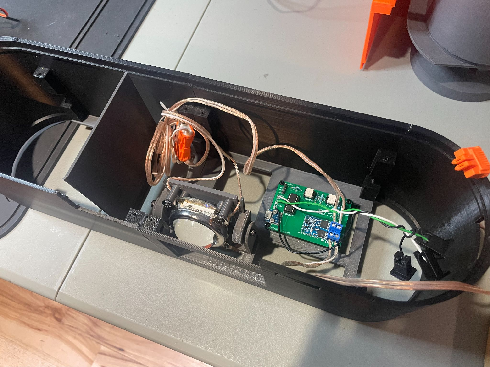
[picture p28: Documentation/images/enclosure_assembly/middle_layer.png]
      3.   
      4. Now is the time to route a 5V micro-USB power cord to the Connector Board and attach it.  Whatever 5V adapter is left on the left side bay.  
   7. Assemble the Camera 1 camera assembly  
      1. This assembly is similar to the Camera 2 assembly, but Camera 1 will be pointing downward fairly steeply, so the Camera 1 assembly has the camera mounted a little higher on a taller riser than the other camera.  Make sure you use the correct camera assembly so that the camera can point at a downward angle.  See the Camera Mount Assembly instructions, [here](https://github.com/jamespilgrim/PiTrac/tree/main/3D%20Printed%20Parts/Enclosure%20Models/Pi-Camera-Mounts): See photo below::   
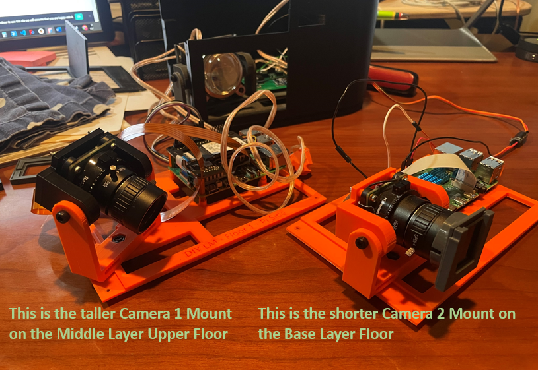
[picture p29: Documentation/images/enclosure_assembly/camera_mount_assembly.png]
      2.  
      3. Camera 1 uses visible light, so no external filter or modifications are necessary.  
   8. Assemble the Pi-side Middle Layer Upper Floor  
      1. **NOTE**\- this step follows the directions for the ***Base*** Layer Pi-side floor pretty closely, since both of these floors have a Pi and a Pi camera..  The two floors holding the RPis are similar.  Double check the labeling on the part to ensure the correct floor is used in each step  
      2. Mount the Camera 1 Assembly on the Middle Layer Upper Floor using an M5 bolt and nut.  It’s best to have the CSI cable in place and secure before mounting.     
         1. **NOTE:** Camera 1 uses a different adapter cable than Camera 2\.  
         2. See photo, above.  
      3. Mount the Pi 5 on the right side of Floor 1 using 4 M2.5 x 12 bolts and nuts, with the nuts on the bottom side.  Put the Micro-SD card (if used) in place beforehand when it’s more accessible.    
         1. Because we expect this Pi 5 to be used as a development platform in addition to being an operational part of the PiTrac, using an NVmE memory instead of an SD card is recommended.  An active cooler is also a good idea for those long compiles.  
      4. Connect the camera’s flat CSI cable to the Pi 5\.  Note that a special cable is necessary here because the Pi 5 uses a smaller size-format connector.  
   9. Mounting the Pi-side Middle Layer Upper Floor to the Middle Layer Wall  
      1. After confirming that both wiring harnesses are connected to the Connector Board, guide the 4-wire harness and the second network cable  to the right of the upper floor as you place the upper floor on the four mounting pads of the Pi-Side Middle Wall.  This will enable those wire wires to be connected to the Pi 1 on the Middle Layer upper floor.  
      2. Mount the upper floor to the side pads using four M3x10mm self-tapping screws.  
      3. Connect the 4-wire ribbon cable from the left side of the Connector Board in the lower floor to the GPIO pins of the Pi 1 computer on the upper floor.  See the upper part of the wiring diagram here:  
         1.  
      4. Connect the second network cable to the Pi from the switch in the base layer  
      5. Connect a Pi-5 compatible power supply (we used [this one](https://www.amazon.com/CanaKit-PiSwitch-Raspberry-Power-Switch/dp/B07H125ZRL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)) from the Power-Side to the Pi 5\.  Try to keep the cable out of the way of the strobe and other hardware on the lower layer beneath.  
      6. The Pi 5 should be operational at this point and the camera ready to be calibrated.  
   10. Middle-Layer Power-Side Assembly on the Middle Wall  
       1. There is no upper floor for the Middle-Layer power side.  The lower floor’s separator wall is high enough to partition off the entire power-side of the Middle Layer.  
   11. Mount the Middle Layer on the Base Layer (it’s really coming together now\!)  
       1. Before connecting the MIddle and Base Layers, make sure you have the wires from the Base Layer (especially the 3-wire harness) that will connect to the Connector Board in the Middle Layer.  
       2. Grip the Middle Layer securely by its back wall and hold it above the Base Layer with one hand so you can move things around with your other hand..  
       3. Push the network, LED power output, and Connector Board wiring harness off to the right of the Base Layer and thread them through the space on the right side of the Middle Layer as the Middle Layer is placed into position on the Base Layer.  These cables need to be connected to the components of the upper floor of the Middle Layer.  
          1. On the left-hand side: Guide whatever utility strip and power adapters you are using up through the void on the left side of the Middle Layer.  
          2. On the right-hand side: Thread the cables coming up from the Lower Layer through the space on the far-right of the Middle Layer, just to the right of the lower floor.  See below for what this should look like as we start to put the two layers together:  
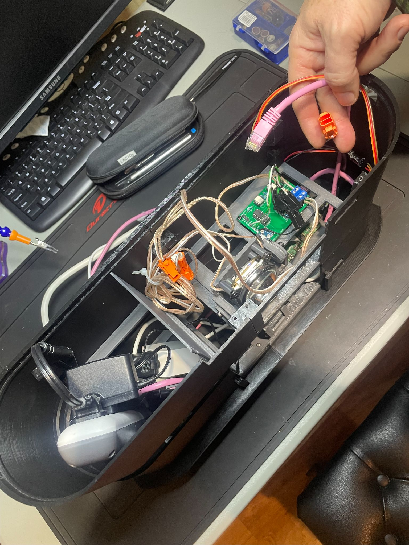
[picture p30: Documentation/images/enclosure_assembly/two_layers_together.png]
       4.  
       5. ***BEFORE*** trying to fully connect (snap together) the two layers, make sure that all of the various wires are well inside the walls and will not be pinched or cut between the layers when they come together\!  
       6. Gently insert the inner-wall click-tabs at the bottom of the Middle Layer into the inside of the wall tabs at the top of the Base Layer.  It’s often easier to set the upper layer into the back of the lower layer and then pull outward on the front of the Base Layer to help the top layer tabs click into the Base Layer.  
       7. Resist the temptation to hit the top–most layer down into the base layer.  And NOTE \- the top of the MIddle Layer is fairly sharp\!  
   12. Connect the output of the LED power supply in the Base Layer to the wires screwed into the Dual MOS switch of the Connector Board – marked as “IN (12V)”  
       1. **WARNING** \- Check and then double-check that the polarity of the wires is correct.  Using wires that have clear markings (such as a white-strip on one wire of a wire pair) helps.  If the LED is connected backward, it could be destroyed.  
       2. Using ‘keyed’ wire connector blocks that can only be connected in one way  (and not flipped) is a sound practice.  
       3. Most of the MOS switches that can be used with the Connector Board will have polarity markings on the MOS switch board.  For example, see below:  
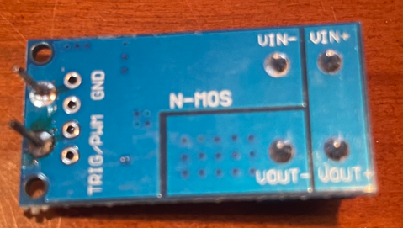
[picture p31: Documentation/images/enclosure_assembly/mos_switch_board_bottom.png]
       4. 
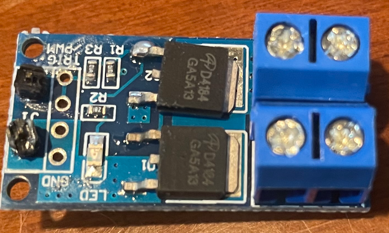
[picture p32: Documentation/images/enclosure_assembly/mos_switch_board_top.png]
       5.  
       6. Note however, that the components you source may be different\!  
   13. Connect the wire leads from the “OUT (12V)” terminals of the Connector Board to the  LED Strobe.  
       1. Make sure you don’t accidentally connect the strobe directly to the ***output*** of the LED power supply.  Doing so could melt the strobe assembly or worse.  
       2. Same warning on polarity as above.  
   14. Connect the wiring harness from both the Pi 2 (the Pi on the Base Layer floor) and the Pi Camera 2 from the Base Layer below up to the Connector Board   
       1. Using the schematic layout in the next subsection, below), ensure that the correct wires from the Camera 2 and the Pi 2 in the Base Layer are connected to the correct header pins on the Connector Board  
4. Securing the Base and Middle Layers  
   1. Secure the layers using M3 x 6mm self-tapping screws in the four screw holes at the interfaces of the bottom of the Middle Layer and the top of the Base layer.  Dulling the tips of the inter-floor screws (which currently overhang into the layer interiors) for safety is a good idea.  
5. Camera 1 Calibration  
   1. Prior to putting the ceiling over the upper camera 1, calibrate that camera using the separate Camera Calibration document [here](https://github.com/jamespilgrim/PiTrac/blob/main/Documentation/PiTrac%20-%20Camera%20Calibration.zip)  
6. Top Wall (Ceiling) section assembly  
   1. Connect the two ceiling halves using four M3 bolts and screws.  
   2. Snap the ceiling section onto the top of the Middle Layer.  Secure with 4  M3 x 6mm self-tapping screws in the four screw holes at the interfaces of the bottom of the Ceiling Layer and the top of the Middle Layer.  Dulling the tips of the inter-floor screws (which currently overhang into the layer interiors) for safety is a good idea.  
7. Add the Front Window  
   1. Add the protective 15.5cm x 24cm  plexiglass anti-ball-strike window by sliding it down into the mounting slots in the ceiling and base-layers.  The plexi window should be far enough away from the cameras and strobe light so that a ball strike against the window should not hit those expensive components.  
8. PiTrac Badge/Logo  
   1. The PiTrac badge is built from separately printing the back plate of the badge, and the letters (and parts of the “PiTrac” letters) and then putting them together.  
   2. You can pick the colors you’d like to use, of course.  We use the following palette:  
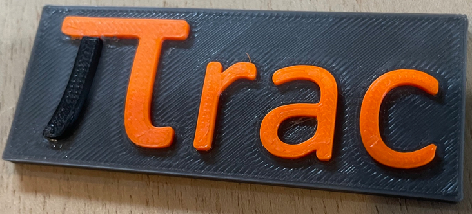
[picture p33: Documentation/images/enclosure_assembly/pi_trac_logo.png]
   3.  
   4. The parts fit better if they are printed full-sized for the back plate, and at 99% size for the characters.  After printing out the parts shown above, a hard-rubber hammer makes it easy to tap the characters into place.  Friction is enough to hold the parts together, but a little cyanoacrylate glue wicked into the joints will secure them permanently.  
   5. We attach the badge using 2-sided tape, as the rough surfaces don’t glue together very well.  
9. Next step is to go through the Start Up documentation [here](https://github.com/jamespilgrim/PiTrac/blob/main/Documentation/PiTrac%20Start-Up%20Documentation.md).

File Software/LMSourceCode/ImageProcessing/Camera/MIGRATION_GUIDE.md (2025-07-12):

# Camera Bounded Context - Migration Guide

## Overview
Migrate from monolithic `GolfSimCamera` to a clean Camera bounded context architecture.

### Current Status
✅ **Foundation exists**: Domain objects, infrastructure abstractions, tests, and build system are ready  
🔄 **Next step**: Namespace alignment and legacy integration

### Key Decision
**Use `golf_sim::camera` namespace** - aligns with existing codebase patterns rather than creating inconsistency.

## Legacy Codebase Issues

### Naming Inconsistencies
The legacy code mixes multiple naming conventions, **with patterns related to access levels**:

**Public vs Private Patterns Discovered:**
- **Public Constants**: Consistently use `kConstantCase` (good pattern)
- **Public Methods**: Mixed `camelCase` (`getNextFrame()`) and `PascalCase` (`GetCalibratedBall()`)  
- **Private Methods**: Mostly `camelCase` (`getExpectedBallRadiusPixels()`, `getBallDistance()`)
- **Variables**: `camera_number_` (snake_case_) and `exposureTime` (camelCase) mixed together
- **Namespaces**: Uses `golf_sim::camera::domain` aligned with existing `golf_sim` pattern

**Root Cause**: The inconsistency appears to follow **intended conventions** where:
- Private methods tend toward `camelCase` 
- Public methods mix both conventions inconsistently
- Constants are consistently `kConstantCase`

### Strategic Decision: Use `golf_sim::camera`
- **Why**: `golf_sim` represents the domain function, not the brand
- **Benefit**: No massive refactoring needed across codebase
- **Consistency**: 99% of existing code already uses `golf_sim` namespace

## Migration Strategy

### Phase 0: Foundation Assessment (COMPLETED ✅)
- ✅ **Complete**: Domain value objects exist (`Size`, `Transform`, `PixelFormat`, `ColorSpace`)
- ✅ **Complete**: Infrastructure abstraction layer established
- ✅ **Complete**: Test framework with Boost Test configured  
- ✅ **Complete**: CMake build system ready
- ✅ **Complete**: Namespace alignment from `libcamera_domain` to `golf_sim::camera::domain`
- 🔄 **Next**: Integration with legacy `GolfSimCamera` class

### Phase 1: Namespace Alignment and Integration Preparation (COMPLETED ✅)

#### Step 1: Update Existing Domain Namespace ✅
```cpp
// COMPLETED (in domain/camera_domain.hpp)
namespace golf_sim::camera::domain {
    struct Size { /*...*/ };
    struct Transform { /*...*/ };
    // ...
}

// VALIDATION: All tests pass (25 test cases)
namespace golf_sim::camera::domain {
    struct Size { /*...*/ };
    struct Transform { /*...*/ };
    // ...
}
```

#### Step 2: Extend Domain with Business Logic
Add camera entities and use cases to existing domain:
```cpp
namespace golf_sim::camera::domain {
    // Existing value objects...
    struct Size { /*...*/ };
    
    // NEW: Business entities
    class CameraEntity {
        // Camera state and behavior
    };
    
    // NEW: Domain services
    class CameraCalibrationService {
        // Calibration algorithms
    };
}

namespace golf_sim::camera::application {
    // NEW: Use cases and commands
    class CaptureImageUseCase { /*...*/ };
    class CalibrateCommand { /*...*/ };
}
```

#### Step 3: Create Legacy Integration Layer
```cpp
namespace golf_sim::camera::integration {
    class LegacyCameraAdapter {
        // Bridge to existing GolfSimCamera
    };
}
```

### Phase 2: Incremental Migration (RECOMMENDED NEXT STEPS)

#### Step 1: Update IPC Integration
Replace the camera usage in `gs_ipc_system.cpp`:

```cpp
// OLD (in gs_ipc_system.cpp)
#include "gs_camera.h"
GolfSimCamera* camera = GetCameraInstance();
int result = camera->TakeStillPicture();

// NEW
#include "ImageProcessing/Camera/integration/CameraContext.h"
auto cameraContext = golf_sim::camera::integration::CameraContext::Create();
auto adapter = std::make_unique<golf_sim::camera::integration::LegacyCameraAdapter>(cameraContext);
int result = adapter->TakeStillPicture();
```

#### Step 2: Update FSM Event Handling
Replace camera calls in `gs_fsm.cpp`:

```cpp
// OLD
void ProcessCameraEvent(const CameraEvent& event) {
    auto camera = GetGolfSimCamera();
    camera->TakeStillPicture();
}

// NEW
void ProcessCameraEvent(const CameraEvent& event) {
    // Use command pattern
    using namespace golf_sim::camera::application;
    commands::CaptureImageCommand command(
        event.exposureTime,
        event.gain,
        event.resolution
    );
    cameraContext_->ExecuteCommand(command);
}
```

#### Step 3: Replace Direct Hardware Calls
Update any direct hardware access:

```cpp
// OLD (scattered throughout codebase)
#ifdef __unix__
    // Unix-specific camera code
#else
    // Windows fallback
#endif

// NEW (all handled by factory)
auto cameraContext = CameraContext::Create();  // Automatically selects platform
```

### Phase 3: Event-Driven Integration

#### Subscribe to Camera Events
```cpp
// In main application setup
auto eventBus = cameraContext->GetEventBus();

// Subscribe to image capture events
eventBus->Subscribe<Application::Events::ImageCapturedEvent>(
    [](const auto& event) {
        // Process captured image
        const auto& result = event.GetResult();
        if (result.IsSuccess()) {
            // Send to ball tracking system
            ProcessBallImage(result.GetImageData());
        }
    }
);

// Subscribe to error events
eventBus->Subscribe<Application::Events::CameraErrorEvent>(
    [](const auto& event) {
        // Log error and notify monitoring system
        LogError("Camera error: " + event.GetError());
        NotifyMonitoringSystem(event.GetError());
    }
);
```

### Phase 4: Remove Legacy Code

#### Files to Remove After Migration:
1. Remove conditional compilation from business logic
2. Clean up `gs_camera.cpp/.h` (keep only what's needed for other bounded contexts)
3. Remove platform-specific `#ifdef` blocks
4. Consolidate hardware interfaces

#### Dependencies to Update:
1. Update CMakeLists.txt to include new Camera module
2. Update include paths
3. Remove deprecated header includes

## Integration Examples

### Example 1: Basic Camera Usage
```cpp
#include "ImageProcessing/Camera/integration/CameraContext.h"

// Create camera context
auto cameraContext = golf_sim::camera::integration::CameraContext::Create();

// Configure settings
golf_sim::camera::domain::CameraSettings settings;
settings.exposureTime = 0.001;  // 1ms
settings.gain = 2.0;
settings.resolution = {1920, 1080};
cameraContext->UpdateSettings(settings);

// Capture image
golf_sim::camera::domain::CaptureSettings captureSettings{
    settings.exposureTime,
    settings.gain,
    settings.resolution,
    golf_sim::camera::domain::TriggerMode::SOFTWARE
};

auto result = cameraContext->TakeStillPicture(captureSettings);
if (result.IsSuccess()) {
    // Process image data
    ProcessImageData(result.GetImageData());
}
```

### Example 2: Event-Driven Processing
```cpp
// Set up event handling
auto eventBus = cameraContext->GetEventBus();

// Handle image capture completion
eventBus->Subscribe<golf_sim::camera::application::events::ImageCapturedEvent>(
    [&ballTracker](const auto& event) {
        const auto& result = event.GetResult();
        if (result.IsSuccess()) {
            // Forward to ball tracking bounded context
            ballTracker.ProcessImage(result.GetImageData());
        }
    }
);

// Handle camera errors
eventBus->Subscribe<golf_sim::camera::application::events::CameraErrorEvent>(
    [&logger](const auto& event) {
        logger.LogError("Camera failure: " + event.GetError());
        // Trigger recovery procedures
    }
);
```

### Example 3: Command Pattern Usage
```cpp
using namespace golf_sim::camera::application;

// Create capture command
commands::CaptureImageCommand captureCmd(
    0.001,  // exposure time
    2.0,    // gain
    {1920, 1080},  // resolution
    golf_sim::camera::domain::TriggerMode::EXTERNAL
);

// Execute command
cameraContext->ExecuteCommand(captureCmd);

// Create calibration command
commands::CalibrateCommand calibrateCmd(
    commands::CalibrateCommand::CalibrationType::FULL
);

cameraContext->ExecuteCommand(calibrateCmd);
```

## Testing Strategy

### Unit Tests
- Test each bounded context component in isolation
- Mock hardware interfaces for reliable testing
- Test command/query handlers independently

### Integration Tests
- Test camera context with real hardware
- Test event publishing/subscription
- Test legacy adapter compatibility

### Migration Tests
- Run existing system alongside new system
- Compare outputs to ensure functional equivalence
- Performance benchmarking

## Benefits After Migration

### 1. Platform Independence
- No more `#ifdef __unix__` in business logic
- Clean separation of platform-specific code
- Easier to add new platforms (ARM, different Linux distros, etc.)

### 2. Testability
- Mock hardware interfaces for unit testing
- Test business logic without hardware dependencies
- Faster test execution

### 3. Maintainability
- Single Responsibility Principle enforced
- Clear separation of concerns
- Easier to understand and modify

### 4. Extensibility
- Easy to add new camera features
- Plugin architecture for different camera types
- Event-driven architecture enables loose coupling

### 5. Performance
- Reduced conditional compilation overhead
- Better compiler optimizations
- More efficient resource usage

## TODO LIST AND REFACTORING STRATEGY

### Complexity Identified During Investigation

#### 1. Namespace Architecture Issues
**Problem**: Should we follow existing `golf_sim` namespace convention or modernize to brand-specific namespaces?

**Revised Solution Strategy** (Domain-Focused Approach):
- **Embrace `golf_sim::camera` namespace** for new bounded context (domain-aligned, not brand-aligned)
- **Rationale**: 
  - `golf_sim` represents the **system domain** (golf simulation) not the brand
  - Brand names can change (PiTrac today, could be different tomorrow)
  - Domain functions are more stable than product branding
  - Minimal disruption to existing codebase patterns
  - Follows established conventions throughout the codebase
- **Implementation**: All new Camera bounded context code uses `golf_sim::camera` namespace
- **Legacy Integration**: No namespace translation needed - seamless integration

#### 2. Naming Convention Standards for New Code
**Decision**: Establish consistent naming standards to address legacy inconsistencies

**Adopted Standards** (based on analysis of legacy codebase patterns):
```cpp
// Classes: PascalCase
class CameraEntity { };
class CaptureCommand { };
class HardwareCameraInterface { };

// Methods: PascalCase (following existing Format(), Configure() pattern)
class CameraService {
public:
    void CaptureImage();           // NOT captureImage()
    std::string Format() const;    // Consistent with legacy
    void Configure();              // Consistent with legacy
};

// Member Variables: snake_case_ (following existing member pattern)
class Camera {
private:
    double exposure_time_;         // Consistent with existing
    int camera_number_;           // Consistent with existing
    std::string device_path_;     // Consistent with existing
};

// Constants: kConstantCase (following existing kCamera1, kTest pattern)
namespace Constants {
    static constexpr double kDefaultExposureTime = 0.001;
    static constexpr int kMaxRetryAttempts = 3;
    static constexpr std::string_view kDefaultDevice = "/dev/video0";
}

// Enums: PascalCase with scoped values
enum class TriggerMode {
    Software,    // NOT SOFTWARE or kSoftware
    Hardware,
    External
};

// Namespaces: Domain-aligned hierarchical (following existing patterns)
namespace golf_sim::camera::domain { }
namespace golf_sim::camera::application { }
namespace golf_sim::camera::infrastructure { }
```

**Integration with Legacy Code**:
```cpp
// Seamless integration - no namespace translation needed
namespace golf_sim::camera {
    class CameraService {
        // New code uses consistent naming within established namespace
        void CaptureImage() {
            // Direct integration with legacy code in same namespace
            legacy_camera_->takeStillPicture();  // camelCase legacy method
        }
        
    private:
        golf_sim::GolfSimCamera* legacy_camera_;  // Same namespace
    };
}
```

#### 3. Interface Design Philosophy  
**Decision Needed**: How to handle domain vs application interfaces
- Option A: Single interface serving both domain and application needs
- Option B: Separate domain and application interfaces with adapters
- **Recommendation**: Option A for simplicity in this context

#### 4. Error Handling Strategy
**Decision Needed**: How to propagate errors through layers
- Option A: Exceptions throughout
- Option B: Result<T, Error> pattern  
- Option C: Error codes and error callbacks
- **Recommendation**: Option A for consistency with existing code

#### 5. Threading Model
**Critical Performance Requirement**: Spin rate detection is performance-critical
- **Current Performance**: ~2 seconds, optimized for multi-core processing
- **High Impact**: Improving this performance would be very valuable
- **Risk**: Degrading this performance would be undesirable

**Strategic Threading Approach**:
- **Preserve**: Existing multi-core spin analysis (don't break what works)
- **Enhance**: Add async camera capture to improve overall system responsiveness
- **Avoid**: Any threading changes that could slow down the core spin detection

**Threading Strategy**:
- **Option A**: Synchronous operations with multi-threaded image processing
- **Option B**: Async capture with parallel spin analysis pipelines  
- **Option C**: Full async/await with thread pools for compute-heavy operations
- **Recommendation**: Option B - Preserve multi-core spin processing, add async capture

### IMMEDIATE NEXT STEPS

#### Critical: Hardware-Independent Testing Strategy
**Open Source Success Requirement**: Automated testing without external hardware dependencies is **critical** for:
- **PR Validation**: Confidence that pull requests don't break existing functionality
- **Release Quality**: Assurance that code can be safely released to end users
- **Contributor Onboarding**: New developers can run tests without specialized hardware
- **CI/CD Pipeline**: Automated builds and tests in cloud environments

**Testing Architecture Requirements**:
```cpp
// Hardware abstraction enables testing without cameras
namespace golf_sim::camera::testing {
    class MockCameraHardware : public ICameraHardware {
        // Simulate camera behavior with deterministic responses
    };
    
    class ImageSimulator {
        // Generate synthetic golf ball images for testing
    };
}
```

#### Implementation Priorities

1. **Start with Hardware Abstraction**
   - Create `ICameraHardware` interface first
   - Implement mock camera for testing
   - Generate synthetic test images
   - **Validate**: All tests pass without real hardware

2. **Minimal Bounded Context Extension**
   - Implement ONLY value objects first
   - Test compilation and unit tests
   - Add ONE interface with stub implementation
   - **Validate**: Clean build + passing tests

3. **Incremental Growth with Test Coverage**
   - Add one method at a time
   - Write tests BEFORE implementation
   - Don't move to next layer until current layer has 100% test coverage
   - **Do not change any code not covered by an automated test unless it is changed using a provable refactoring**
   - **Validate**: Each increment maintains test suite health

**Provable Refactoring Resources**:
- **Arlo Belshee's Provable Refactorings**: 
https://github.com/digdeeproots/provable-refactorings

- **Arlo Belshee's Risk Aware Commit Notation**: 
[Arlo's Commit Notation](https://github.com/RefactoringCombos/ArlosCommitNotation) - A notation for small commits messages that show the risk involved in each step

- **Martin Fowler's Refactoring**: [Catalog of Refactorings](https://refactoring.com/catalog/) - Authoritative reference for safe transformations

- **Michael Feathers' "Working Effectively with Legacy Code"** - [Essential techniques for adding tests to untested code](https://archive.org/details/working-effectively-with-legacy-code)

#### Success Criteria for Each Phase
- **Phase 1**: All files compile without errors
- **Phase 2**: All unit tests pass
- **Phase 3**: Integration tests pass  
- **Phase 4**: One legacy usage successfully replaced

### RISK MITIGATION

#### Build Failures
- Make many small and reversible changes
- Test on a clean environment regularly
- Aim to improve the [pipeline](https://github.com/jamespilgrim/PiTrac/blob/a3b3f1baad0ded3066b0c9585ce4879ef6314d18/.github/workflows/camera-tests.yml) test coverage
- Maintain a working baseline with frequent small pull requests and short lived branches

#### Integration Issues  
- Create comprehensive test coverage before migration
- Use feature flags to enable/disable new implementation
- Maintain legacy code until migration complete

#### Performance Issues
- Benchmark existing performance before migration
- Monitor performance after each migration step
- Have a rollback plan for any performance regressions

---

## **Next Steps:**
1. Execute Phase 1: Namespace alignment and business logic extension  
2. Create integration adapters for legacy `GolfSimCamera`
3. Begin incremental migration of specific usage points
4. Leverage existing test framework for validation

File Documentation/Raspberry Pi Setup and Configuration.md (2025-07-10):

**PiTrac \- Raspberry Pi Setup and Configuration**

- [Summary](#summary)  
- [Necessary & Recommended Components](#necessary--recommended-components)  
  - [Standard Setup](#standard-setup)  
    1. [Environment](#environment)  
    2. [Operating System](#operating-system)  
    3. [Log Into Pi](#log-into-pi)  
    4. [Remote Log Into Pi](#remote-log-into-pi)  
    5. [Sudo Priviledges](#sudo-priviledges)  
    6. [Install NVME Board](#install-nvme-board)  
    7. [NAS Drive Setup and Mounting](#nas-drive-setup-and-mounting)  
    8. [Samba Server Setup](#samba-server-setup)  
    9. [SSH Stored Key](#ssh-stored-key)  
    10. [Additional Setup](#additional-setup)  
    11. [Git and Github](#git-and-github)  
    12. [Clock Configuration](#clock-configuration)  
    13. [Build and Install OpenCV](#build-and-install-opencv)  
    14. [Install Boost](#install-boost)  
    15. [Build and Install LGPIO](#build-and-install-lgpio)  
    16. [Build and Install Libcamera](#build-and-install-libcamera)  
    17. [Build RPICAM-Apps](#build-rpicam-apps)  
    18. [Install Java OpenJDK](#install-java-openjdk)  
    19. [Install MsgPack](#install-msgpack)  
    20. [Install ActiveMQ C++ CMS](#install-activemq-c-cms)  
    21. [Install ActiveMQ Broker](#install-activemq-broker)  
    22. [Install Maven](#install-maven)  
    23. [Install Tomee](#install-tomee)  
    24. [Install Launch Monitor Dependencies](#install-launch-monitor-dependencies)  
- [Build Launch Monitor](#build-launch-monitor)  
  - [Setup PiTrac](#setup-pitrac)

## Summary

These instructions are targeted toward folks who do not have a lot of experience building software systems in the Pi Operating System and who could benefit from more step-by-step direction. Someone who’s familiar with using tools like meson and ninja to build software can likely skip over many of these steps. However, the instructions contain a number of idiosyncratic steps and configuration requirements that are particular to PiTrac.
r
These instructions start with a Raspberry Pi with nothing on it, and are meant to describe all the steps to get from that point to a working, compiled version of PiTrac.  PiTrac currently requires two Raspberry Pi’s, so the majority of these instructions will have to be repeated twice.  Because the ‘smaller’ Pi system that connects to Camera 2 is the only Pi that handles the Tomcat/Tomee web-based GUI for the system, there are a few more steps for that system.

NOTE - The new "single-pi" version of PiTrac does not have its own documentation yet.  Until then, please note that these instructions can work when using only a single Pi.  You just need to do everything with what we consider here to be the "Pi 1" system even if the instructions refer to the Pi 2 system.  For example, if a step in this document says "Log into the Pi 2 computer...", you will just log into the (only) Pi 1 system.

## Necessary & Recommended Components

- A Raspberry Pi 4 and a Pi 5 with at least 4 GB of memory (8 GB recommend for the Pi 5\)  
- A Micro SD card with at least 64Gig  
- Especially if you are planning on using the larger Pi 5 as a development environment, an NVMe hat with an NVMe SSD drive is a great investment.  
- Power supplies for the Pi’s  
- Network cabling if using the Pi’s wired ethernet port (recommended \- some of the packages we’ll be downloading are large and slow over WiFi)  
- Monitor, keyboard and mouse to connect to the Pi (recommended, but can also run the Pi ‘headless’ without any direct connections  
- Especially if running headless, a Mac, PC, or other Linux machine that you will use to interact with the Pi, along with a terminal tool to login to the Pi, such as Putty.  
- Visual Studio (optional) for your PC or MAC  
  - Most of the PiTrac system runs not only in the Pi, but can also (mostly) run from a Visual Studio platform on a PC or Mac.  The more comfortable graphical  programming environment in VS is great for testing and debugging and coding new features into the same code base.  
- A separate file server, such as a NAS is highly recommended if you expect to be making changes to the PiTrac system.  Pi’s are a little fragile, so keeping the PiTrac files elsewhere in a safer environment (and then mounting those files on the Pi remotely) is a good practice.  
  - We typically have a separate server that we use both from the Pi and also from a PC running Visual Studio that is used to help debugging.  
  - It’s wise to think of the Pi as a temporary, write-only device that could be erased at any time.

### Standard Setup

#### Environment

1. Create a secure, static-safe environment to run your Pi’s on.  3D-Printing the two Pi-Side “Floors” from the plans on github is one way to provide this environment, and you’ll need to print them at some point anyway.

#### Operating System

2. Raspian O/S and Pi Initialization  
   a. Start with the Pi powered off (unplugged).  Have a Cat5/6 cable that is connected to your local network plugged in if possible.  
   b. On a PC, connect a Micro SD card via USB to use to boot the Pi for the first time.  
   1. Use a 64GB card so we have room to expand  
      c. Install and run the [RPi Imager utility](https://www.raspberrypi.com/software/)  
      d. Select Pi 4 or 5 for the device depending on what you have, for Operating System choose the 64-bit OS.  Make sure the “Storage” is pointing to the MicroSD card (and not something like your hard-drive\!), as it will be overwritten entirely.  Hit NEXT.  
      e. Answer “EDIT SETTING” when asked if you want to apply customisations  
   2. If you are American, ignore the clearly-incorrect spelling of “customization.” ;)  
   3. In the GENERAL tab,:  
      1. Select a hostname that will easily distinguish between the two Pi’s in the system, such as rsp01, rsp02, etc.  
      2. Add a \<PiTracUsername\> username that will be used to compile and run PiTrac, and that can log into your NAS, if you’re using a server (recommended).  E.g., “pitrac” as a user (or just use “pi”)  
         1. This will be the username and password necessary to log into the system for the first time, so double-check you’ve verified both.  
         2. Use the actual user name whenever you see \<PiTracUsername\> below  
      3. Make sure the wireless LAN credentials are setup in case you can’t connect a hard line  
   4. In the SERVICES tab,  
      1. Enable SSH and use password authentication  
         f. After setting up the customizations, select YES to “apply OS customisation settings” to the card setup and start the write process.  Should take about 20 minutes.  
         g. Once the SD Card is written and verified, if you have a keyboard, mouse, and monitor, hook those up first.  This can all be done via a remote login, but it’s nice to be able to have a full user setup from the beginning if there are any issues.  
         h. Insert the Micro SD card into the Pi and start up the Pi by plugging in the power (don’t insert or disconnect the SD card when the Pi is on\!)..  
   2. The first bootup takes a while.  Better to be able to monitor it with an attached monitor if possible.

#### Log into Pi

4. Log into the Pi using whatever credentials you expect to use to run PiTrac (the \<PiTracUserName\>  
   a. If running headless, remotely login using putty or a ssh tool of your choice  
   1. Logging in from whatever computer you are reading this setup document on will make it easy to copy-paste from this document into files on the Pi  
   2. For example,  
      1. putty rsp02 \-l \\\<username\\\>    (the boot image should already allow putty)  
         b. If running directly with a monitor and keyboard, click on updates icon near top-right to make sure everything is up to date  
   3. Install everything to get up to date  
      c. Or, equivalently, do the following from the command line:  
   4. sudo apt \-y update  
   5. sudo apt \-y upgrade  
   6. sudo reboot now      (to make sure everything is updated)

#### Remote Log into Pi

5. Remotely login (to be able to paste from this setup document)  
   a. putty rsp01 \-l \\\<username\\\>    (the boot image should already allow putty)  
   b. Then, follow the instructions below…

#### Sudo Privileges

6. If necessary, make sure that \<PiTracUserName\> has sudo privileges  
   a. Some guidance [here](https://askubuntu.com/questions/168280/how-do-i-grant-sudo-privileges-to-an-existing-user).

#### Install NVME Board

7. To Install an NVME Board on the Pi  \[Optional, and probably only for the Pi 5 (confusingly referred to as the “Pi 1” computer in the PiTrac project):  
   a. If you have a SSD drive, best to get it up and booting now before you install everything on the slower, smaller MicroSD card instead.  
   b. See also the instructions here, which will work in most cases: [https://wiki.geekworm.com/NVMe\_SSD\_boot\_with\_the\_Raspberry\_Pi\_5](https://wiki.geekworm.com/NVMe_SSD_boot_with_the_Raspberry_Pi_5)  
   Although the instructions below should work as well.  
   c. With the Pi off, Install the NVMe Board and NVMe SSD drive per instructions of whatever board you are using.  
   d. Power up and Enable the PCIe interface (your instructions may differ):  
   1. cd /boot/firmware/  
   2. sudo cp config.txt config.txt.ORIGINAL  
   3. By default the PCIe connector is not enabled.  
   4. To enable it you should add the following option into /boot/firmware/config.txt before the last “\[all\]” at the end of the file and reboot (sudo reboot now):  
      1. \# Enable the PCIe External Connector.  
      2. dtparam=pciex1  
         1. A more memorable alias for pciex1 exists, so you can alternatively add dtparam=nvme to the /boot/firmware/config.txt file.  
            e. After the reboot, we will image the NVMe drive  
   5. First, ***if using a non-HAT+ adapter***, add on first non-commented line of /boot/firmware/config.txt:   PCIE\_PROBE=1  (see instructions for you device)  
   6. Change BOOT\_ORDER to BOOT\_ORDER=0xf416 (to boot off NVM first), OR \- better yet,  
      1. sudo raspi-config  
      2. Go to the Advanced Options /s Boot Order  
      3. Select whatever order you want, usually NVMe card first  
   2. Shutdown, remove power to the Pi, and reboot.  Afterward, an lsblk command should show something like this (see last line):  
        
      pitrac@rsp05:\\\~ $ lsblk    

      NAME        MAJ:MIN RM   SIZE RO TYPE MOUNTPOINTS    
        
      mmcblk0     179:0    0  29.7G  0 disk    
        
      |-mmcblk0p1 179:1    0   512M  0 part /boot/firmware    
        
      \\\`-mmcblk0p2179:2    0  29.2G  0 part /    
        
      nvme0n1     259:0    0 238.5G  0 disk    
        
   3. At this point, the NVMe drive should be accessible, and we will make a copy (image) of the bootup Micro SD card onto the SSD drive  
   4. From the Pi Graphical Desktop, Applications \=\>Accessories \=\>SD Card Copier on the main screen, run the SD Card Copier program, and copy the OS to the NVME ssd.  There’s no need to select the separate UUID option.  
      1. If running headless, see the internet for other ways to image the SSD  
   2. Power down, remove power, then remove the SSD card  
   3. When you turn the power on, the Pi should reboot from the SSD drive, and it should be pretty quick\!

#### NAS Drive Setup and Mounting

8. Setup mounting of a remote NAS drive (or similar)  
   a. Many folks use an external NAS drive for development so that you can’t lose everything if an individual Pi has an issue.  An external drive also allows for easier transfers of files to the Pi from another computer that can also see that drive.  
   b. The remote drive will store the development environment, though you can obviously set up the PiTrac not to need a separate drive once you have everything working.  However, it’s really a good idea to have the development and test environment on a different computer than on the individual Pi’s.  
   c. There are many ways to automatically mount a removable drive to a Pi.  The following is just one way that assumes you have a NAS with NFS services enabled and with a shareable drive that the Pi can read/write to.  
   1. NOTE:  If this Pi will be anywhere in a public network, obviously do not include your password in the fstab\!  
      d. `sudo mkdir /mnt/PiTracShare`  
      e. `cd /etc`  
      f. `sudo cp fstab fstab.original`  
      g. `sudo chmod 600 /etc/fstab`   \[to try protect any passwords in the file\]  
      h. `sudo vi fstab`  
   2. If using NFS (usually easier) put the following the fstab file:  
      1. \<NAS IP Address\>:/\<NAS Shared Drive Name\> /mnt/PiTracShare nfs \_netdev,auto 0 0  
      2. For example:  
         1. 10.0.0.100:/NAS\_Share\_Drive /mnt/PiTracShare nfs \_netdev,auto 0 0  
   3. If using CIFS:  
      1. Add the following to /etc/fstab after the last non-comment line, replacing PWD and other things in \[\]’s with the real pwd and info  
         1. //\<NAS IP Address\>:/\<NAS Shared Drive Name\> /mnt/PiTracShare cifs username=\[PiTracUserName\],password=\[PWD\],workgroup=WORKGROUP,users,exec,auto,rw,file\_mode=0777,dir\_mode=0777,user\_xattr 0 0  
            i. `sudo systemctl daemon-reload`  
            j. `sudo mount -a`  
      2. If there’s an error, make sure the password is correct  
      3. ls \-al /mnt/PiTracShare    should show any files there

#### Samba Server Setup

9. Setup Samba server (to allow the two Pi’s to share a folder between themselves)  
   a. Need to allow the Pi’s to serve out directories to the other Pi to share information like debugging pictures from one Pi to the other  
   b. See [https://pimylifeup.com/raspberry-pi-samba/](https://pimylifeup.com/raspberry-pi-samba/) for the basics  
   c. We suggest the faster Pi 5 (or whatever will be connected to Camera 1\) be the Pi from which the shared directory is shared.  
   d. For the Pi from which the directory will be shared, something like:  
   1. sudo apt-get install samba samba-common-bin  
   2. sudo systemctl restart smbd  
   3. sudo systemctl status smbd  
      1. Should show “active (running)”  
   2. mount \-t cifs  
   3. Create the directory structure that the two Pis will share (this helps facilitate transfer of debugging images between the two Pis, as well as images for the PiTrac GUI)  
      2. mkdir -p /home/\<PiTracUsername\>/LM\_Shares/WebShare  
      3. mkdir /home/\<PiTracUsername\>/LM\_Shares/Images  
   2. sudo vi /etc/samba/smb.conf   and add the following lines at the bottom  
      1. \[LM\_Shares\]  
      2. path \= /home/\<PiTracUsername\>/LM\_Shares  
      3. writeable=Yes  
      4. create mask=0777  
      5. directory mask=0777  
      6. public=no  
   2. sudo smbpasswd \-a \<PiTracUsername\>  
      1. Enter the same password you used for the PiTracUsername  
   2. sudo systemctl restart smbd  
      e. For the Pi to which the directory will be shared:  
   3. Add the following to /etc/fstab after the last non-comment line, replacing PWD and other things in \[\]’s with the real pwd and info for the PiTracUserName and password  
      1. //\<Pi 1’s IP Address\>/LM\_Shares /home/\<PiTracUser\>/LM\_Shares cifs username=\[PiTracUserName\],password=\[PWD\],workgroup=WORKGROUP,users,exec,auto,rw,file\_mode=0777,dir\_mode=0777,user\_xattr 0 0  
   3. mkdir /home/<PiTracUsername>/LM_Shares      (this will be the Pi 2 mount point)
   4. sudo systemctl daemon-reload  
   5. sudo mount \-a  
   6. Check to make sure the second Pi can “see” the other Pi’s LM\_Shares sub-directories (Images and WebShare)

#### SSH Stored Key

10. Setup ssh to use a stored key make it easier to login securely and quickly (w/o a pwd) \[optional, but really useful to avoid having to type a password every time\]  
    1. **WARNING \-** This step assumes your PiTrac is secure in your own network and that the machine you use to log in is not used by others (given that this helps automate remote logins)  
    2. If not already, remotely log into the Pi from the machine where you’re reading this document  
    3. Create an ssh file  
       1. install \-d \-m 700 \~/.ssh  
    4. Install putty on the remote (non-Pi Mac/PC) machine that you’ll use to log in  
    5. Use the puttygen utility to generate a public key.  This is just a long text string or two  
    6. vi \~/.ssh/authorized\_keys and paste in the public key for putty  
    7. (or can just use the mount to get a copy of the file from another Pi)  
    8. The key would have been generated using puttygen  
    9. The file should simply have each key (no spaces\!)  preceded on the same line with “ssh-rsa ”  
    10. sudo chmod 644 \~/.ssh/authorized\_keys

#### Additional Setup

11. If you don’t already have your development world setup the way you want it, we suggest trying now some of the environments/tools at the bottom of these instructions labeled “[**Nice-to-Haves for an easy-to-use development environment**](#nice-to-haves)”

#### Git and Github

12. Git and GitHub  
    1. If the project will be hosted on a shared drive, and you 100% control of that drive and it’s not public, then let github know that we’re all family here.  On the pi and on whatever computer you log in from, do::  
       1. git config \--global \--add safe.directory "\*"  
       2. Otherwise, Git desktop and Visual Studio often have problems

#### Clock Configuration

13. Configure the clock to not vary (as our timing is based on it\!)  
    1. cd /boot/firmware  
    2. sudo cp config.txt config.txt.ORIGINAL  
    3. sudo vi config.txt:  
    4. For Pi 4 & 5:  
       1. Set force\_turbo=1   in /boot/firmware/config.txt  
       2. E.g.,  
       3. \# PiTrac MOD \-  force fast clock even at low load  
       4. force\_turbo=1  
    5. For Pi 5 also add  
       1. arm\_boost=1 in /boot/firmware/config.txt

#### Build and Install OpenCV

14. Install and build OpenCV \- for both python and C++  
    a. Latest version of OpenCV as of this writing (late 2024\) is 4.10  
    b. See e.g., [https://itslinuxfoss.com/install-opencv-debian/](https://itslinuxfoss.com/install-opencv-debian/) for more information on installing  
    c. If necessary, increase swap space to have around 6 Gig of usable space.  For a 4 Gig or larger Pi, you can skip this step and just go to compiling  
    1. See [https://qengineering.eu/install-opencv-4.5-on-raspberry-64-os.html](https://qengineering.eu/install-opencv-4.5-on-raspberry-64-os.html)  
       1. \# enlarge the boundary (CONF\_MAXSWAP)  
       2. $ sudo nano /sbin/dphys-swapfile  
       3. \# give the required memory size (CONF\_SWAPSIZE)  
       4. $ sudo nano /etc/dphys-swapfile  
       5. \# reboot afterwards  
       6. $ sudo reboot  
    2. See also [https://docs.opencv.org/3.4/d7/d9f/tutorial\\\_linux\\\_install.html](https://docs.opencv.org/3.4/d7/d9f/tutorial\\_linux\\_install.html)  
       d. Compile OpenCV  
    3. mkdir \~/Dev  
    4. cd Dev    (this is where we will compile the packages PiTrac needs)  
    5. See [https://qengineering.eu/install-opencv-4.5-on-raspberry-64-os.html](https://qengineering.eu/install-opencv-4.5-on-raspberry-64-os.html)  
    6. You can use the fully-automated script from the above webpage, though you might learn more if you follow the steps in the guide (which mirror the script).  
       1. The script is named OpenCV-4-10-0.sh and is available as described in the above URL.  
       2. In the OpenCV-4-10-0.sh script, it’s useful for testing to change the following before running:  
          1. INSTALL\_C\_EXAMPLES=ON  
          2. INSTALL\_PYTHON\_EXAMPLES=ON  
       3. In addition, if your Pi only has 4 GB or less, change the “-j4” to “-j 2” to prevent the compile process from consuming all the memory.  
       4. Run the script and review the output to make sure there were no errors.  The script takes quite a while to run on some Pi’s.  
    2. Ensure the script runs the sudo make install step at the end after the script runs

#### Install Boost

15. Install Boost (a set of utilities that PiTrac uses)  
    1. Install the current version of the boost development environment  
       1. `sudo apt-get install libboost1.74-all`  
    2. NOTE - This next step should no longer be needed.  Only do this if the "meson setup build" step does not work.   Create a boost.pc file to tell meson how to find boost files when PiTrac is compiled  
       1. `sudo vi  /usr/share/pkgconfig/boost.pc`    and in it place:
       ```
       # Package Information for pkg-config  
       # Path to where Boost is installed  
       prefix=/usr  
       # Path to where libraries are  
       libdir=${prefix}/lib  
       # Path to where include files are  
       includedir=${prefix}/boost  
       Name: Boost  
       Description: Boost provides free peer-reviewed portable C++ source libraries  
       Version: 1.74.0   #  OR WHATEVER VERSION YOU DOWNLOAD  
       Libs: -L${libdir} -lboost_filesystem -lboost_system -lboost_timer -lboost_log -lboost_chrono -lboost_regex -lboost_thread -lboost_program_options  
       Cflags: -isystem ${includedir}
       ```
    2. Finally, because of a problem when compiling boost under C++20 (which PiTrac uses), add `#include <utility>` as the last include before the line that says “namespace boost” in the awaitable.hpp file at /usr/include/boost/asio/awaitable.hpp”  
       1. `sudo vi /usr/include/boost/asio/awaitable.hpp`  
       2. This is a hack, but works for now.

#### Build and Install LGPIO

16. Install and build lgpio (this is a library to work with the GPIO pins of the Pi)  
    1. `cd ~/Dev`  
    2. wget [http://abyz.me.uk/lg/lg.zip](http://abyz.me.uk/lg/lg.zip)  
    3. `unzip lg.zip`  
    4. `cd lg`
    5. `make`  
    6. `sudo make install`  
    7. Create `sudo touch /usr/lib/pkgconfig/lgpio.pc` containing the following:
    ``` bash
    # Package Information for pkg-config  
    prefix=/usr/local  
    exec_prefix=${prefix}  
    libdir=${exec_prefix}/lib  
    includedir=${prefix}/include/  
    Name: lgpio  
    Description: Open Source GPIO library  
    Version: 1.0.0  
    Libs: ${exec_prefix}/lib/liblgpio.so  
    Cflags: -I${includedir}
    ```
    2. Enable the SPI pins on the Pi  
       1. `sudo raspi-config`  
       2. Select 3 Interface Option  
       3. Select l4 SPI Enable/Disable  
       4. Select Yes on the next screen  
       5. Finish

#### Build and Install Libcamera

17. Install and build libcamera (for c++ camera control)  
    1. Install Prerequisites  
       1. `sudo apt-get install -y libevent-dev`  
       2. `sudo apt install -y pybind11-dev`  
       3. `sudo apt -y install doxygen`  
       4. `sudo apt install -y python3-graphviz`  
       5. `sudo apt install -y python3-sphinx`  
       6. `sudo apt install -y python3-yaml python3-ply`  
       7. `sudo apt install -y libavdevice-dev`  
       8. `sudo apt install -y qtbase5-dev libqt5core5a libqt5gui5 libqt5widgets5`  
    2. NEW \- MARCH 7 2024 \- Use [https://www.raspberrypi.com/documentation/computers/camera\_software.html\#building-libcamera-and-rpicam-apps](https://www.raspberrypi.com/documentation/computers/camera_software.html#build-libcamera-and-rpicam-apps)  
       1. BUT \-  
          1. Perform the git clone at \~/Dev where we’ve been building the other software  
          2. Do not install boost dev as a prerequisite- we built it already above  
          3. When done (after the install step), do sudo ldconfig to refresh the shared libraries  
          4. On the Pi 4 (if it has less than 6GB memory), add “-j 2” at the end of the ninja \-C build command to limit the amount of memory used during the build.  E.g., ninja \-C build \-j 2  
             - On low-memory Pi’s, if you run out of memory, the computer will often just freeze and hang, requiring a hard-reboot
          5. libcamnera can be very verbose for higher logging levels if you are using an early version of libcamera.  We suggest you effectively disable some of the logging by editing the file `libcamera/subprojects/libpisp/src/libpisp/common/logging.hpp` and replacing the contents with the following in order to help minimize the trace-log junk.  If the file does not exist, ignore this step.
             `#pragma once

#include <cassert>

#ifndef PISP_LOGGING_ENABLE
#define PISP_LOGGING_ENABLE 0
#endif

#if PISP_LOGGING_ENABLE

#define PISP_LOG(sev, stuff) do { } while(0)

#else

#define PISP_LOG(sev, stuff) do { } while(0)

#endif

#define PISP_ASSERT(x) assert(x)

namespace libpisp
{
        // Call this before you try and use any logging.
        void logging_init();
} // namespace libpisp

// Ensure NO logging occurs.  It's usually too verbose
#ifdef PISP_LOG
#undef PISP_LOG
#endif

#define PISP_LOG(sev, stuff) do { } while(0)`
       2. If the build fails at the last install step, see: [https://github.com/mesonbuild/meson/issues/7345](https://github.com/mesonbuild/meson/issues/7345) for a possible solution.  Specifically, exporting the following environment variable and re-building.  
          1. `export PKEXEC\_UID=99999`  
          2. `cd build && sudo ninja install`

#### Build RPICAM-Apps

18. Build rpicam-apps:  
    1. See the following for instructions, but with a couple exceptions…[https://www.raspberrypi.com/documentation/computers/camera\_software.html\#building-libcamera-and-rpicam-apps](https://www.raspberrypi.com/documentation/computers/camera_software.html#building-libcamera-and-rpicam-apps)  
       1. BUT, we will add `-Denable_opencv=enabled` to the meson build step because we have installed OpenCV and will wish to use OpenCV-based post-processing stages  
       2. Also, we don’t need to re-install most of the prerequisites listed in the Pi website.  Just do:  
          1. sudo apt install \-y libexif-dev  
    2. Specifically, do this:  
       1. cd \~Dev  
       2. git clone [https://github.com/raspberrypi/rpicam-apps.git](https://github.com/raspberrypi/rpicam-apps.git)  
       3. cd rpicam-apps  
       4. meson setup build \-Denable\_libav=enabled \-Denable\_drm=enabled \-Denable\_egl=enabled \-Denable\_qt=enabled \-Denable\_opencv=enabled \-Denable\_tflite=disabled \-Denable\_hailo=disabled  
       5. meson compile \-C build  
       6. sudo meson install \-C build  
       7. sudo ldconfig \# this is only necessary on the first build

#### Install Java OpenJDK

19. Install recent java (for activeMQ)  
    1. `sudo apt install openjdk-17-jdk openjdk-17-jre`

#### Install MsgPack

20. Install msgpack  
    1. Info at:  [https://github.com/msgpack/msgpack-c/wiki/v1\_1\_cpp\_packer\#sbuffer](https://github.com/msgpack/msgpack-c/wiki/v1_1_cpp_packer#sbuffer)  
    2. cd \~/Dev  
    3. git clone [https://github.com/msgpack/msgpack-c.git](https://github.com/msgpack/msgpack-c.git)  
    4. For some reason, the above does not grab all the necessary files. So, also go here: [https://github.com/msgpack/msgpack-c/tree/cpp\_master](https://github.com/msgpack/msgpack-c/tree/cpp_master) and click on “Code” and down load the zip file into the \~/Dev directory  
    5. unzip /mnt/PiTracShare/dev/tmp/msgpack-c-cpp\_master.zip  
    6. `cd msgpack-c-cpp_master`  
    7. `cmake -DMSGPACK_CXX20=ON .`  
    8. `sudo cmake --build . --target install`  
    9. `sudo /sbin/ldconfig`

#### Install ActiveMQ C++ CMS

21. Install ActiveMQ C++ CMS messaging system (on both Pi’s)  
    1. This code allows PiTrac to talk to the ActiveMQ message broker  
    2. Pre-requisites:  
       1. `sudo apt -y install libtool`  
       2. `sudo apt-get -y install libssl-dev`  
       3. `sudo apt-get -y install libapr1-dev`  
       4. `sudo apt install -y libcppunit-dev`  
       5. `sudo apt-get install -y autoconf`  
    3. Download and unzip [activemq-cpp-library-3.9.5-src.tar.gz](http://www.apache.org/dyn/closer.lua/activemq/activemq-cpp/3.9.5/activemq-cpp-library-3.9.5-src.tar.gz)  
       1. This version is a little old, but we’re not aware of a newer one  
       2. May also able to do:  
          1. git clone [https://gitbox.apache.org/repos/asf/activemq-cpp.git](https://gitbox.apache.org/repos/asf/activemq-cpp.git) if the available version is new enough (3.9.5 or later)  
       3. ([https://activemq.apache.org/components/cms/developers/building](https://activemq.apache.org/components/cms/developers/building) has more information on the installation process, if necessary)  
    2. `cd ~/Dev`  
    3. `gunzip /mnt/PiTracShare/tmp/activemq-cpp-library-3.9.5-src.tar.gz` (or wherever you put the .gz zip file)  
    4. `cd activemq-cpp-library-3.9.5`  
    5. `./autogen.sh`  
    6. `./configure`  
    7. `make`  
    8. `sudo make install`

#### Install ActiveMQ Broker

22. Install ActiveMQ Broker (need only do on the Pi 2 system, as it is the only system that will be running the broker ?)  
    1. We will install the binary (non-source code version)  
    2. Get Apache Pre-Reqs (most should already have been installed)  
       1. `sudo apt -y install libapr1-dev`  
       2. `sudo apt -y install libcppunit-dev`  
       3. `sudo apt -y install doxygen`  
       4. `sudo apt -y install e2fsprogs`  
       5. `sudo apt -y install maven`  
    3. [https://activemq.apache.org/components/classic/download/](https://activemq.apache.org/components/classic/download/) has the source code zip file that you will want to download with the ActiveMQ Broker  
       1. E.g., [apache-activemq-6.1.4-bin.tar.gz](https://www.apache.org/dyn/closer.cgi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)  
    2. Follow these instructions to install (but NOT the source-install option - we're just installing the executables, not building them):  
       1. [https://activemq.apache.org/version-5-getting-started.html\#installation-procedure-for-unix](https://activemq.apache.org/version-5-getting-started.html#installation-procedure-for-unix)  
       2. Set the following environment variable to ensure you don’t run out of memory:  
          1. `export MAVEN_OPTS=-Xmx1024M` (ignore for RaspberryPi 5 8GB)
       3. We suggest you install activemq at `/opt`, so…  
          1. `cd /opt`  
          2. `sudo tar xvf /mnt/PiTracShare/tmp/apache\*.tar`  (or wherever you put the tarball file  
       2. Test it manually once, and then we’ll start it automatically later:  
          1. `cd /opt/apache-activemq` 
          2. `sudo ./bin/activemq start`   (NOTE \- must start in main directory to ensure that the files like logs get created in the correct place)  
          3. Wait a half-minute and then check the data/activemq.log file to make sure everything is good  
          4. `netstat -an|grep 61616` should then return “LISTEN”  
          5. `sudo ./bin/activemq stop`  
       2. Setup for remote access  
          1. `cd conf`  
          2. `sudo cp jetty.xml jetty.xml.ORIGINAL`  
          3. `sudo vi jetty.xml jetty.xml`  
             1. Search for the line that has `127.0.0.1` and replace with whatever the IP address is for the Pi this is all  running on.  
             2. Search for the line that begins with “ Enable this connector if you wish to use https with web console”  
             3. Uncomment the next section by removing the \!-- and -- at the beginning and end of the bean.  The section should then look like  \<bean id="Secure blah blah blah, and then at the end, \</bean\>  
          4. `cd .. && sudo ./bin/activemq start`  
          5. Log into the broker console from another machine by: http://\<Pi IP address or name\>:8161/admin  
             1.The default login is typically admin/admin
             2. If this works, the broker is setup correctly  
       2. Setup ActiveMQ to run automatically on startup  
          1. `sudo vi /etc/systemd/system/activemq.service` and add:
            ```bash 
            # Verify your version in the directory path name
            [Unit]  
            Description=ActiveMQ  
            After=network.target  
            [Service]  
            User=root  
            Type=forking  
            Restart=on-failure
            ExecStart=/opt/apache-activemq/bin/activemq start  
            #ExecStop=/opt/apache-activemq/bin/activemq stop  
            KillSignal=SIGCONT  
            [Install]  
            WantedBy=multi-user.target
            ```
          2. `sudo systemctl daemon-reload`  
          3. `sudo systemctl start activemq`  
          4. `sudo systemctl enable activemq`  
          5. `sudo reboot now`   (to test the auto-start) (use whatewver apache directory you chose, of course) 
          6. After the system comes back, do the following to verify it’s working:  
             1. `sudo /opt/apache-activemq-6.1.4/bin/activemq status`  (should say it’s running)  
             2. And from a browser, check 

#### Install Maven

23. Install maven for building servlets on Tomcat/Tomee  
    1. `sudo apt -y install maven`

#### Install Tomee

24. Install Tomee (on the cam2 system only)  
    1. Use the “Plume” version that supports JMS  
    2. Get the Tomee binary here:  [https://tomee.apache.org/download.html](https://tomee.apache.org/download.html)  
    3. cd /opt  
    4. sudo unzip /mnt/PiTracShare/tmp/apache-tomee-10.0.0-M3-plume.zip  (or whatever version you’re using)  
    5. sudo mv apache-tomee-plume-10.0.0-M3 tomee      \[or whatever version\]  
    6. `sudo chmod -R 755 tomee`  
       1. **WARNING** \- Only use this technique if you’re on a secure, private platform.  It’s easier to simply allow read-writes from other than the root user, but there’s other (better) ways of doing this too.  This is just a simple hack for a home system.  
    7. `cd tomee`
    8. `sudo chmod -R go+w webapps` (so that the tomcat uses can deploy webapps  
    9. `sudo vi conf/tomcat-users.xml` and add before the last line (\</tomcat-users\>)  
      ```xml
      <role rolename="tomcat"/>
      <role rolename="admin-gui"/>
      <role rolename="manager-gui"/>
      <user username="tomcat" password="tomcat" roles="tomcat,admin-gui,manager-gui"/>
      ``` 
      10. Add a systemctl daemon script to /etc/systemd/system/tomee.service so that tomee will start on boot. `sudo vi /etc/systemd/system/tomee.service
```bash
[Unit]  
Description=Apache TomEE  
After=network.target  
[Service]  
User=root  
Type=forking  
#Environment=JAVA_HOME=/usr/lib/jvm/default-java  
Environment=JAVA_HOME=/usr/lib/jvm/java-1.17.0-openjdk-arm64  
Environment=CATALINA_PID=/opt/tomee/temp/tomee.pid  
Environment=CATALINA_HOME=/opt/tomee  
Environment=CATALINA_BASE=/opt/tomee  
Environment=CATALINA_OPTS='-server'  
Environment=JAVA_OPTS='-Djava.awt.headless=true'  
ExecStart=/opt/tomee/bin/startup.sh  
ExecStop=/opt/tomee/bin/shutdown.sh  
KillSignal=SIGCONT  
[Install]  
WantedBy=multi-user.target
```
11. `cd webapps/manager/META-INF; sudo cp context.xml context.xml.ORIGINAL` [just in case]  

12. Update /opt/tomee/webapps/manager/META-INF/context.xml to allow “.\*” instead of just 127.0….  Replace the whole regex string.  The result should simply be allow=".\*" on that line  
```xml
<Context antiResourceLocking="false" privileged="true" >
  <CookieProcessor className="org.apache.tomcat.util.http.Rfc6265CookieProcessor"
                   sameSiteCookies="strict" />
  <Valve className="org.apache.catalina.valves.RemoteAddrValve"
         allow=".*" />
  <Manager sessionAttributeValueClassNameFilter="java\.lang\.(?:Boolean|Integer|Long|Number|String)|org\.apache\.catalina\.filters\.CsrfPreventionFilter\$LruCache(?:\$1)?|java\.util\.(?:Linked)?HashMap"/>
</Context>
```
   13. Disable local host access logging.  Otherwise, it will fill up that log quickly.  To do so, comment out the following section in /opt/tomee/conf/server.xml:
    ```<Valve className="org.apache.catalina.valves.AccessLogValve" directory="logs" prefix="localhost_access_log" suffix=".txt" pattern="%h %l %u %t &quot;%r&quot; %s %b" />```
   14. Comment out this section by adding <!-- to the beginning of the section and --> to the end of the section.
   15. For more details, see  https://help.harmanpro.com/disabling-local-host-access-logs-in-tomcat.
   16. Add a new document base/root to allow access to the shared mounted drive:  
       1. Edit `/opt/tomee/conf/server.xml` and just before the `</Host>` near the end of the file, insert the following, with the <PiTracUserName> replaced with the name you use:  
       2. \<Context docBase="/home/\<PiTracUserName\>/LM\_Shares/WebShare" path="/golfsim/WebShare" /\>  
       3. This will allow the Tomee system to access a directory that is outside of the main Tomee installation tree.  This directory will be used to get debugging images from the other Pi into the web-based GUI that this Pi will be serving up.  
       4. NOTE \- if the shared directory that is mounted off of the other Pi does not exist, Tomee may not be able to start
       5. The server.xml file should look similar to:
          ```      <Host name="localhost"  appBase="webapps"
            unpackWARs="true" autoDeploy="true">

        <!-- SingleSignOn valve, share authentication between web applications
             Documentation at: /docs/config/valve.html -->
        <!--
        <Valve className="org.apache.catalina.authenticator.SingleSignOn" />
        -->

        <!-- Access log processes all example.
             Documentation at: /docs/config/valve.html
             Note: The pattern used is equivalent to using pattern="common" -->
        <!-- <Valve className="org.apache.catalina.valves.AccessLogValve" directory="logs"
               prefix="localhost_access_log" suffix=".txt"
               pattern="%h %l %u %t &quot;%r&quot; %s %b" />  -->

        <Context docBase="/home/pitrac/LM_Shares/WebShare" path="/golfsim/WebShare" />

      </Host>
    </Engine>
  </Service>
</Server>```

   15. Allow symbolic linking.  In conf/context.xml, add before the end:  
       1. `<Resources allowLinking="true" />`
       2. The context.xml should look similar to:
          ```<!-- The contents of this file will be loaded for each web application -->
<Context>

    <!-- Default set of monitored resources. If one of these changes, the    -->
    <!-- web application will be reloaded.                                   -->
    <WatchedResource>WEB-INF/web.xml</WatchedResource>
    <WatchedResource>WEB-INF/tomcat-web.xml</WatchedResource>
    <WatchedResource>${catalina.base}/conf/web.xml</WatchedResource>

    <!-- Uncomment this to enable session persistence across Tomcat restarts -->
    <!--
    <Manager pathname="SESSIONS.ser" />
    -->

    <Resources allowLinking="true" />

</Context>```
   16. Install the systemctl service we just created and start it:  
       1. `sudo systemctl daemon-reload`  
       2. `sudo systemctl enable tomee`  
       3. `sudo systemctl start tomee`  
       4. `sudo systemctl status tomee.service`  
       5. Try the following to see how things are starting and to fix any problems:  
          1. `sudo tail -f /opt/tomee/logs/catalina.out`  
       6. Next login from a web console:   http://\<Pi-with-Tomee\>:8080/manager/html  
          1. user-name/pwd is by default tomcat/tomcat.  Change if not in a private network.
       7. <font color=#ff0000>Warning:</font> On Mac Chrome may not allow you to connect from outside the hosted Raspberry Pi. Safari should work.

#### Install Launch Monitor Dependencies

25. Install other Launch Monitor dependencies  
    1. Formatting library because the currently-packaged gcc12.2 in Debian unix doesn’t have the c++20 format capability yet  
       1. `sudo apt -y install libfmt-dev`

#### Build Launch Monitor

26. **Build the PiTrac Launch Monitor\!**  
    1. Download the PiTrac repository, including the source code under the “Software” subdirectory if you haven’t already  
       1. We usually use a subdirectory called \~/Dev under the home directory of the PiTrac user to house any cloned repositories such as PiTrac.    
       2. You can do the copy by going to github and downloading the .zip  file, or from the command-line on the Pi using something like:  
          1. `cd ~/Dev`  
          2. `git clone https://github.com/jamespilgrim/PiTrac.git`  
       3. NOTE \- If you do you plan to do any code changes, you may want to create a fork from the main repository and then clone that into your Pi.  
    2. Install Remaining Prerequisites and Setup Environment:  
       1. Setup the `PITRAC_ROOT` and other environment variables.  For example set PITRAC_ROOT to point to the “Software/LMSourceCode” directory of the PiTrac build.  That is one directory “up” from the “ImageProcessing” directory that contains the main PiTrac meson.build file. The other environment variables listed below (with example values) should be set according to your network and environment. 
          1. E.g., include in your .zshrc or .bashrc (or whatever shell you use) the following, with the camera types set to your equipment type:  
```
export PITRAC_ROOT=/Dev/PiTrac/Software/LMSourceCode  
export PITRAC_BASE_IMAGE_LOGGING_DIR=\~/LM_Shares/Images/
export PITRAC_WEBSERVER_SHARE_DIR=~/LM_Shares/WebShare/
export PITRAC_MSG_BROKER_FULL_ADDRESS=tcp://10.0.0.41:61616
# Only uncomment and set the following if connecting to the
# respective golf sim (e.g., E6/TruGolf, GSPro, etc.)
#export PITRAC_E6_HOST_ADDRESS=10.0.0.29
#export PITRAC_GSPRO_HOST_ADDRESS=10.0.0.29

# Tell any rpicam apps where to get their configuration info (including, e.g., any timeout settings)
export LIBCAMERA_RPI_CONFIG_FILE=/usr/share/libcamera/pipeline/rpi/pisp/rpi_apps.yaml

# For Single-Pi configurations (most) specify that both cameras are Official Pi GS cameras with 6mm lenses
export PITRAC_SLOT1_CAMERA_TYPE=4
export PITRAC_SLOT2_CAMERA_TYPE=4

# Specify that both cameras are (for now) Innomaker GS cameras with 3.6mm lenses
#export PITRAC_SLOT1_CAMERA_TYPE=6
#export PITRAC_SLOT2_CAMERA_TYPE=6

```
       2. sudo apt-get -y install libraspberrypi-dev raspberrypi-kernel-headers
       3. Add extended timeout to `rpi_apps.yaml` file so that even if an external trigger doesn’t fire for a really long time, the libcamera library won’t time-out:  
          1. (**NOTE** for Pi 5, use `/usr/share/libcamera/pipeline/rpi/pisp` instead of `/usr/share/libcamera/pipeline/rpi/vc4`, below)  
```
          2. `cd  /usr/share/libcamera/pipeline/rpi/vc4`  
          3. `sudo cp  rpi_apps.yaml  rpi_apps.yaml.ORIGINAL`
```
          4. In both `/usr/local/share/libcamera/pipeline/rpi/vc4/rpi_apps.yaml` and `usr/share/libcamera/pipeline/rpi/vc4/rpi_apps.yaml`, (to the extent they exist) at the end of the pipeline section, add the following (including the last comma\!)  
             ``` bash
             # Custom timeout value (in ms) for camera to use. This overrides  
             # the value computed by the pipeline handler based on frame  
             # durations.  
             #  
             # Set this value to 0 to use the pipeline handler computed  
             # timeout value.  
             #  
             "camera_timeout_value_ms": 1000000,
             ```  
             NOTE - For the Pi 5, you may only have an "example.yaml" file in the above directories.  If so, just copy it to rpi_apps.yaml.
<font color=#ff0000>Note for later -  Warning:</font> If you have a problem running `libcamera-vid -t 0` and doing so results in a blank screen. Something went wrong in this step, causing the camera to timeout.
             As a result, use `ps -aux | grep libcamera` to kill the pid `sudo kill -9 <pid_num>`. This will also cause other errors/issues while attemping to use `pitrac_lm`. 

          5. The first file deals with the local file from the libcamera build, and the second one is the for libcamera that is installed with the O/S.  We will set both, just in case.  
       2. Get the latest `imx296_noir.json` into `/usr/share/libcamera/ipa/rpi/pisp or ...rpt/vc4` (located inside ImageProcessing folder)
          1. For the Pi 4:  
             1. `sudo cp imx296_noir.json.PI_4_FOR_VC4_DIRECTORY /usr/share/libcamera/ipa/rpi/vc4/imx296_noir.json`  
          2. For the Pi 5:  
             1. `sudo cp imx296_noir.json.PI_5_FOR_PISP_DIRECTORY /usr/share/libcamera/ipa/rpi/pisp/imx296_noir.json`  
    2. Go to the directory called ImageProcessing below whatever `PITRAC_ROOT` directory path you will be using to compile.  E.g.,   
       1. `cd $PITRAC_ROOT/ImageProcessing`  
    3. `chmod +x create_closed_source_objects.sh`  
    4. `meson setup build`  
       1. If there are any missing libraries, ensure that the pre-requisites were all successfully built and installed and that any corresponding pkgconfig files were created correctly per the steps above.  
    5. `ninja -C build`       (add \-j 2 if compiling in 4GB or less)  
    6. If the build completes successfully, try a quick sanity check to ensure that any shared libraries are correctly linked at that the PiTrac application can at least run:  
       1. `build/pitrac_lm --help`    
       2. (that’s two ‘-’ characters before help)  
       3. The app should return the available command-line options

#### Setup PiTrac GUI

26. First, make sure you’ve setup the required environment variables (especially PITRAC_ROOT and PITRAC_WEBSERVER_SHARE_DIR) and the directory values in the golf\_sim\_config.json file.  Instructions are [here](https://github.com/jamespilgrim/PiTrac/blob/main/Documentation/PiTrac%20configuration%20and%20the%20golf_sim_config.json%20file.md).  
    1. These values tell the web-based PiTrac GUI where to look for the .json configuration file, which the GUI in turn uses to know where to look for certain shared image files.  
27. Setup the PiTrac-specific code package for the PiTrac GUI on the Tomee server  
    1. Log into the Pi 2 computer where the Tomee instance is running and make sure that $PITRAC_ROOT and other PITRAC_xxxx environment variables are set correctly as described above (can run "env | grep PITRAC") 
    2. Make sure Tomee is running:  
       1. `sudo systemctl status tomee`   (hit ‘q’ to exit)  
    3. `cd ~/Dev`   (or whatever the root of your development environment is)  
    4. `mkdir WebAppDev`  
    5. `cd WebAppDev`
    6. `cp $PITRAC_ROOT/ImageProcessing/golfsim_tomee_webapp/refresh_from_dev.sh .`  
    7. If necessary, create the refresh file yourself by doing: `vi refresh_from_dev.sh`     (a new file) and put this in it:
      <font color=#FF0000>Note:</font> Update your Broker IP address located in `MonitorServlet.java` class before creating the file below. <i>Will be improved in the future.</i>
```
sed -i s/PITRAC_WEBSERVER_SHARE_DIR/$PITRAC_WEBSERVER_SHARE_DIR/g ./src/main/webapp/index.html

<a href="monitor?config_filename=PITRAC_WEBSERVER_SHARE_DIR/golf_sim_config.json">Monitor</a>

echo $PITRAC_WEBSERVER_SHARE_DIR > webserver_name.tmp.txt
sed -i 's/\//%2F/g' webserver_name.tmp.txt

sed -i 's@PITRAC_WEBSERVER_SHARE_DIR@'`cat webserver_name.tmp.txt`'@g' ./src/main/webapp/index.html

rm webserver_name.tmp.txt
```
    2. Run that refresh script to bring over the java and other web-based GUI files:   
       1. You can ignore and errors from the 'sed' program regarding file permissions.
       2. `chmod 755 refresh_from_dev.sh;./refresh_from_dev.sh`  
       3. NOTE that the above script will also move a copy of the golf\_sim\_config.json file into the shared directory that the GUI can access in order to get information about its run-time environment.  The PiTrac GUI in particular needs the "kWebServerTomcatShareDirectory" value in order to know where to find diagnostic images.  
    3. Tell the MonitorServlet where to find its configuration file  
       1. `vi ./src/main/webapp/index.html`  
       2. Ensure that the line that begins with "<a href="monitor?config_filename" points to the correct webserver share direcory (typically ~/LM_Share/WebShare)
          1. Alternatively, you can just create a browser bookmark to point to the servlet with the correct filename 
      ![](snapshots/index_replace_name.png)
    2. Create the “.war” package for Tomee  
       1. `mvn package`  
       2. NOTE:  The first time this is performed, it will take a few minutes to gather up all the required packages from the internet  
       3. This process will create a “golfsim.war” file in the “target” directory.  That file will then have to be “deployed” into tomee.
       4. Usually, you can just manually move the .war file into place and Tomee should pick it up.  Wait 30 seconds or so after doing this to give Tomee a moment to see the new war file and deploy it. For example,  
          1. `cd /opt/tomee/webapps`  
          2. `sudo cp ~/Dev/WebAppDev/target/golfsim.war .`  
       5. Alternatively, you can use the Tomee management app to deploy.  To do so, open the manager console at `http://<Name-or-IP-address-of-Pi-with-Tomee>:8080/manager/html`  Your browser should have a window titled “Tomcat Web Application Manager”.  You may have to use the default login of tomcat/tomcat  
       6. Copy the .war file to a place that is visible on the computer from where your browser is logged into the tomee console.  
       7. Select “Choose File” in the section in the Tomee manager console labeled “WAR file to deploy”.  Select the .war file and then wait a moment until it’s name is displayed.  Then push the “Deploy” button.  
       8. In a moment, the “golfsim” app should show up on the list.  Click it.  
       9. If you get a “HTTP Status 404 – Not Found” error, try:  
          1. `cd /opt/tomee/webapps`  
          2. `sudo chmod -R 777 golfsim`  
          3. `sudo systemctl restart tomee`  (the first error will ‘stick’ otherwise)  
       10. However you deploy the app, confirm you can see the PiTrac GUI by entering the following into your browser:  
           1. `http://<The-Pi-2-name-or-IP-address>:8080/golfsim/monitor?config_filename=%2Fhome%2F<Whatever-your-PiTrac-User-is-and-no-<>'s >y%2FLM_Shares%2FWebShare%2Fgolf_sim_config.json`  
       11. You should see the PiTrac GUI

**CONGRATULATIONS\!** \- At this point, you’ve (hopefully) built the PiTrac software.  Please see the [Startup Documentation](https://github.com/jamespilgrim/PiTrac/blob/main/Documentation/PiTrac%20Start-Up%20Documentation.md) for how to get PiTrac working\!

### Nice-To-Haves

**Nice-to-Haves for an easier-to-use development environment**

2. The following steps are only for someone who’s a little new to linux and doesn’t already have a development environment setup the way they like it.  The following are just a few tools that (for the authors of the PiTrac project) seem to make things a little more efficient.  This setup deals with things like easy command-recall, file and command completion,making vi a little more like Visual Studio (for better or worse\!), etc.  
3. Z-shell and OhMyZa  
   1. Connect to your raspberry Pi with SSH  
   2. Install zsh :  
      1. sudo apt-get update && sudo apt-get install zsh  
      2. Edit your passwd configuration file to tell which shell to use for user pi :  
         1. sudo vi /etc/passwd and change /bin/bash to /bin/zsh for the \<PiTracUserName\> (usually the last line)  
         2. **WARNING:** Double-check the line in passwd is correct \- you won’t be able to ssh back in if not\!  
         3. logout  
   2. Reconnect to your raspberry, and  
      1. If on login Zsh asks about the .z files, select 0 to create an empty .zshrc  
      2. check that zsh is the shell with echo $0.  
   2. Install OhMyZsh :  
      1. sh \-c "$(wget [https://raw.githubusercontent.com/robbyrussell/oh-my-zsh/master/tools/install.sh](https://raw.githubusercontent.com/robbyrussell/oh-my-zsh/master/tools/install.sh) \-O \-)"  
   2. Disconnect from your instance and reconnect/re-login to it.  
   3. Turn off  any zsh processing for any large git directories (otherwise,  it will make “cd” into a git directory freeze)  
      1. cd \<whatever directory you plan to build PiTrac in\>  
      2. git config \--add oh-my-zsh.hide-status 1  
      3. git config \--add oh-my-zsh.hide-dirty 1  
      4. NOTE \- you may have to do this later if you don’t have the directory picked out yet  
2. Install neovim  
   1. Install NeoVim:  
      1. sudo apt-get install neovim  
         2\. sudo apt-get install python3-neovim  
   2. Install vundle into NVIM, (and not vim, as many online instructions assume\!):  
      1. git clone [https://github.com/VundleVim/Vundle.vim.git](https://github.com/VundleVim/Vundle.vim.git) \~/.config/nvim/bundle/Vundle.vim  
      2. Configure neovim \- Vundle does not work perfectly with nvim unless you make some changes  
         1. Vi \~/.config/nvim/bundle/Vundle.vim/autoload/vundle.vim and change  
         2. Change $HOME/.vim/bundle (should be near the end of the file) to $HOME/.config/nvim/bundle  
      3. Note these comments:  
         1. [https://gist.github.com/lujiacn/520e3e8abfd1c1b39c30399222766ee8](https://gist.github.com/lujiacn/520e3e8abfd1c1b39c30399222766ee8)  
         2. [https://superuser.com/questions/1405420/i-really-need-help-installing-vundle-for-neovim](https://superuser.com/questions/1405420/i-really-need-help-installing-vundle-for-neovim)  
      2. Create the file /home/\<PiTracUserName\>/.config/nvim/init.vim and add:  
         1. set nocompatible              " be iMproved, required  
         2. filetype off                  " required  
         3. " set the runtime path to include Vundle and initialize  
         4. set rtp+=\~/.config/nvim/bundle/Vundle.vim  
         5. call vundle\#begin()            " required  
         6. Plugin 'VundleVim/Vundle.vim'  " required  
         7. " \===================  
         8. " my plugins here  
         9. " \===================  
         10. Plugin 'scrooloose/nerdtree'  
         11. Plugin 'valloric/youcompleteme'  
         12. " Plugin 'dracula/vim'  
         13. " \===================  
         14. " end of plugins  
         15. " \===================  
         16. call vundle\#end()               " required  
         17. filetype plugin indent on       " required  
      2. Add any other plugins you want.  The above example establishes these two  
         1. Plugin 'scrooloose/nerdtree'  
         2. Plugin 'valloric/youcompleteme'  
      2. Run vim and type :PluginInstall     in order to install the plug ins.  It will take a few moments to process.  
      3. (Ignore anything on the net that refers to .vimrc \- that’s not applicable if using nvim.

Example .zshrc file – The highlighted bits at the end should be the only thing you need to add:  
\# If you come from bash you might have to change your $PATH.  
export PATH=.:/$HOME/bin:/usr/local/bin:$PATH

\# Path to your oh-my-zsh installation.  
export ZSH="$HOME/.oh-my-zsh"

\# Set name of the theme to load \--- if set to "random", it will  
\# load a random theme each time oh-my-zsh is loaded, in which case,  
\# to know which specific one was loaded, run: echo $RANDOM\_THEME  
\# See [https://github.com/ohmyzsh/ohmyzsh/wiki/Themes](https://github.com/ohmyzsh/ohmyzsh/wiki/Themes)  
ZSH\_THEME="robbyrussell"

\# Set list of themes to pick from when loading at random  
\# Setting this variable when ZSH\_THEME=random will cause zsh to load  
\# a theme from this variable instead of looking in $ZSH/themes/  
\# If set to an empty array, this variable will have no effect.  
\# ZSH\_THEME\_RANDOM\_CANDIDATES=( "robbyrussell" "agnoster" )

\# Uncomment the following line to use case-sensitive completion.  
\# CASE\_SENSITIVE="true"

\# Uncomment the following line to use hyphen-insensitive completion.  
\# Case-sensitive completion must be off. \_ and \- will be interchangeable.  
\# HYPHEN\_INSENSITIVE="true"

\# Uncomment one of the following lines to change the auto-update behavior  
\# zstyle ':omz:update' mode disabled  \# disable automatic updates  
\# zstyle ':omz:update' mode auto      \# update automatically without asking  
\# zstyle ':omz:update' mode reminder  \# just remind me to update when it's time

\# Uncomment the following line to change how often to auto-update (in days).  
\# zstyle ':omz:update' frequency 13

\# Uncomment the following line if pasting URLs and other text is messed up.  
\# DISABLE\_MAGIC\_FUNCTIONS="true"

\# Uncomment the following line to disable colors in ls.  
\# DISABLE\_LS\_COLORS="true"

\# Uncomment the following line to disable auto-setting terminal title.  
\# DISABLE\_AUTO\_TITLE="true"

\# Uncomment the following line to enable command auto-correction.  
\# ENABLE\_CORRECTION="true"

\# Uncomment the following line to display red dots whilst waiting for completion.  
\# You can also set it to another string to have that shown instead of the default red dots.  
\# e.g. COMPLETION\_WAITING\_DOTS="%F{yellow}waiting...%f"  
\# Caution: this setting can cause issues with multiline prompts in zsh \< 5.7.1 (see \#5765)  
\# COMPLETION\_WAITING\_DOTS="true"

\# Uncomment the following line if you want to disable marking untracked files  
\# under VCS as dirty. This makes repository status check for large repositories  
\# much, much faster.  
\# DISABLE\_UNTRACKED\_FILES\_DIRTY="true"

\# Uncomment the following line if you want to change the command execution time  
\# stamp shown in the history command output.  
\# You can set one of the optional three formats:  
\# "mm/dd/yyyy"|"dd.mm.yyyy"|"yyyy-mm-dd"  
\# or set a custom format using the strftime function format specifications,  
\# see 'man strftime' for details.  
\# HIST\_STAMPS="mm/dd/yyyy"

\# Would you like to use another custom folder than $ZSH/custom?  
\# ZSH\_CUSTOM=/path/to/new-custom-folder

\# Which plugins would you like to load?  
\# Standard plugins can be found in $ZSH/plugins/  
\# Custom plugins may be added to $ZSH\_CUSTOM/plugins/  
\# Example format: plugins=(rails git textmate ruby lighthouse)  
\# Add wisely, as too many plugins slow down shell startup.  
plugins=(git)

source $ZSH/oh-my-zsh.sh

\# User configuration

\# export MANPATH="/usr/local/man:$MANPATH"

\# You may need to manually set your language environment  
\# export LANG=en\_US.UTF-8

\# Preferred editor for local and remote sessions  
\# if \[\[ \-n $SSH\_CONNECTION \]\]; then  
\#   export EDITOR='vim'  
\# else  
\#   export EDITOR='mvim'  
\# fi

\# Compilation flags  
\# export ARCHFLAGS="-arch x86\_64"

\# Set personal aliases, overriding those provided by oh-my-zsh libs,  
\# plugins, and themes. Aliases can be placed here, though oh-my-zsh  
\# users are encouraged to define aliases within the ZSH\_CUSTOM folder.  
\# For a full list of active aliases, run \`alias\`.  
\#  
\# Example aliases  
\# alias zshconfig="mate \~/.zshrc"  
\# alias ohmyzsh="mate \~/.oh-my-zsh"  
\#

alias cdlm='cd  /mnt/PiTracShare/GolfSim/LM/ImageProcessing'  
alias cdlml='cd  \~/Dev/LaunchMonitor/ImageProcessing'  
alias cdlc='cd  /mnt/PiTracShare/GolfSim/LibCamTest'  
alias cdserv='cd /usr/share/tomcat9-examples/examples/WEB-INF/classes/async'  
alias ll='ls \-al'  
function findtext() {  
grep \-rni "$1" .  
}

\# Some useful navigation aliases

alias pushdd="pushd \\$PWD \> /dev/null"  
alias cd='pushdd;cd'  
alias ssh='ssh \-A'  
alias soc='source \~/.bashrc'  
\#below to go back to a previous directory (or more)  
alias popdd='popd \>/dev/null'  
alias cd.='popdd'  
alias cd..='popdd;popdd'  
alias cd...='popdd;popdd;popdd'  
alias cd....='popdd;popdd;popdd;popdd'  
\#below to remove directories from the stack only (do not 'cd' anywhere)  
alias .cd='popd \-n \+0'  
alias ..cd='popd \-n \+0;popd \-n \+0;popd \-n \+0'

\# Enable vi mode  
bindkey \-v \# Enable vi mode

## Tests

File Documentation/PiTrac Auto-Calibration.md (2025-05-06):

**PiTrac Auto-Calibration**

This document describes how to set up and use PiTrac’s new (May 2025\) auto-calibration feature.

PiTrac auto-calibration automatically determines the focal length and camera angles of the system.  Previously, these values had to be determined and set manually using a tape measure and an Excel spreadsheet.  PiTrac will use these values to calculate ball locations and–ultimately–final values like ball speed and HSA/VSA.  

Auto-calibration determines the focal length and camera angles empirically.  A physical “calibration rig” is used to position golf balls at known, fixed distances and angles from PiTrac.  The calibration process is then told where those test balls are in space, and the process uses that knowledge to determine the focal length and angles.  The resulting values are written to the current .json configuration file, and are then used when PiTrac operates in its normal launch monitor mode. 

The values that are generated by auto-calibration in the .json file are the following:

       "cameras": {  
            "kCamera1FocalLength": "6.4030723439413677",  
            "kCamera2FocalLength": "6.11",  
            "kCamera1Angles": \[  
                "48.587453708172063",  
                "-20.597432130360897"  
            \],  
            "kCamera2Angles": \[  
                "0",  
                "6.77"  
            \],

**Note** that ***prior to*** performing auto-calibration, PiTrac’s cameras must be correctly focused and the de-distortion matrices should already have been calculated and entered into the configuration .json file.  See the [original calibration document here](https://github.com/jamespilgrim/PiTrac/blob/main/Documentation/PiTrac%20-%20Camera%20Calibration.md).  This newer auto-calibration process just removes all the measuring and math that used to have to be done manually *after* the focusing/de-distortion steps.  Auto-calibration won’t work well if those steps have not already been performed.

Finally, the current calibration rig assumes that the tee-off camera that watches for a ball hit (Camera 1\) is pointed off at an angle.  We hope that will not be required sometime in the future.  If both cameras can be pointed straight ahead, we will likely only use only the single calibration ball that sits straight out in front of the monitor.

**Physical Setup:**

First thing to do is to get your calibration rig printed.  The rig provides an easy way to precisely position two golf balls in front of the launch monitor.  Of course, you could make your own rig – you would just need to make measurements of where the ball(s) are relative to the cameras and inform PiTrac of that through the configuration file. 

1. Print the rig using the [files here](https://github.com/jamespilgrim/PiTrac/tree/main/3D%20Printed%20Parts/Enclosure%20Version%202/Calibration%20Rig) in the github repo.  The rig is in the version 2 enclosure file area, but can be used with either version of the enclosure.  The main difference in using the rig for the Version 1 and 2 enclosures is just the measurement values that describe the distances from where the cameras are to the golf balls positioned on the rig.  The rig looks like the following on the print bed:

   Picture 1_0 - AutoCalibration Instuctions
(Picture 1\_0)

   1. Printing Notes:    
      1. The rig only needs support structure in the green area shown below on the part that positions Ball 1 on the floor.  Otherwise, whatever standard print settings your system uses (e.g., 15% infill) should be fine.  We did not need any print plate glue.  
      2. The rig takes less than 100 grams of filament.  PETG is probably best to reduce any warping, but PLA works fine, too.  
   2. If you make your own rig, consider modelling it in FreeCad or Fusion or so that you can use the 3D modelling tools to determine precise measurements.  See the image of the rig with the 1.0 version of the enclosure, along with estimated distances, second picture, below.  
        
2. Assemble the parts so that the resulting rig looks like:

   Picture 2_0 - Calibration Rig with PiTrac Ver 1 0
(Picture 2\_0)

   1. (NOTE \- the measurements to the balls above are not quite right.  They should terminate in the center of the ball, and they don’t start exactly in the center of the camera lens.  Just having a problem figuring out how to do that in FreeCAD).  
   2. Make sure the pieces are completely pushed together snuggly (they can be a little tight) so that the dimensions are correct.  
   3. The right-most ball in the image above will be referred to as Ball 1 because that ball is the one camera 1 points to (at least in the current version of PITrac).  The Camera 2 ball that is positioned in mid-air is Ball 2\.

3. Rig Alignment  
   1. Placement:  
      1. Version 2.0 enclosure:  
         1. The 2.0 enclosure has a small square hole in the middle of the bottom front side into which the tab of the rig is inserted for alignment.  You’ll still need to make sure the rest of the rig is square to the monitor.  
            Picture 4_1 - PiTrac - Ver 2 Enclosure Rig Positioning
(Picture 4\_1)  
      2. Version 1.0 enclosure:  
         1. The original 1.0 enclosure did not have a mounting/alignment hole for the rig.  Instead, make sure that the tab of the rig closest to the LM is centered underneath the lowest camera.  Place the tab on the diagonal part of the enclosure so that the end edge of the wider part of the rearmost part of the rig is aligned with the outside of the lower part of the enclosure:  
            Picture 4_2 - PiTrac - Ver 1 Enclosure Rig Positioning
(Picture 4\_2)  
   2. For a more precise calibration, use a carpenter’s square (or similar) to make sure that the rig is at right angles to everything on the launch monitor:

     Picture 3_0 - PiTrac Calibration Rig w Square
(Picture 3\_0)

      1. Note that the parts can sometimes print with a bit of a warp.  
4. Aim/align the cameras:  
   1. If not already done as part of the focusing operation, ensure that Camera 1 is pointing directly at Ball 1 and that Camera 2 is pointing slightly below Ball 2, but otherwise straight out from the monitor.  Just do your best – They do not have to be in exact positions, but the calibration accuracy will be better if the cameras are close to pointing directly at the ball.  The whole point of auto-calibration is that it will figure out what the exact angles are.  
   2. Double-check that the two cameras are roughly pointing in the appropriate directions.  Note that the flight Camera 2 is expected to point a little below the Ball 2\.  
   3. Ensure the camera screws are tightened down to prevent any future movement of the cameras after calibration.

**Software Setup:**

1. First, PiTrac needs to be told exactly where each ball will be with respect to the corresponding camera.  This is done by setting the x, y, and z offsets from the center of the camera lens to the center of the golf ball.  Those values must be put into the .json configuration file in the “calibration” section.  
2. For the Version 1.0 Enclosure and the standard calibration rig, these values are shown below:

          "calibration": {

               "Looking out from cameras, positive X distance is to the right, positive y is up, and positive Z is outward": "0",

               "kAutoCalibrationBallPositionFromCamera1Meters": \[

                   "-0.525",

                   "-0.275",

                   "0.45"

               \],

               "kAutoCalibrationBallPositionFromCamera2Meters": \[

                   "0.0",

                   "0.095",

                   "0.435"

               \],

               "kNumberPicturesForFocalLengthAverage": "6",

               "kTestAutoCalibrationFileName": "M:\\\\Dev\\\\PiTrac\\\\Software\\\\LMSourceCode\\\\Images\\\\autocalibrate\_cam1\_still\_picture\_1.png"

   1. You should also sanity check the above values by using a tape measure.

3. As mentioned above, the two sets of measurements shown above are for the Version 1 enclosure and the pre-built calibration rig.  These values were derived by using the measurement tool in FreeCad as shown below:

  Picture 2_0 - Calibration Rig with PiTrac Ver 1 0
(Picture 2\_0)

4. We also have the following measurements for the Version 2.0 enclosure, but these haven’t been tested:

               "kAutoCalibrationBallPositionFromCamera1Meters": \[

                   "-0.504",

                   "-0.234",

                   "0.491"

               \],

               "kAutoCalibrationBallPositionFromCamera2Meters": \[

                   "0.0",

                   "0.088",

                   "0.466"

   1. The above numbers were calculated similarly, from this 3D model:  
      Picture 6_0 - Calibration Rig with PiTrac Ver 2 0
(Picture 6\_0)

5. Next, as a sanity check, we will take a test picture from each camera to its associated ball.  
   1. For camera 1, use the runCam1Still.sh to see how close the ball is to the visual center of the image frame.  That script will output a file named cam1\_still\_picture.png in whatever directory is specified in the environment variable $PITRAC\_BASE\_IMAGE\_LOGGING\_DIR. (e.g., /home/pictrac/LM\_Shares/WebShare)  
      1. You’ll need to ensure sufficient lighting (PiTrac LEDs on) for this picture to work well.  
   2. For Camera 2, you will need to run runCam2Still.sh on Pi 1 as well as runCam2ForAutoCalibration.sh on Pi 2\.  This arrangement is required because (for now), Pi 2 is still the only executable environment that can access Camera 2\.  This process will take longer, but should also output a file cam2\_still\_picture.png as the camera 1 process does.  
   3. Ensure that the focus is good for both pictures.  Examples of good camera 1 and 2 pictures are shown below:  
      Picture 7_0 - Cam 1 - cam1_still_picture Picture 8_0 - Cam 2 Base Autocalibration Image

      (Picture 7\_0 and Picture 8\_0)  
   4. Note that currently the Camera 2 picture tends to be over-saturated from all the strobe pulses hitting the ball in the same place and will probably not look as focused.  
        
6. **Running the Auto-Calibration process**  
   1. The Auto-Calibration process works similarly for cameras 1 and 2, though the second Pi (Pi 2\) is required as well as Pi 1 for calibrating Camera 2\.  
   2. **PRIOR** to running any calibration, make sure you store a copy of your current golf\_sim\_config.json file in a safe place.  Although the original file’s settings should be preserved (except for focal length and camera angles), you never know if some bug could trash your original file.  
   3. **Camera 1**  
   4. Make sure there is a ball on the rig’s positioning pad that is on the floor and in the view of camera 1 looking down on that ball.    
   5. Run the runAutoCalibrateCam1.sh   
   6. The script will first take a series of pictures to find an average focal length.  Next, it will use the last picture taken to calculate the camera’s angles with respect to axes that are orthogonal to the launch monitor.  
      1. Look for a line like the following in the logging file output:  
      2. \[2025-05-05 15:57:30.892196\] (0x00007fff0f7d8040) \[info\] Calibrated focal length for distance 0.744144 and Radius: 53.111847 mm is 6.460002.\[  
   7. The original golf\_sim\_config.json will be saved in a file named in a pattern like: golf\_sim\_config.json\_BACKUP\_2025-May-01\_21.02.20.json.  
   8. The current golf\_sim\_config.json will be updated with the new focal length and the x, y angles for Camera 1 (or 2).  
   9. To make sure things are working, the system will save copies of the pictures it took along with a green circle identifying where PiTrac decided the ball was.  Check to make sure the circle is tightly around the ball.  Decent example pictures are shown below:   

      Picture 12_0 - Cam 1 - kCameraXBallLocation_2
Picture 10_0 - Cam 2 - Focal_Length_Autocalibration_Image_3

      (Picture 12\_0, Picture 10\_0)

   10. Next, as a sanity check, leave the ball where it is and run the script called runCam1BallLocation.sh.  If everything is working, the x, y, z distances to the ball should be very close to the values provided in the golf\_sim\_config.json in the kAutoCalibrationBallPositionFromCamera1Meters parameter.

              "calibration": {

                   "Looking out from cameras, positive X distance is to the right, positive y is up, and positive Z is outward": "0",

                   "kAutoCalibrationBallPositionFromCamera1Meters": \[

                       "-0.525",

                       "-0.275",

                       "0.45"

                   \],

   11. **Camera 2**  
       1. To perform auto-calibration for Camera 2, you do basically the same things as above for Camera 1\.  But, you will need to run the PiTrac script named runCam2ForAutoCalibration.sh on Pi 2 prior to starting the auto-calibration on Pi 1\.  And of course, runAutoCalibrateCam2.sh instead of the version for Camera 1\.  
          1. Because the Camera 2 calibration process relies on the second Pi and camera, it will run much slower than the Camera 1 calibration.  This can be shortened if necessary by reducing the number of picture samples that will be taken to find an average focal length.  That value is stored in "calibration.kNumberPicturesForFocalLengthAverage".  
          2. The runCam2ForAutoCalibration.sh is currently not shutting down by itself at the end of the process, so you will have to Ctrl-C it or otherwise kill the process.

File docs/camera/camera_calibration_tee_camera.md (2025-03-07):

---
title: Tee Camera (top)
layout: home
parent: Calibration
nav_order: 1.1
---

## Tee Camera (Top Camera)

Tee camera distances and angles (also referenced by and relevant for Flight camera process)  

1. Only for Tee camera, plug in the exterior LED strip at the bottom of the launch monitor. For these calibration steps, the more light the better.  
2. Start the `previewGS.sh` script (which runs libcamera.hello) for Tee camera, or `previewGS_noir.sh` script for Flight camera.  This will allow you to see the marker in real time as the camera is positioned and focused.  
3. Pick an appropriate nominal tee-up spot to use as the calibration marker point for flight camera.  The exact placement is not important, but positioning the ball near where it will be teed should help make the calibration more accurate.  
   1. Typical is `60cm` to the right and around `50-60cm` in front of the LM (looking at the LM from where the player would stand, looking down into its cameras). Other distances can work as well, but the balance is between being close enough to get a good view of the ball, and far enough that the field of view is sufficiently broad to capture enough (at least 4) image imprints as the strobe light fires.
4. Use a tape measure to accurately determine the position from the front-center of the LM to the point where the ball will be expected to be teed up as follows:  
   1. Note - The ball will likely be right in front of Flight camera (and a `10-20cm` in the air), but for Tee camera, it will be a couple feet to the right and on the ground.  
   2. Further back (to the right of the LM for right-handed golfers) gives more time for the LM to “see” a fast ball in the Flight camera before it goes too far.  The LM should be able to operate regardless of exactly where the marker point is, but a point close to the typical tee-off makes the calibration in that area more accurate.  
   3. Place a marker (e.g., a sticky-note with a `3mm` dot or crosshair) at the point on the ground where the nominal tee point will be.  If you are calibrating on a hitting mat. A short bit of wire insulation pushed into the hitting mat works well, too.  The point just has to be well enough marked to be able to see it in the center of the preview screen.  
   4. Tee camera Example Setup:  
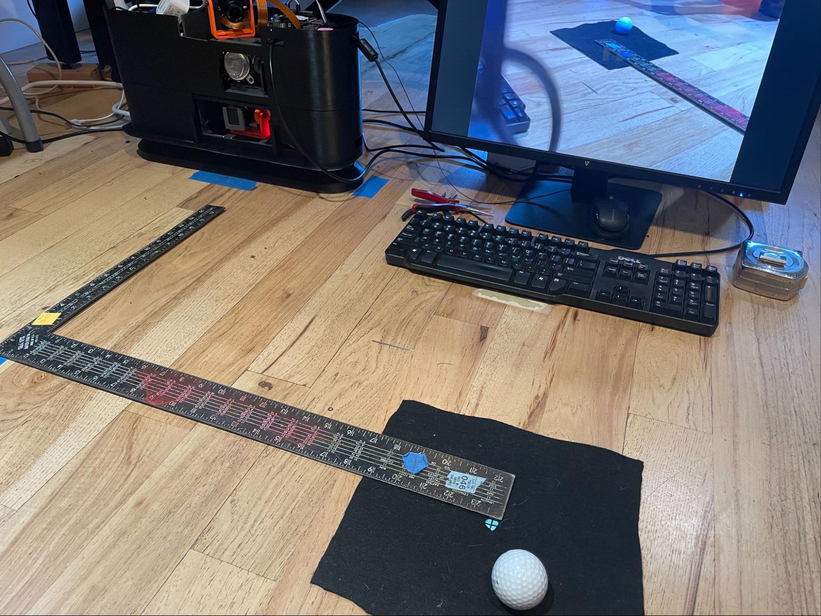
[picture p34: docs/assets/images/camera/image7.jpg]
      - 
5. Loosen and then move the camera mount until the preview screen on the monitor shows the marker dot directly behind the taped-on dot on the monitor.  The idea is to center the marker in the camera view so that the camera is known to be aimed directly at the spot.  Continue to keep the point centered as you tighten the gimbal screws (a small 90-degree M4 hex wrench makes this easier).  
   1. **NOTE** - Sometimes the mount is sticky and only wants to point to a particular point near, but not at the marker.  In that case, let the camera do what it wants to do, and just re-measure where the point is (it might be a few millimeters one way or the other), and then use those measurements, below.  
   2. When tightening the base of the Pi for Tee camera (top floor), you may have to loosen and move the strobe light that is immediately below the camera to get room to use a needle-nose pliers to tighten the bold.   
6. Measure the following distances from the camera being calibrated to the marker. **NOTE** these values have slightly different definitions for Flight camera. Reference that process elsewhere in this document when calibrating that camera.  
   1. Refer to the following diagram regarding the necessary calibration measurements for Tee camera:  
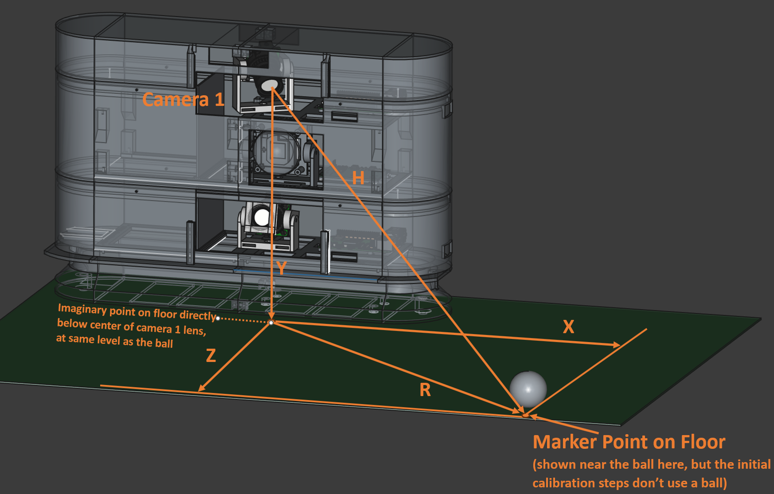
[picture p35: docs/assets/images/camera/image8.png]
   2.  
   3. X is distance to the right of the LM (facing the LM as a right-handed golfer) to the marker point  
      1. `X = .60` (typical) (distances here are in meters)  
      2. For Flight camera, the X should reflect the effective X-axis difference between the two cameras (because Tee camera is twisted to one side from center). So, even if the Flight camera is centered, it’s X is likely to be 3 or 4 cm.  
      3. The “Origin” referenced in the .json file (e.g., `kCamera1PositionsFromOriginMeters` is technically arbitrary, but this system considers it as the point on the floor directly below where the Tee camera (or Flight camera) is focused.  
   4. Y is the distance from the middle of the Tee camera lens to the level of the hitting mat (for Tee camera) or the aiming point (for Flight camera).  
      1. `Y = .275` (typical)    
   5. Z is the distance straight out from the front of the LM unit to the plane of the marker  
      1. `Z = .56` 
   6. R is the distance from the point on the floor directly below the front center of the camera lens to the marker point on the floor (see diagram above).  This is one side of a triangle, with the other two sides being the line from the camera to the point on the floor, and the third side as “H”, below.  
      1. `R = .83`  
      2. NOTE - because of the tilt angle of Tee camera, the point on the floor will technically be hidden below the base of the LM.  Usually, we just measure from the edge of the base and add the additional couple of centimeters to make up for the offset.  For the same reason, the X distance on the floor for that camera will be a few centimeters less than the same point would be for Flight camera   
   7. H is the distance from the camera lens direct (as the crow flies) to the marker point  
      1. `H = .87`  
   8. Set the X, Y and Z values in the configuration .JSON file: (below values are typical)  
      1. (in “cameras” section) `"kCamera1PositionsFromOriginMeters": [ <X>, <Y>, <Z> ]` for example, `[0.60, 0.275, 0.56 ]`,   (x,y and z in cm), and  
      2. `"kCamera1Angles": [ <XDeg>, <YDeg> ]`, for example, `[46.97, -17.44]`  (from spreadsheet)  
   
----

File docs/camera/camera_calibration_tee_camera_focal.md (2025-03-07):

---
title: Determine the cameras focal length 
layout: home
parent: Tee Camera (top)
nav_order: 1.1
---

## Determine the camera’s focal length 

1. Place a ball on or at the marker.    
   1. For Tee camera, the ball will be immediately above the marker.    
   2. For Flight camera, create a support that will hold the ball so that its center in space is where the marker point existed in space before it was replaced by an actual ball.  Put the   
   3. Example setups:  Flight camera:  
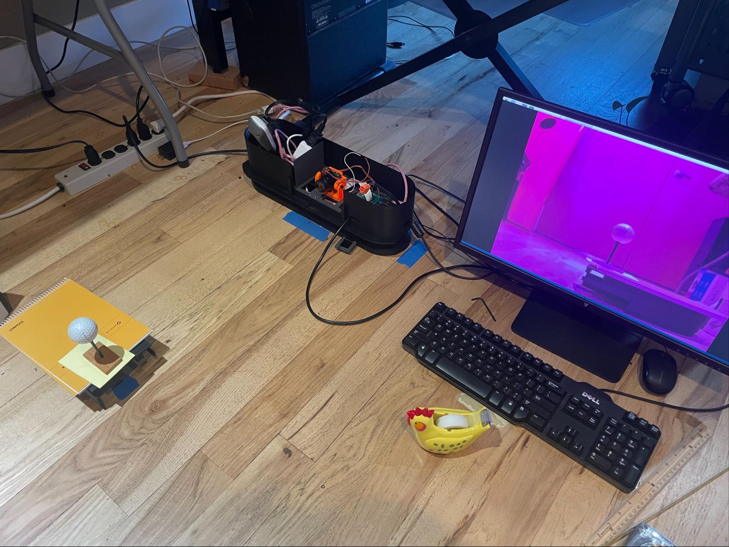
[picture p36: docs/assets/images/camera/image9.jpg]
   4.  
   5. Tee camera:  
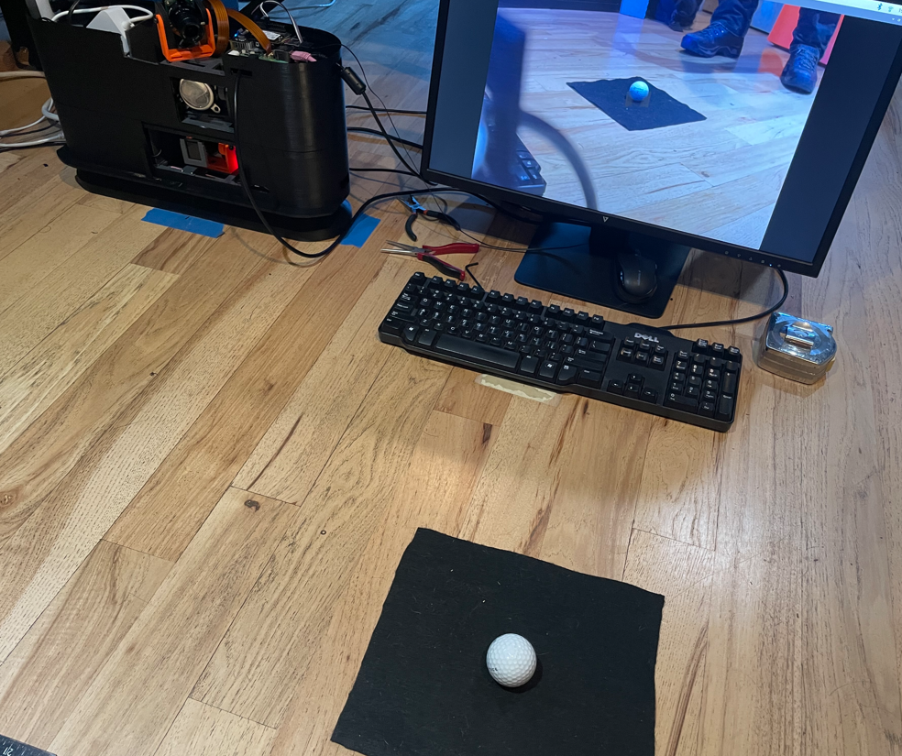
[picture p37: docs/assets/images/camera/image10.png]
   6.  
2. Ensure that the area around the ball has good contrast.  For example, put down some black felt around the ball or use a white ball on a green hitting mat.   
3. For Tee camera, turn the LED strip on the LM base on to make sure there’s sufficient light for good exposures.  
4. Re-Measure H to ensure it’s correct - it is the distance on a line straight out from the camera lens to the ball center (at or near where the marker point was)  
5. Set the H distance into the appropriate parameter in the “calibration” section of the `golf_sim_config.json` file:   
   1. For Tee camera, `"kCamera1CalibrationDistanceToBall"`.  `~87cm` is typical   
   2. For Flight camera, `"kCamera2CalibrationDistanceToBall"`. `~55cm` is typical  
6. For Flight camera, install the light filter and holder on the lens.  
7. Focus the lens as well as possible and lock in the focus by tightening the thumb screw closest to the camera (the other screw should already have been tightened).  Using the brand-marking or number printed on the ball can help this process.  This will establish the focal distance in the next step.  
8. IF NOT ALREADY DONE AT LEAST ONCE, PERFORM CAMERA LENS UNDISTORTION PROCESS (other section) 
9. Ensure the ball is well-lit, especially near its bottom.  
   1. For Flight camera, getting as much sunlight in as possible can help provide sufficient IR to see well, or an incandescent light can also help.  
10. Run the `“runCam1Calibration.sh”` or `“runCam2Calibration.sh”` script to get the focal length.    
      1. It will take multiple measurements and average them.  This will take a minute or so.  
11. Set the resulting focal length into the .JSON file.    
      1. E.g., `"kCamera1FocalLength": 5.216` would be typical  
8. Determine the x & y (pan and tilt) camera1 angles for the configuration .JSON file  
1. [See [https://docs.google.com/spreadsheets/d/1igc2V7oq-hGpFP5AKGjyzc2osLVpYHp969iPyHGttJ8/edit\#gid=423758471](https://docs.google.com/spreadsheets/d/1igc2V7oq-hGpFP5AKGjyzc2osLVpYHp969iPyHGttJ8/edit#gid=423758471) for automatic calculations]  
2. X/pan is positive as the camera twists to face back to where the ball is teed (as the camera goes counter-clockwise viewed from above the LM).    
3. Y/tilt  is negative as the camera starts to face down.   
4. The angles are measured from the bore of the camera if it were facing straight out at no angle and level with the ground  
5. XDeg = 90 - atan(Z/X)   YDeg = -(90 - asin(R/H))   OR, for camera2, YDeg = ATan(Y/R), e.g, atan(4.5/40) = 6.42.   
   1. For example, for Tee camera:  
      1. `XDeg = 56.31 , YDeg = -24.46`  
   2. For example, for Flight camera:  
      1. `X = -0.03  Y = 0.13  Z = 0.40 H = 0.42  R =`    
6. Set the values in the configuration .JSON file:  
   1. (in “cameras” section) `"kCamera1Angles": [ 54.7, -22.2 ]`,   (x,y  or pan, tilt)  
9. Place a ball ball near the mark on the tee-up spot so that there is a straight line from the camera to the mark that runs through the center of the ball (thus the ball will be slightly in front of the marker)  
10. Measure the distances to the center of the ball  
11. In the JSON file, set calibration.kCamera1CalibrationDistanceToBall to the distance to the ball in meters, e.g,. 0.81   
12. Run `“runCam1BallLocation.sh”` script to make sure the angles and distances and processing are correct  
   1. The ball-search location should work in the center:   `--search_center_x 723 --search_center_y 544`. If the script doesn’t return values, check the `log_view_final_search_image_for_Hough.png` file.  
   2. Remember, that the distances will be approximately to the center of the ball FROM THE CAMERA, so will be a little shorter than the distance to the LM in the X direction. 
        
----

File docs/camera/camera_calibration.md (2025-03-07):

---
title: Calibration
layout: home
parent: Cameras
nav_order: 2
---

## Camera Calibration

(the below pictures feature PiTrac in its early incarnation using 2x4s for its enclosure)
<table>
  <tr>
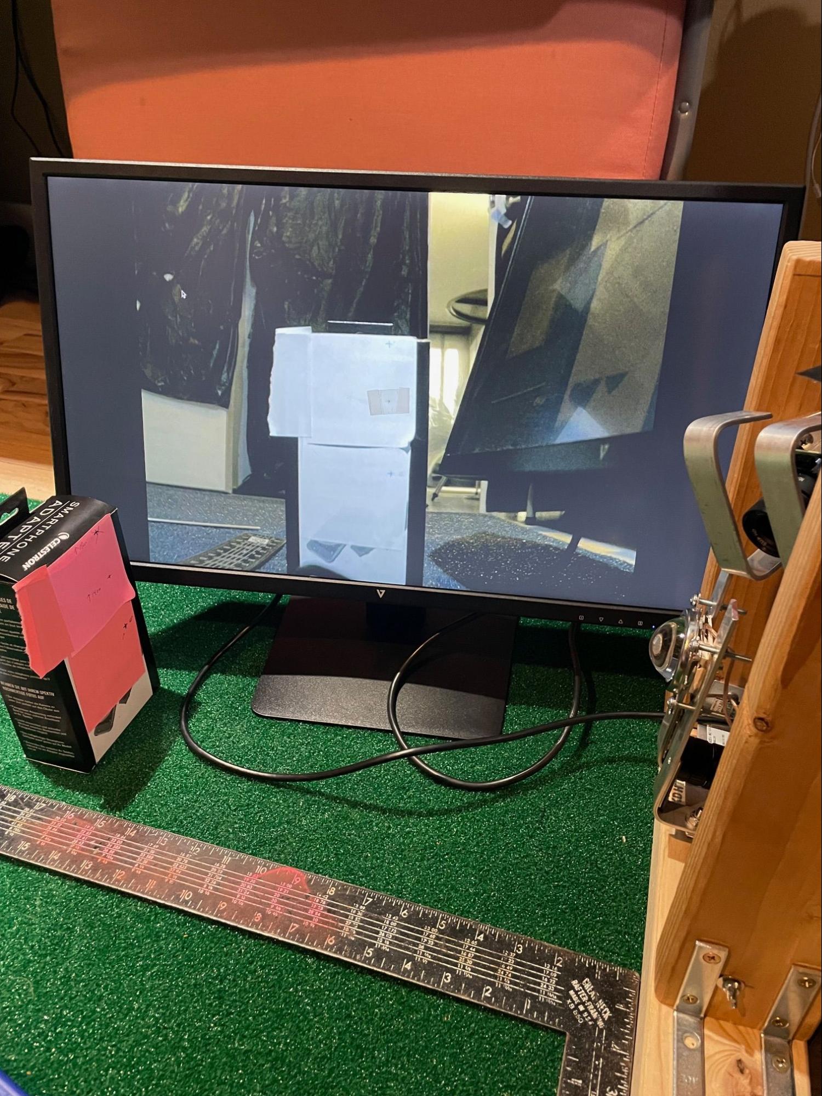
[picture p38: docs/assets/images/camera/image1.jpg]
    <th></th>
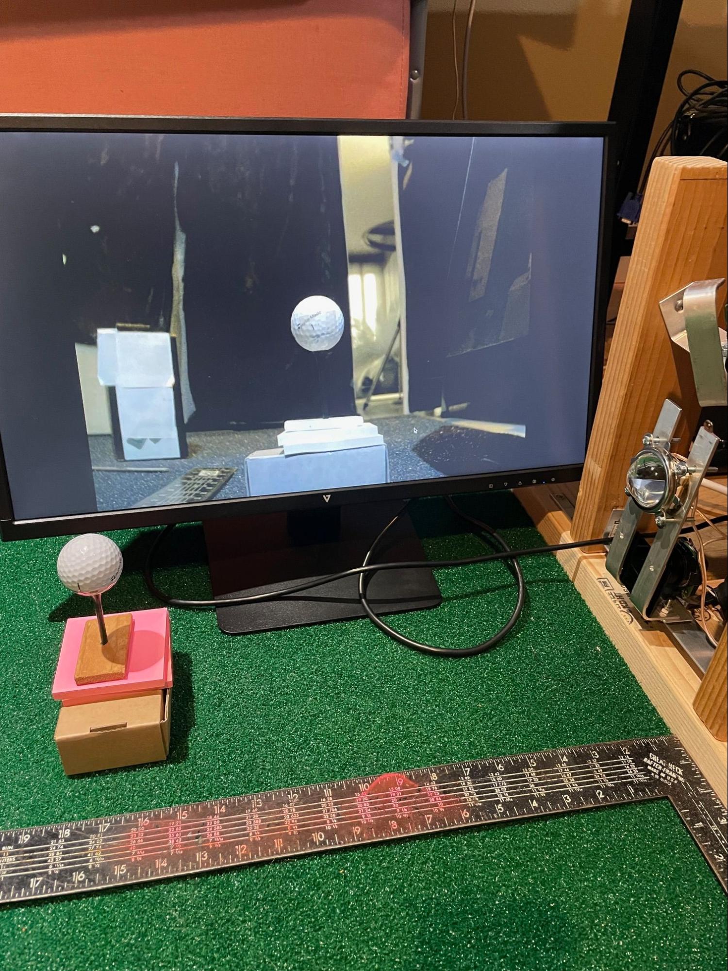
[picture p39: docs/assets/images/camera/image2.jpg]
    <th></th>
  </tr>
  </table>

### Overview

1. The PiTrac system needs to know the angles of the cameras and the relative distances between them in order to locate the ball in space. Camera calibration helps establish these values.

2. During this calibration, various distances are measured from each camera to a test point in front of the camera. Those values are used, along with this spreadsheet (which computes additional, derived values) to determine a set of calibration values. Those values are then given to the PiTrac monitor by entering them in the golf_sim_config.json configuration file, which PiTrac reads when it starts up.

3. The basic idea is to center a known point in 3D space in the camera lens and then measure the distances to that point. That in turn determines the camera’s angles. This process also establishes the effective focal distance of the camera, which in turn is used to establish the distance of the ball from the cameras.

4. After the marker points are used to aim the cameras, an actual golf-ball is used to calibrate focus and focal length.

5. It’s best to calibrate the cameras in the environment in which you expect to use the LM.

6. As part of the calibration process, the fish-eye-like distortions that are caused by most lenses need to be accounted for. These distortions are particularly evident around the edges of an image. Multiple images of a hand-held checker-board pattern are used to determine a couple of matrices that are used by the PiTrac to essentially “undistort” the images taken by the cameras.

7. The distances in this guide are in meters unless otherwise specified.

8. Note that “calibration” as used in this document is a broader process than just the intrinsic/extrinsic calibration that sets up matrices to perform de-distortion on cameras (although undistortion is a part of it).

----

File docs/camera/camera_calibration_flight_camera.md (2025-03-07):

---
title: Flight Camera (bottom)
layout: home
parent: Calibration
nav_order: 2.1
---

## Flight Camera

1. Note Flight Camera (bottom camera) closely follows the Tee Camera (Top Camera) calibration  
2. Lens Un-Distortion  
3. Measuring Distances and Angles  
    1. Remove the visible-light cut (long pass) filter from the front of the camera for now. It’s easier to calibrate the camera in the visible light spectrum.  
    2. Ensure that the triggering for the camera is not in external mode (where it usually will be when the Flight camera system is running).    
        - If necessary, do: `sudo /CameraTools/setCameraTriggerInternal.sh`   
    3. Set up a marker point (such as a cross hairs) on a piece of paper attached to an object or stand so that the point is about 15 cm above the ground and roughly centered in the view of the camera with the camera at a slight upward tilt and facing straight out.  The point should be a shape that will be crisp, sharp, and useful for focusing the camera.  
    4. Follow the instructions for Tee Camera (read that first), below, but use the following modifications when recording the various measurements:  
    5. 
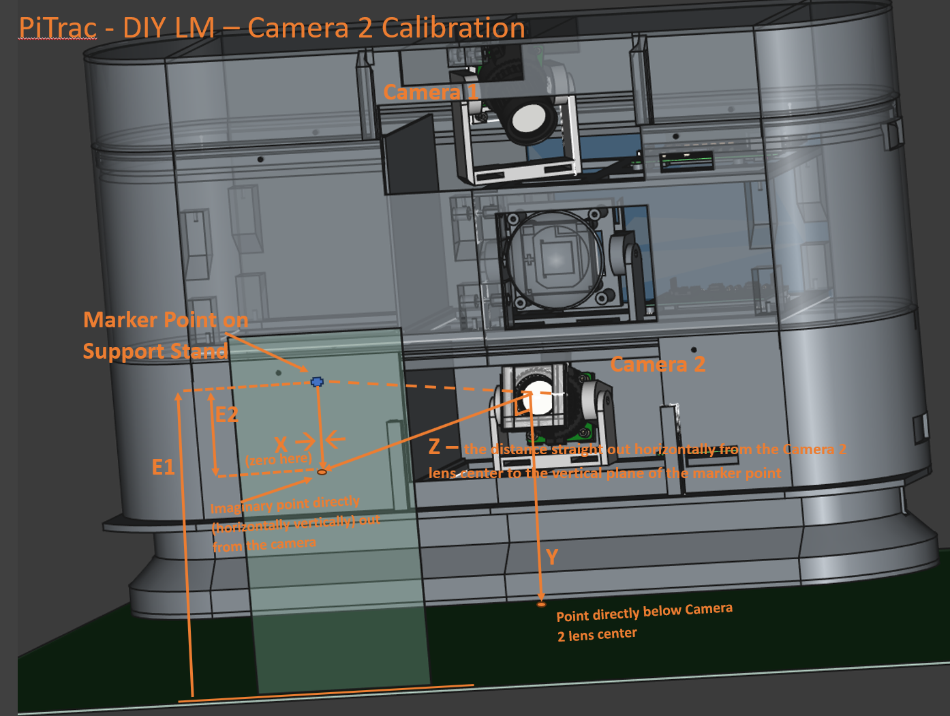
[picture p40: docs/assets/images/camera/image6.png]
       
    6. Flight Camera Measurements (values are typical/exemplary)  
    7. -X (the negative value of X) is the distance to the left (looking at the monitor) from the point on the floor directly under the center of *Flight camera* (facing the LM as a right-handed golfer) to the marker dot. ***It’s usually 0*** because the point will be centered (horizontally) in the camera’s view. Because this is relative to the OTHER camera, X will usually effectively be `~-3` or `–4` centimeters away from the other camera because the Tee camera is offset because it is twisted.    
        1. This will be made up later when we set the 
        `"kCamera2OffsetFromCamera1OriginMeters" parameter: [ **0.03**, -0.19, 0.0 ],`
        2. `X = 0.0` (typical) 
    8. Y is the distance from the center of the Flight camera lens to the level of the hitting mat (for Tee camera)  
        1. `Y = .109`  (typical)  
    9. Z is the distance ***straight out horizontally-level*** from the front of the lens to the vertical plane of the marker.  This measurement is ***not*** “as the crow flies” in a straight line from the lens to the marker point.  See pictures.  The front of the camera lens is `~1cm` back from the bottom of the base, which may be helpful if you are measuring from the bottom of the base.  
        1. `Z = .55` (typical)  
    10. E1 is the elevation from the floor or mat to the marker point in the air. Somewhat above the Y value.  
        1. `E1 = 0.16` 
    11. E2 is the elevation from Flight camera to the marker point in the air.  E2 will be entered into the PiTrac JSON configuration file as the 2nd parameter for e.g.,  `"kCamera2PositionsFromOriginMeters": [ 0.0, **-0.051,** 0.46 ]`  
        1. `E2 = E1 - Y = 0.051`.  
        2. This will help calculate the YDeg angle.  However, because of measurement inaccuracy, it may still be necessary to manually adjust that angle. [TBD]  
    12. H is the distance from the camera lens directly (as the crow flies) to the marker point.   
        1. `H = .56`
    13. In the Calibration Spreadsheet, `X_Degrees` will normally be `0` (camera facing straight out).  Conversely, `Y_Degrees = ATAN(E-Y)` and will usually be around `5` degrees (camera tilted slightly upward in order to catch fast-rising balls) (`5.3` degrees for the above example values)  
    14. Otherwise, this process same as for Tee camera, but due to the (typical) either horizontal or up-facing camera, will have to create a marker-aiming spot in mid-air by drawing on a box or something that can be propped up in front of the Flight camera  
    15. Enter the following data into the JSON file:  
        1. `"calibration.kCamera2CalibrationDistanceToBall": <Z>`  (e.g., 0.55)  
        2. `"cameras.kCamera2PositionsFromOriginMeters": [<X>, -<E2>, <Z> ]`  
        3. `"kCamera2Angles": [ <XDeg>, <YDeg, e.g. 6.3 degrees> ]`,  (from spreadsheet)  
        
----

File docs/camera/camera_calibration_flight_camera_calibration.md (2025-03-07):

---
title: Camera Calibration Confirmation
layout: home
parent: Flight Camera (bottom)
nav_order: 2.3
---

## Camera Calibration Confirmation
1. Keep the ball in the spot it was in when the focal length was calibrated for now, as the location is known.  We want to ensure the system is ‘finding’ the ball at that location.  
2. Run `“runCam2BallLocation.sh”` script on the Pi connected to the camera being calibrated to make sure the angles and distances and processing are correct  
    1. Generally, the IR filter should be removed if the ball does not have good contrast with the background.  
    2. The ball-search location should work in the center: `--search_center_x 723 --search_center_y 544`. If the script doesn’t return values, check the `log_view_final_search_image_for_Hough.png` file.  
    3. Remember, that the distances will be approximately to the center of the ball FROM THE CAMERA, so will be a little shorter than the distance to the LM in the X direction.  
    4. Check to make sure that the X, Y, and Z values (in meters) are correct.  
    5. Also, the “Radius” measurement that is output by the program should remain pretty close to the same number from measurement to measurement.  So, for example,   
    1. `[2024-12-05 15:43:57.884875] (0x0000007f8ea3d040) [info] Found Ball - (X, Y, Z) (in cm): 0.013771, 0.060536, 0.552454`. **Radius: 67.741455**  
    2. `[2024-12-05 15:44:00.758463] (0x0000007f8ea3d040) [info] Found Ball - (X, Y, Z) (in cm): 0.013772, 0.060538, 0.552480`. **Radius: 67.738266**
    3. `[2024-12-05 15:44:03.616166] (0x0000007f8ea3d040) [info] Found Ball - (X, Y, Z) (in cm): 0.013772, 0.060539, 0.552489`. **Radius: 67.737129**  

3. To ensure everything is working correctly, trying moving the ball 10cm up  and/or left or right and/or closer or further from the camera and then ensure that the runCam2BallLocation program responds with correct position information.  Accuracy should be at least within a centimeter for most measurements.

----

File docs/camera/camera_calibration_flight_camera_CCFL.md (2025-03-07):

---
title: Calibrate Focal Point Length
layout: home
parent: Flight Camera (bottom)
nav_order: 2.2
---

## Calibrate Camera Focal Length 
1. Calibration requires that the LM be turned on. When you do so, first check to make sure that the LED strobe is not on. You can tell if it is on because the LEDs will glow a dull red (even for IR LEDs, there’s a little light on the high-frequency end of the visible spectrum).  
2. Next we will calibrate the focal length of the Flight camera by using the known diameter of a golf ball and the diameter of the ball as seen by the camera in terms of pixels.  
    1. Use the “Determine the camera’s focal length” process for Tee camera, below  
3. Run `runCam2BallCalibration.sh` script and take the resulting average focal length.  Make sure the ball is well lit with a good contrasting color behind it (use the preview function if necessary)  
    1. Certain types of black felt also show up black behind the ball and create great contrast.  
    2. If you get errors, such as “Attempted to draw mask area outside image”, check to ensure the golf ball is in the middle of the camera image.  
    3. Check for the images in the `logging.kLinuxBaseImageLoggingDir` directory. Can also try `--logging_level=trace` instead of info in the script.  
    4. After the final average value has been computed, you may have to hit Ctrl-C to stop the program  
    5. Also, the `Calibrated focal length` measurement that is output by the program should remain pretty close to the same number from measurement to measurement.  So, for example (ignore the “mm”),   
    1. `[2024-12-05 15:50:42.048685] (0x0000007fb6135040) [info]` Calibrated focal length for distance `0.550000` and Radius: `67.788940` is **6.094049**mm.  
    2. `[2024-12-05 15:50:42.048996] (0x0000007fb6135040) [info]` Focal Length = **6.094049**.  
    3. `[2024-12-05 15:50:43.441564] (0x0000007fb6135040) [info]` Calibrated focal length for distance `0.550000` and Radius: `67.803833` is `6.095388mm`  
    4. If the value is varying largely, the lighting may not be sufficient.  
4. Enter this value into the JSON file, e.g., `"kCamera2FocalLength": 6.155454` (or whatever the value is).  

----

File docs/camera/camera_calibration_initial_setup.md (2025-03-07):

---
title: Initial Setup
layout: home
parent: Calibration
nav_order: 1
---

## Camera Initial Setup

1. Use a lens-cleaning cloth and appropriate cleaning liquid to make sure the lens are spotless.  
2. If possible, make sure the Pi computers are hard-wired into the network and the network switch (if any) is turned on.  
3. Before doing anything, log into the system remotely and perform a sanity check to make sure the camera is up and running correctly.  For example, take a picture using:  
    - `PiTracCameraTools/lcGS.sh test.jpg // TODO missing` 
    - So long as a picture is taken, things are probably operating correctly.  
4. Attach a keyboard, mouse and monitor to whatever Pi Camera is being calibrated using the front and side Pi Access ports on the monitor’s walls.    
    - If your Pi is set up to display a terminal clearly on a different computer (such as using VNC viewer), you may be able to avoid this connection.  
5. If the monitor does not come up with an image after the mouse is wriggled, it may be that the system was booted at a time that the monitor was not present.  In that case, reboot.  

6. Place a small piece of transparent tape onto your monitor screen, with a dot on it so that the dot is positioned to be at the exact center of the screen.  This dot will be referred to as the “marker dot”, and its role is simply to indicate where the center of the image is.  If this dot is at the same point as some feature that the camera sees, that feature is in the center of the camera’s view. Some people will use a remote terminal program like VNC Viewer instead of connecting a monitor directly to the Pi.  In this case, just make sure that you monitor aspect ratio and any window borders will not skew the true center calibration spot.  

7. Loosen the thumb screws on the lenses (if necessary) and rotate the lens to the full-open aperture position.  For the 6mm lens in the parts list, the aperture screw is the one furthest from the camera.  Tighten the aperture screw back down and loosen the focus screw. 

----

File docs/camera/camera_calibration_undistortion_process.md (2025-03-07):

---
title: Camera Lens Undistortion Process
layout: home
parent: Calibration
nav_order: 2.3
---

## Camera Lens "Undistortion" Process

A camera lens undistortion process involves first calibrating the camera to determine the lens distortion parameters (like radial and tangential distortion coefficients), then using those parameters to mathematically map the distorted pixels in an image to their correct positions, creating an undistorted output image; this typically requires capturing images of a known pattern (like a checkerboard) to accurately calculate the distortion parameters.

Camera Calibration and Geometry. Basics of camera geometry and how it can be used to calibrate cameras. 

<iframe width="640" height="420" src="https://www.youtube.com/embed/_-BTKiamRTg" frameborder="0" allowfullscreen></iframe>

- Here is another video performing a camera calibration in OpenCV using python in VS Code: 
<iframe width="640" height="420" src="https://www.youtube.com/embed/H5qbRTikxI4" frameborder="0" allowfullscreen></iframe>

1. The undistortion code and scripts are under the `CalibrateCameraDistortions` folder.  The scripts rely upon the libcamera-still utility, so make sure that is working first.  
2. Print out a copy of the `7x10` square checker board included in that directory on a sheet of paper. Note that you want to print it to scale.  Mount the checkerboard on a piece of cardboard or slip it into a binder so that you can easily hold it and it will stay flat.    
3. When calibrating Flight camera, adding a bright incandescent light can provide additional IR light to help make the images clearer. Also, change the tuning file in the `take_calibration_shots.sh` script from:  
   1.  `--tuning-file=/usr/share/libcamera/ipa/rpi/pisp/imx296.json`  to  
   2.  `--tuning-file=/usr/share/libcamera/ipa/rpi/vc4/imx296_noir.json` (the _noir is only applicable for Flight camera)  
4. When calibrating Tee camera, ensure the room is well lit. Turning on the LED strips on the LM often produces too much light and reflection.  
5. To take the pictures, make sure your camera is focused at the distance of where the ball will be.  It’s best to have the Pi console window visible so that you can see when to move the board and avoid blurs.   
6. Next, we need a bunch of images of the checkerboard at about the distance we expect the golf ball to be imaged by the cameras.  These images should include the board in the middle and nearer the edges of the images, and must each include all of the checkerboard, not just a part of it.  
7. Sample setup   
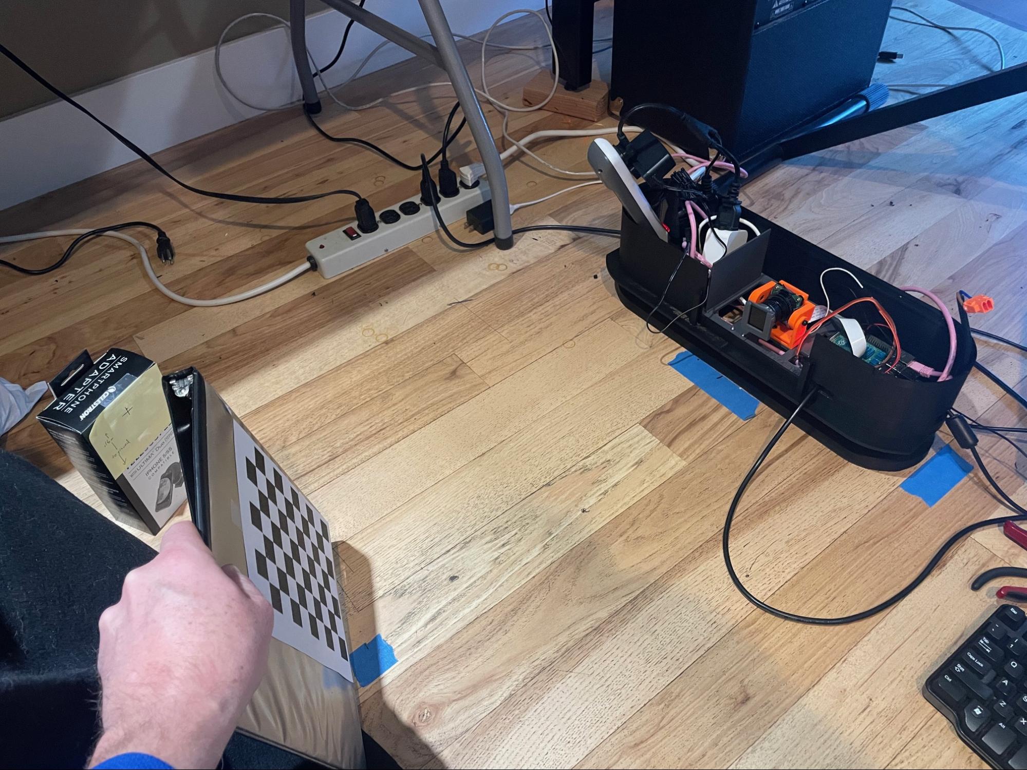
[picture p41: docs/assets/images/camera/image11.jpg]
   1.    
8. Then, run the `take_calibration_shots.sh` script, specifying, for example, `./images/cam1` as the output directory.  Twenty pictures is usually sufficient.    
   1. → `mkdir images/cam2` for flight camera 
   2. → `take_calibration_shots.sh` ./images/cam2/gs_calibation_20`  
9. The script will repeatedly pause and take a picture and save it to the output directory.  Each time the script says “READY”, quickly move the checkerboard to a new location.  Each move, try to rotate the board a little bit about the image plane so that it is in a different orientation each time.  Also, try tilting the board a little forward and back randomly.  This should result in a set of images that are named `gs_calibrate_<nn>`, where nn is an increasing number. The images should look like:  
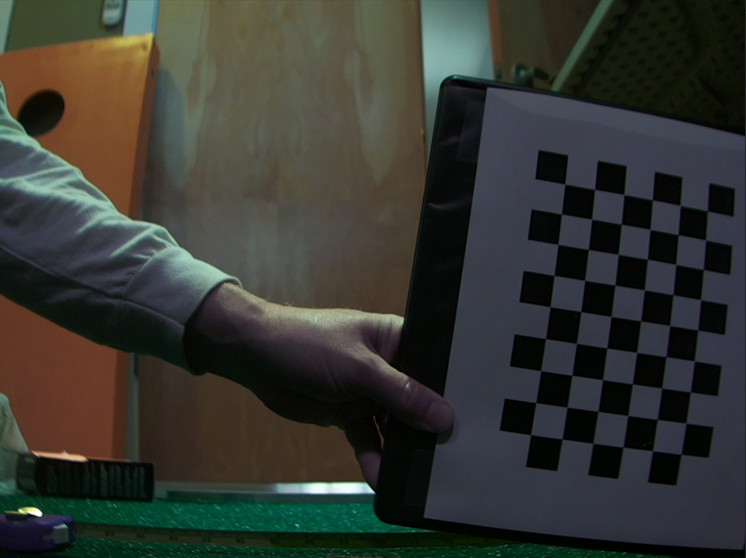
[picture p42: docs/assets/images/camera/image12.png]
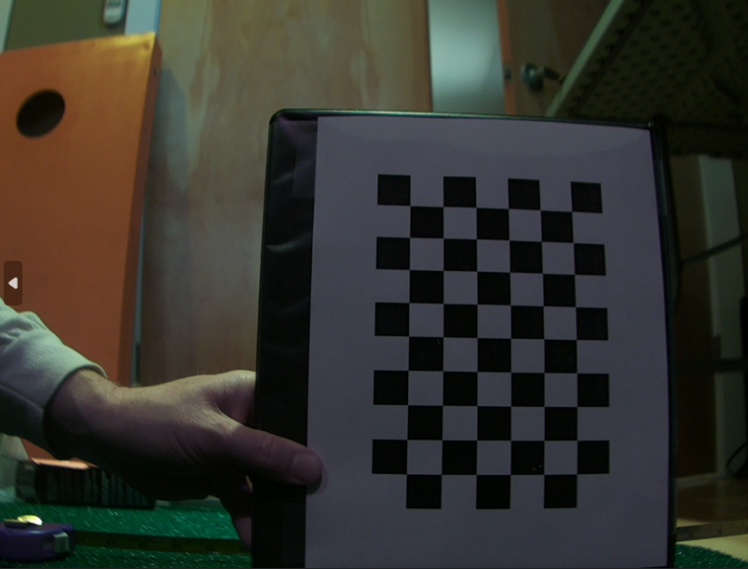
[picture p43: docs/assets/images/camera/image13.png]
10. 
11. Look through the images and delete any where the checkerboard is not fully visible.  Partially-visible board can stall the next step of this process.
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

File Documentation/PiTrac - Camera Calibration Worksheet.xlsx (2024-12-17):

See the Calibration Instructions here: https://github.com/jamespilgrim/PiTrac/tree/main/Documentation for how to use this worksheet.
Camera 1
X | 0.6 |  | X_Degrees: | 46.97
Y | 0.275 |  |  |  | Alternative calculation - Y_Degrees
Z | 0.56 |  | Y_Degrees | -18.33 |  | -17.44
H | 0.87
R | 0.83
Camera 2
X | 0 |  | X_Degrees: | 0.00
Y | 0.109 |  | Y_Degrees | 5.30
Z | 0.55
H | 0.56
E1 | 0.16
E2 | 0.051 | (calculated)

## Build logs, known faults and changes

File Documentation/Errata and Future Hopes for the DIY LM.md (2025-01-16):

**Errata and Future Hopes for the DIY LM**

**Errata:**

* The LM is not enabled for left-handed golfers.  This is embarrassing, but we simply haven’t had the time to complete this capability. And we have no left-handed friend golfers to test it.  In addition, the Camera 1 has to be pointed the other direction to make this work (at least currently).  Repositioning that camera is not easy.  Better cameras and faster processing and triggering of Camera 2 in the future may not need this side-tilt at all, and would make it much easier to be non-handist..  
* Very low, worm-burner shots are often not analyzed correctly, because the system loses the ball in the hitting mat background visual noise.  
* Highly-angled shots that end up with the ball very close to or relatively far from the LM are often not processed correctly, as the ball is not well-focused.  
* Need to get rid of all the compile warnings when building in Visual Studio.  They’re mostly long/int conversion type warnings.

**New Features:**

1. Slow-motion motion club impact (GitHub Issue \#34)  
2. Auto-calibration.  Set the cameras off in some reasonable directions, place a ball at a known spot, and let the system do the rest.

**Future Hopes:**

* Reliability  
  * The system is totally dependent on good circle detection of the sometimes-overlapping strobed ball images.  And the OpenCV Hough transform that we’re using is terribly touchy and often performs poorly in recognizing what (to the human eye) are the most obvious circles in the image.  We really need to improve this.  When the Hough transform is not working well, it really hobbles the entire system.  
  * The strobe-ball image processing is just too complex and hard to understand and maintain.  
* Testing  
  * Complete automated regression testing in an extensible test suite, including against a static stash of images with known outcomes  
  * Manual QA testing checklist instructions for IRL swing testing accompanied by non-interfering third-party LMs  
  * Automated performance benchmarks  
  * Perform side-by-side testing with a good radar-based LM  
* Power Supply  
  * The current retail-power-adapter strategy isn’t working well, and is probably much more expensive than it needs to be.  We need a custom-ish power supply that can plug into wall-outlet AC and put out all the various voltages that are needed.  Would be great if this power supply could put out the constant-current DC 12V needed for the strobe light as well.  
  * We need a power switch\!  And a switch for the external LED strip, too.   
* Enclosure  
  * Easier-to-join enclosure halves.  It’s hard to get to the bolts to tighten the halves together  
  * The supports for the lower-power-side floor’s overlap joint are a pain to remove.  Maybe print at a different angle?  
  * The seams on the 3D printed enclosure are unsightly.  Would be great to be able to print in a way that makes it look a little more professional.  Maybe more lap joints?  
  * Access to the Pi’s is difficult even with the ports..   
  * The inter-floor screws currently overhang into the layer interiors, which might present a safety issue.  Perhaps add a little bump on the side of the inner wall that the screws can end into.  
  * Removing the supports on the power-side floor lap joint is painful.  Is there a better design or way to print?  
  * Mount the Pi(s) to a tray we can slide them into the enclosure on rails, and use a screw to hold it in.  Note \- We'd need longer camera ribbons  
* Cameras  
  * Calibration is too difficult and takes too much time.  How to improve?  
  * As new, higher-resolution global shutters come onto the market, it will be great to integrate them into the system.   Maybe we won’t need the angled Camera 1 in order to watch the teed-up ball\!  
  * The field of focus is too narrow.  A better lens might help.  
  * Having a variant of PiTrac that uses a high frame-rate / low shutter time would be a great option for builders who don’t mind paying a little more for the LM.  This could obviate the need for a second camera and Pi, and would also make it a lot easier to switch between right and left-hand golfers.  
    * In fact, as GS cameras come down in price, this may be the direction the entire project heads to.  
* Documentation  
  * Switch to something like Doxygen for a lot of the project documents  
  * Create UML-like class structure definitions.  
  * Document the top 5 issues and see if we can get folks to fix them\!  
    * An easy add would be to figure out the Carry value.  
* Strobe:  
  * The 12V power supply for the LEDs seems like overkill given the short pulses that PiTrac uses.  Do we even need a constant-current  supply?  Could we just use a cheap 12V AC adapter for a couple dollars?    
  * Could we over-drive the LEDs by a few volts to get brighter pulses?  This would help with a number of things, including picture sharpness for fast balls.  Most LED’s can handle higher voltage for short periods of time without significantly shortening their lifespans.  
* Hardware:  
  * Must the Connector Board really have its own 5V power source?  Is there a better circuit that will protect the Pi’s from the 12V source and each other?  Can we run the board from the 12V supply?  
  * A fail-safe (temperature based? Dead-man timing?) for the strobe light to make sure it never stays on would be a great safety feature.  
* Performance (Speed)  
  * The time between when the ball is hit and when the picture-taking and strobe-pulsing starts is too long.  The ball has already moved halfway across the field of view.  A faster FPS camera would help, of course.

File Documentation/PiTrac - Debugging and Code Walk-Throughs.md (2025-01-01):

**PiTrac \- Debugging and Code Walk-Throughs (Non-Pi Build/Run Environment)**

**TBD \- THIS DOCUMENT IS UNDER CONSTRUCTION**

This document is for folks who:

* Don’t have a Raspaberry Pi and haven’t assembled a physical PiTrac, but still want to look into how the code works.  
  *  Or doesn’t work.  Sometimes the latter. :/  
* Saw some unexpected results from PiTrac and want to figure out what went wrong.  
  * For example – Why is the calculated speed 659.75 mph?  Did I really hit the ball with a forward spin of 454,623 RPM?  Why didn’t the system “see” my shot correct?  And so on…  
* Would like to develop and test some improved algorithms for ball identification or spin analysis, etc. without doing so on the actual Pi-based LM.  
  * Boy, would we love that to happen…

NOTE \- Running the PiTrac system in Windows is something you’d probably only do if you’re reasonably proficient with C++, Visual Studio, and debugging work in general.  And we hope there’s some of those folks on the project\! 🙂

So how does this work?  Well, if you already have a PiTrac and want to work on a particular problematic set of camera images, the primary work flow is:

1. Crank up the logging in the system running on the Pi’s in order to produce more intermediate image artifacts so we can figure out where things go wrong.  
2. Use some of those images as input to a debugging version of the system.  The debugging environment is typically running in Visual Studio on a PC, or a Mac-based system.  
3. Use the debugging environment to bypass having to use the cameras to take a picture, and instead focus on the post-picture processing.  In this environment, it’s easy to step through the code, produce additional image artifacts, and generally figure out what’s going on.  
4. Try different processing parameters (in golf\_sim\_config.json or elsewhere) and/or change the source code to make improvements.  
5. If necessary, use one of the workbench programs to play with the processing parameters in real time to see what works best.  Then take those settings an import into PiTrac

If you don’t have a physical Pi and PiTrac, you’ll just need a couple example images, which can be found here.

**Prerequisites:**

In order to build the PiTrac code in a non-Pi environment, you’ll need to set up a few things.  These instructions will focus on Windows, but the Mac should be similar.

1. Install Visual Studio (we’re using the 2022 Preview currently)  
     
2. Install OpenCV 4.10  
     
   1. You can just download the binaries at [https://opencv.org/releases](https://opencv.org/releases).  Building the source locally has its advantages for debugging, but takes a while.  Instructions are [here](https://docs.opencv.org/4.x/d3/d52/tutorial_windows_install.html)  
   2. [This site](https://christianjmills.com/posts/opencv-visual-studio-getting-started-tutorial/windows/) has some good information on installation and setup

3. Install Boost, for example the pre-build windows libraries from [here](https://sourceforge.net/projects/boost/files/boost-binaries/) (though you can also download the source and build it yourself).  
   1. If you’re using the pre-built package, just unzip it

4. Setup the Windows VS project to point to the correct include and library directories  
     
   1. In VS, go to Project/ImageProcessing Properties:  
        
   2. 

      1. For example:    E:\\Dev\_Libs\\opencv\\build\\include;E:\\Dev\_Libs\\boost\_1\_87\_0  
   3. Point to the correct libraries:  
      

      1. For example, E:\\Dev\_Libs\\opencv\\build\\x64\\vc16\\lib\\opencv\_world4100d.lib;$(CoreLibraryDependencies);%(AdditionalDependencies)  
         * \[NOTE \-The \*d.lib is for debug libraries.  If not debugging, then remove the “d”.  And do not mix \* and \*d \!

   4. In the Linker→General→Additional Library Directories, add:  
      1. 

      2. For example:  E:\\Dev\_Libs\\opencv\\build\\x64\\vc16\\lib;E:\\Dev\_Libs\\boost\_1\_87\_0\\stage\\lib  
   5. Set up the compiler defines that help pick the correct boost bindings:  
      1. 

      2. BOOST\_BIND\_GLOBAL\_PLACEHOLDERS;BOOST\_ALL\_DYN\_LINK;BOOST\_USE\_WINAPI\_VERSION=0x0A00;\_DEBUG;\_CONSOLE;%(PreprocessorDefinitions)  
   6. Point to the correct run-time binaries and libraries:  (and note that the suggested opencv instructions cited above do not use this step and instead copy files around (less desirable)  
        
   7. 

      1. For example, PATH=%PATH%;E:\\Dev\_Libs\\opencv\\build\\x64\\vc16\\bin;E:\\Dev\_Libs\\boost\_1\_87\_0\\lib64-msvc-14.3

2. Setup the command-line parameters (for example):  
   1.

   2. For example, the following is a good starting place for stepping through how the Pi1/Camera 1 system processes the golf ball images.  
      1. \--show\_images 1 \--lm\_comparison\_mode=0 \--logging\_level trace   \--artifact\_save\_level=all \--wait\_keys 1 \--system\_mode camera1\_test\_standalone  \--search\_center\_x 800  \--search\_center\_y 550  
   3. The above set of command line params is a good setting for debugging, because the “--wait\_keys 1” will allow you to step through the intermediate debugging images by hitting any key to continue, but without having to step through all the code that creates those images. It’s useful to set a breakpoint just before where you think there’s a problem, and then let the program run, but sort of throttle the system by having the wait\_keys setting allow you to visually understand what happened before that break point (at a high level).  
      1. NOTE \- The key-press pauses for the images can sometimes interfere with the debugging console window (which is also processing keystrokes).  
   3. The :” \--search\_center\_x 800  \--search\_center\_y 550” tells the system where to look for the teed-up ball.  It will have to be set consistent with whatever teed-up-ball-image you’re using here.  
   4. Set Tools-\>Options-\>Debugging-\>Automatically close the console so the console window (and any important messages) does not go away immediately at the end of the program.

2. To test, compile everything with Ctrl-Shift-B and then hit F10 to step into the first line of the program and see where it goes from there\!

**Example use of the Windows/Mac Visual Studio Development Platform**

Let’s try a real-life example from a problem in a relatively brightly-lit test environment where the system was not locating all of the balls that it should have.  For this test, the config file logging parameters look like:

"gs\_config": {

"logging": {  

	"kLogIntermediateExposureImagesToFile": 1,  

	"kLogIntermediateSpinImagesToFile": 0,  

	"kLogWebserverImagesToFile": 1,  

	"kLogDiagnosticImagesToUniqueFiles": 0,  

	"kLinuxBaseImageLoggingDir": "/home/\<PiTracUserName\>/LM\\\_Shares/Images/",  

	"kPCBaseImageLoggingDir": "M:\\\\Dev\\\\PiTrac\\\\Software\\\\LMSourceCode\\\\Images\\\\"  

},

With those settings, a particular shot produced on an actual PiTrac generated the following image files in \~/LM\_Shares/Images on the Pi’s.  If you don’t have any images, there are some similar examples in the PiTrac/Software/Images directory.

log\_cam2\_last\_strobed\_img:  


ball\_exposure\_candidates:  


Spin\_ball\_1\_gray\_image1 and spin\_ball\_2\_gray\_image1:  


You should also have an image of where the teed-up ball was, as this particular example is going to try to go through all the processing, including calculating where the ball was initially (and then, later, in comparison to the strobed balls.  A typical starting image is something like:  
gs\_log\_img\_\_log\_ball\_final\_found\_ball\_img.png


 (we often just reuse some old starting image if we’re just focused on debugging the strobed image processing.  
NOTE \- The teed-up picture does have some interaction with the downstream strobed-image processing.  The teed-up image gives the system an idea of how far from the monitor the ball is starting.  That Z-axis value is then used to choose a range of ball-radii to be looking for in the strobed picture.

The strobed picture looks fairly solid, but at least two questions come to mind:

1. Why didn’t PiTrac identify the two ball images between No. 3 and No. 4?  
2. Why did the system decide to compare balls 1 and 2 for spin analysis instead of 2 and 3 which appear to be clearer?  In particular the spin\_ball\_1\_gray\_image1 has some weird coloration, probably from some overlap from golfer’s leg behind the ball.

In order to figure this out, we’ll use the picture from cam 2 as input to the processing pipeline and then follow that pipeline to figure out what’s wrong.

The following instructions are for Visual Studio 2022 in Windows, but should be similar for other platforms.

1. Move the relevant images (above) to whatever your kPCBaseImageLoggingDir is.  
     
2. Open the Visual Studio solution for PiTrac.  This is the file PiTrac.sln in PiTrac/Software/  
     
3. Tell the system about what image(s) you are going to use as test input. For our case, where we’re using the above images, we’ll set both of the test input files to the same file name.  In the golf\_sim\_config.json file, set:  
     
   1. "testing": {  
      1. "kTwoImageTestTeedBallImage": "gs\_log\_img\_\_log\_ball\_final\_found\_ball\_img.png",  
   2. "kTwoImageTestStrobedImage": "log\_cam2\_last\_strobed\_img.png",

4. In the lm\_main.cpp file, setup the code to run a “testAnalyzeStrobedBalls()” test.  That test will basically go through all of the processing that the Pi 1 system would do once it received an image from the Pi 2 system.  
     
   1. Near the bottom of the run\_main function (\~line 1653\)  
   2. // Comment in whichever tests you want to run in Windows here    
   3. testAnalyzeStrobedBalls();  

2. Set a break-point at the start of the testAnalyzeStrobedBalls() function and hit F5 to run.  
     
   1. NOTE \- You may have to do a little debugging to make sure the code gets to that function first.  
   2. 

2. Another good place to put a break-point to start is here at bool GolfSimCamera::ProcessReceivedCam2Image  
     
3. 

4. After stepping through the Teed-up ball processing in GetCalibratedBall(), the system will start into the strobed image processing.  
     
5. In our case, the initial identification ball circles (which uses a technique called Hough identification) results in the following:  
     
6. 

7. This is ***not*** a good start.  It’s likely there will be some missed-ball identifications, such as those near the bottom of the screen (which should be filtered out later), but we may want to see if we can provide better settings to improve this starting point.  
     
8. To help out debugging and tuning there are some “Playground” projects that we’ve created that allow a user to try out different settings for the Hough Circle Detection and other processes.  These are essentially copies of some of the pertinent code from the main project into a little project that is easier to manipulate.  
     
9. To use the playgrounds effectively, you’ll first want to take the parameters that are being used in the PiTrac process that you’re debugging and then import those settings into the Playground so that you can, well, ‘play’ with them to figure out how to get a better result.  
     
10. In our case, we set a breakpoint at the call to cv::HoughCircles() in ball\_image\_proc.cpp, or else just make sure debug logging is set to “trace”, and look in the resulting trace log for the parameters that are printed out just before the HoughCircles call.  
      
    1. \[2024-12-30 11:20:37.495892\] (0x00005aa8) \[trace\] Executing houghCircles with currentDP \= 1.700000, minDist \= 18, param1 \= 130.000000, param2 \= 96.000000, minRadius \= 48, maxRadius \= 120  
    2. Note that the system uses an adaptive technique where some of the more sensitive parameters such as param2 are adjusted until there are a reasonable number of circles being returned (usually around 20, but this can be configured in the PiTrac .json file).

Hough Circle Detection Playground:

2. In the “main” method of playground.cpp, set kBaseTestDir and the kTestImageFileName variable to an image of interest.  For example, the same image and test directory we were just using above.  
     
3. Next set the initial trackbar values to the same values used in the HoughCircles call, above.  This is done by setting the similarly-named constants near the top of the Playground.cpp file such as:  
     
   1. int kStrobedEnvironmentHoughDpParam1Int \= 17;  //  Will be divided by 10 if using HOUGH\_GRADIENT\_ALT.   Either 1.7 or \*1.8\* tremendously helps the accuracy\! 1.9 can work ok for external.  1.3 is good for stationary ball (cam1)  
   2. int kStrobedEnvironmentBallCurrentParam1Int \= 130;  
   3. int kStrobedEnvironmentBallMinParam2Int \= 28; // 60 for external  
   4. int kStrobedEnvironmentBallMaxParam2Int \= 140;  
   5. int kStrobedEnvironmentBallStartingParam2Int \= 96;  
   6. int kStrobedEnvironmentBallParam2IncrementInt \= 4;  
   7. int kStrobedEnvironmentMinimumSearchRadiusInt \= 48; // 59; //  60;  // gets bad fast as this widens.  I'd try 56 and 85 for now  
   8. int kStrobedEnvironmentMaximumSearchRadiusInt \= 120;  // 148;  // 80;

2. When you run the playground, several windows will come up, showing the pre-HoughCircles filtered image and the resulting identified circles.  This image should be identical to the image you would see in the main PiTrac code (assuming the Playground code is the same in relevant part).  
     
3. At this point, you can try changing the code (in this case we changed the “HOUGH::GRADIENT” method to be “HOUGH::GRADIENT\_ALT” instead) moving the sliders in the control window to see what effect the altered parameters have on the results.  For our example, we found that changing the value of the “” helps a lot.  
     
4. The result was:  
     
   1. 

2. Finally, the new parameters are pushed into the golf\_sim\_config.json file to see how they work in the actual PiTrac LM.  Note that some of the values are scaled, such as the Hough Param2, which is 100 times smaller for the HOUGH::GRADIENT\_ALT method, and the DpParam1 which is always 10 times smaller.  
     
   1. "kStrobedBallsUseAltHoughAlgorithm": 1,

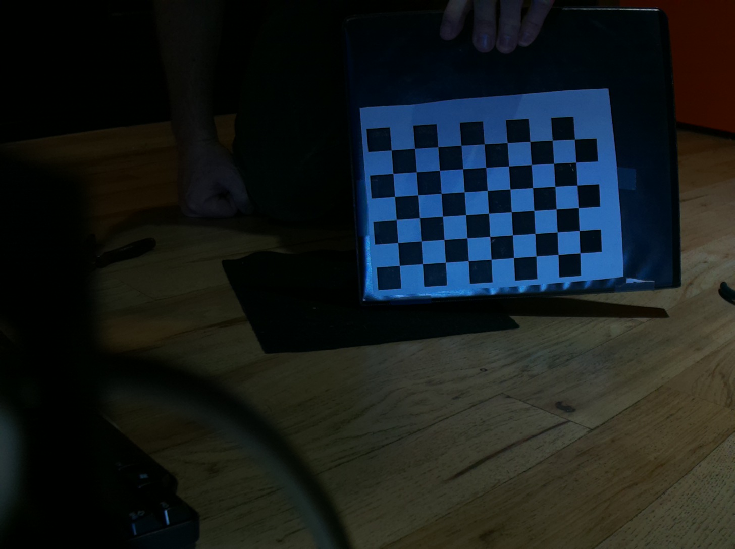
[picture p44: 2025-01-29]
Software/CalibrateCameraDistortions/images/ProblemPix/gs_calibation_2.png

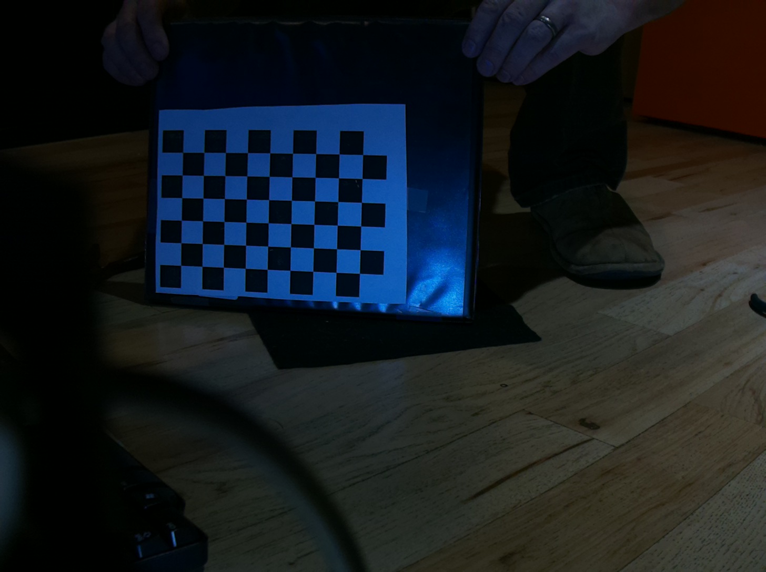
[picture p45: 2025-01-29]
Software/CalibrateCameraDistortions/images/ProblemPix/gs_calibation_4.png

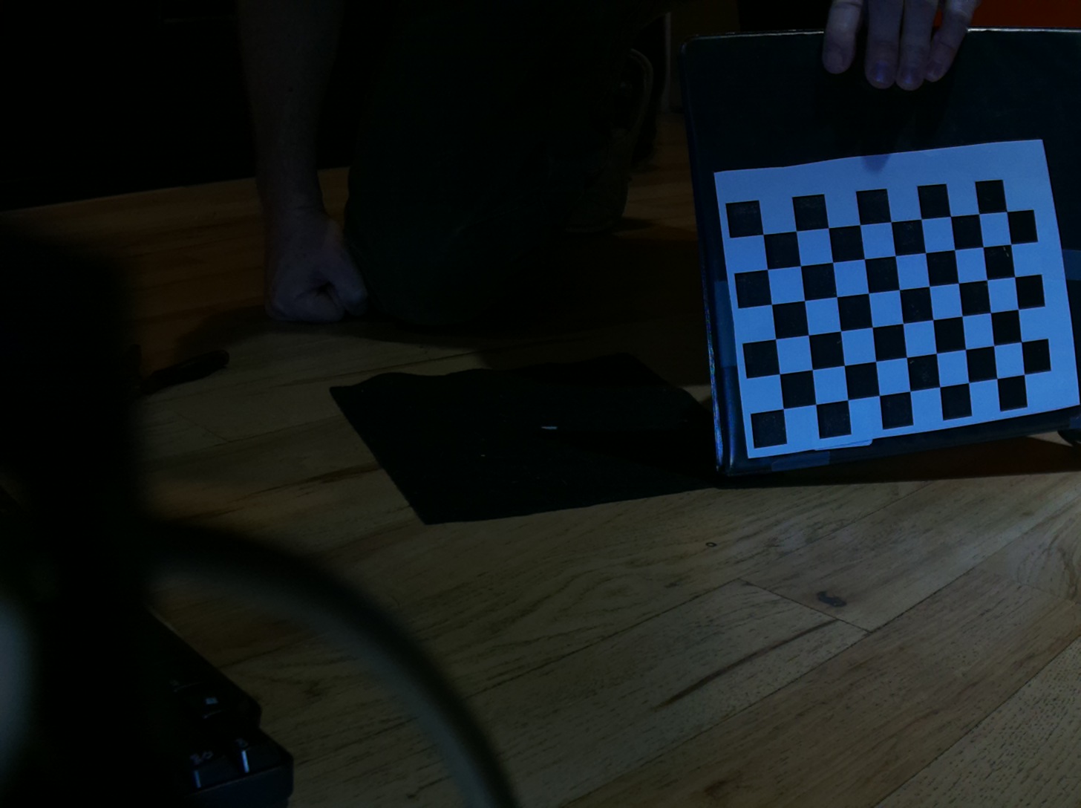
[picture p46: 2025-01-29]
Software/CalibrateCameraDistortions/images/ProblemPix/gs_calibation_1.png

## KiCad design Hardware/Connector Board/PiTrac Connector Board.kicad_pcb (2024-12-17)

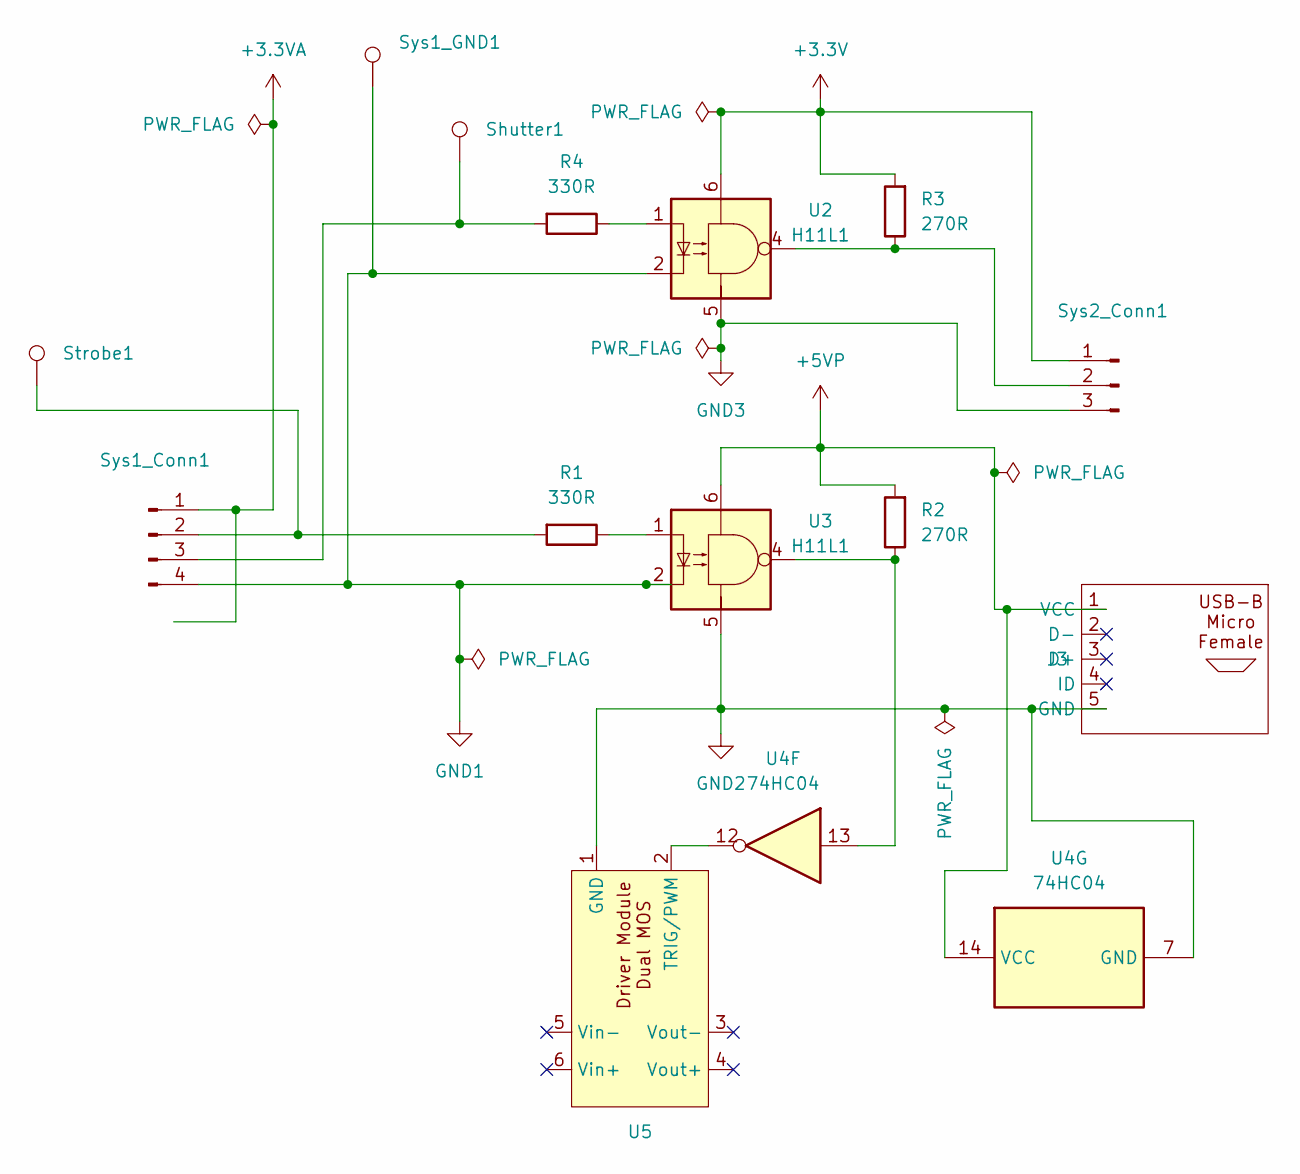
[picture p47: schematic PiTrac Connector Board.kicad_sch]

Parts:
J3: Micro_USB_B_Female
R1, R4: 330R; R_Axial_DIN0207_L6.3mm_D2.5mm_P10.16mm_Horizontal
R2, R3: 270R; R_Axial_DIN0207_L6.3mm_D2.5mm_P10.16mm_Horizontal
Shutter1: TestPoint_THTPad_2.5x2.5mm_Drill1.2mm
Strobe1: TestPoint_THTPad_2.5x2.5mm_Drill1.2mm
Sys1_Conn1: PinHeader_1x04_P2.54mm_Vertical
Sys1_GND1: TestPoint_THTPad_2.5x2.5mm_Drill1.2mm
Sys2_Conn1: PinHeader_1x03_P2.54mm_Vertical
U2, U3: H11L1; DIP-6_W7.62mm
U4: 74HC04; DIP-14_W7.62mm_Socket
U5: PCB Dual MOS Driver Module

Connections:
+3.3V: R3.2, Sys2_Conn1.1, U2.6
+3.3VA: Sys1_Conn1.1
+5VP: J3.1 (VCC), R2.2, U3.6, U4.14 (VCC)
GND1: Sys1_Conn1.4, Sys1_GND1.1, U2.2, U3.2
GND2: J3.5 (GND), U3.5, U4.7 (GND), U5.1 (GND)
GND3: Sys2_Conn1.3, U2.5
unnamed: R1.1, U3.1
unnamed: R2.1, U3.4, U4.13
unnamed: R4.1, U2.1
unnamed: R1.2, Strobe1.1, Sys1_Conn1.2
unnamed: R4.2, Shutter1.1, Sys1_Conn1.3
unnamed: R3.1, Sys2_Conn1.2, U2.4
unnamed: U4.12, U5.2 (TRIG/PWM)

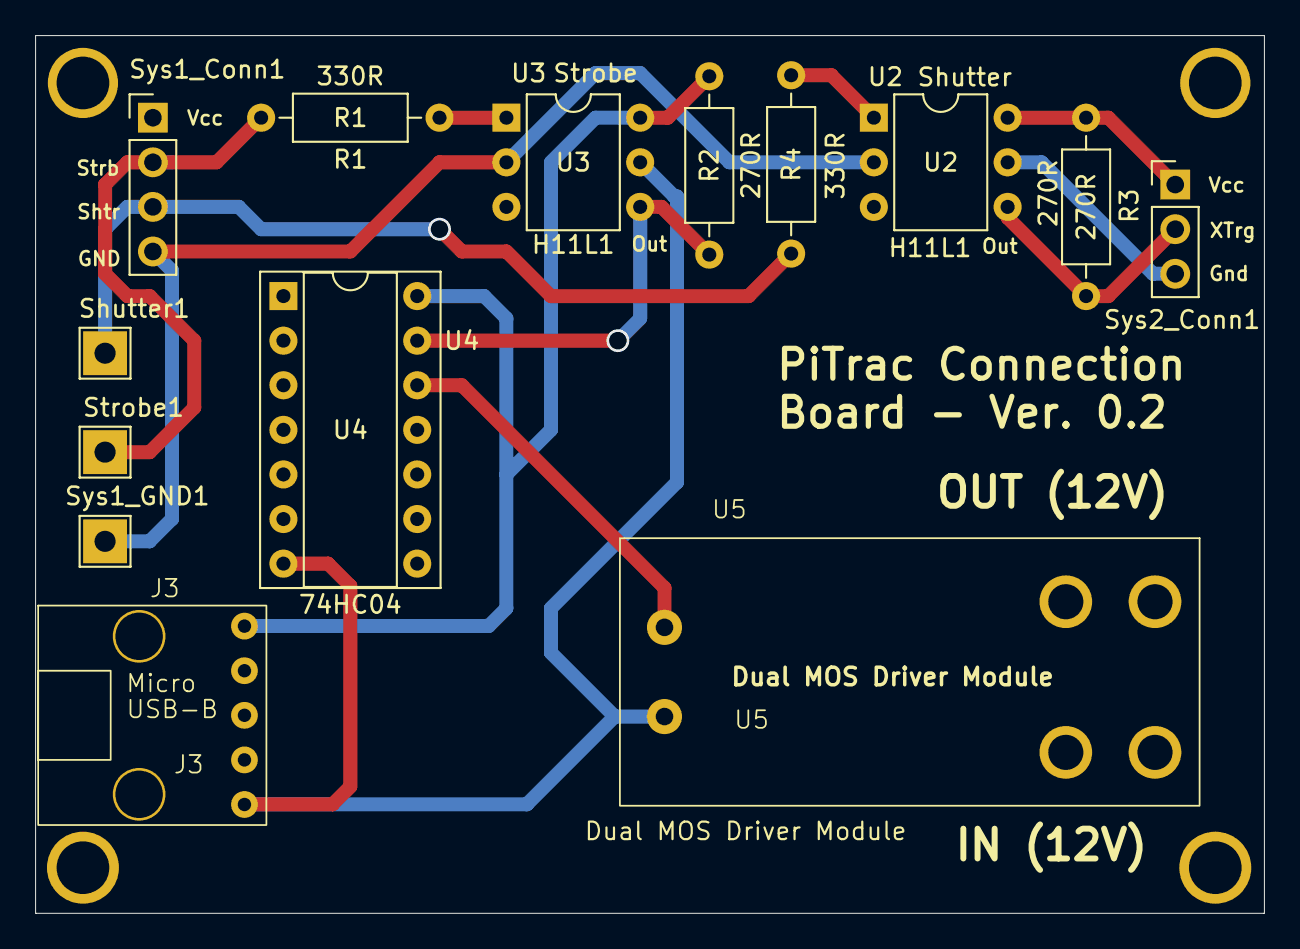
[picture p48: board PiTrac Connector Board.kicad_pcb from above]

Board: 2 copper layers, 70.0 x 50.0 mm, 14 parts (0 on the bottom side), 12 nets.

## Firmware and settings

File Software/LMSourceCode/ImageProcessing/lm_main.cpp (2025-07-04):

/* SPDX-License-Identifier: GPL-2.0-only */
/*
 * Copyright (C) 2022-2025, Verdant Consultants, LLC.
 */

// ImageProcessing.cpp { This file contains the main test function. Program execution begins and ends there.
//

#include <boost/timer/timer.hpp>

#include <opencv2/calib3d/calib3d.hpp>

#include <iostream>
#include <cstring>
#include <filesystem>

#include "gs_globals.h"
#include "golf_ball.h"
#include "gs_options.h"
#include "gs_gspro_results.h"
#include "gs_ui_system.h"
#include "gs_config.h"
#include "gs_results.h"
#include "gs_camera.h"

#include "logging_tools.h"
#include "colorsys.h"
#include "ball_image_proc.h"
#include "cv_utils.h"
#include "gs_camera.h"
#include "gs_config.h"
#include "pulse_strobe.h"


#include "gs_gspro_results.h"
#include "gs_gspro_test_server.h"
#include "gs_gspro_response.h"
#include "gs_sim_interface.h"
#include "gs_e6_interface.h"
#include "gs_automated_testing.h"

#include "gs_fsm.h"
#include "gs_ipc_system.h"
#include "libcamera_interface.h"


namespace fs = std::filesystem;

using namespace golf_sim;

const double kLocationTolerancePercent = 10;


// The result files we create will be prefixed with this
static constexpr std::string_view TEST_IMAGE_PREFIX = "TEST_RESULT_GetBall_";

std::string kBaseTestDir = "Will be set from the .json configuration file";


BallImageProc *get_image_processor() {
    BallImageProc  *ip = new BallImageProc;
    // TBD - Setup as necessary
    return ip;
}


void test_image(std::string_view subdir, std::string_view filename) {
    BOOST_LOG_FUNCTION();

    fs::path dir(subdir);
    fs::path file(filename);
    fs::path fullPath = dir / file;
    std::string fname = fullPath.generic_string();

    GolfBall ball;

    boost::to_lower(fname);
    size_t i = fname.find("clr-");

    std::string color;
    if (i > 0) {
        color = fname.substr(i);
    }

    if (!color.empty()) {

        boost::to_lower(color);

        if (color.find("white") > 0) {
            ball.ball_color_ = GolfBall::BallColor::kWhite;
        }
        else if (color.find("orange") > 0) {
            ball.ball_color_ = GolfBall::BallColor::kOrange;
        }
        else if (color.find("yellow") > 0) {
            ball.ball_color_ = GolfBall::BallColor::kYellow;
        }
        else if (color.find("green") > 0) {
            ball.ball_color_ = GolfBall::BallColor::kOpticGreen;
        }
        else {
            // For this part of our test suite, if there is no specified color, white(not kUnknown) is our best bet
            ball.ball_color_ = GolfBall::BallColor::kWhite;
        }
    }

    BallImageProc *ip = get_image_processor();

    cv::Mat img = cv::imread(fname, cv::IMREAD_COLOR);
    ip->image_name_ = fname;

    cv::Rect nullROI;
    std::vector<GolfBall> return_balls;
    bool result = ip->GetBall(img, ball, return_balls, nullROI, BallImageProc::BallSearchMode::kFindPlacedBall );

    if (!result || return_balls.empty()) {
        GS_LOG_MSG(error, "GetBall() failed to get a ball.");
        return;
    }

    GolfBall result_ball = return_balls.front();

    // If there were any debugging windows, get rid of them now
    cv::destroyAllWindows();

    // Create a single output file with the result overlaid on the original image, along with
    // whatever other debug images that we want.

    /******  THIS FUNCTION SHOULD BE DELETED - TBD 
    cv::Mat outputImage;

    auto ncFinalArray = nc::NdArray<nc::uint8>(ip->final_result_image_.data, ip->final_result_image_.rows, ip->final_result_image_.cols);
    auto ncCandidatesArray = nc::NdArray<nc::uint8>(ip->candidates_image_.data, ip->candidates_image_.rows, ip->candidates_image_.cols);
    auto ncOutputImage = nc::hstack({ ncFinalArray, ncCandidatesArray });

    outputImage = CvUtils::ConvertNDArrayToMat(ncOutputImage);

    fs::path outputDir(subdir);
    fs::path outputFile(std::string(TEST_IMAGE_PREFIX).append(filename));
    fs::path outputFullPath = outputDir / outputFile;
    std::string outputFileName = outputFullPath.generic_string();

    cv::imwrite(outputFileName, outputImage);

    LoggingTools::ShowImage(fname, outputImage);
    ****/
}

void test_certain_images() {

    test_image("./Images/", "FakePiCameraPhotoOfGolfBall-Clr-Green-Flat.png");
    test_image("./Images/", "WedgeNextToOrangeBall-Clr-Orange.png");
    test_image("./Images/", "FirstPiV1CamBall-Clr-Yellow.jpeg");
    test_image("./Images/", "AboutToBeHitLoRes-Clr-White.jpg");
    test_image("./Images/", "JustHitByIronToRight-Clr-White.png");
    test_image("./Images/", "JustHitSlightBlurClub-Clr-White.png");
    test_image("./Images/", "WedgeNextToOrangeBall-Clr-Orange.jpg");
    test_image("./Images/", "HitClubGoneWithFlyingTee-Clr-White.png");
    test_image("./Images/", "IMG_7713-Clr-Yellow.jpg");
}



void WalkDirectoryTree(const fs::path& pathToScan, int level = 0) {
    for (const auto& entry : fs::directory_iterator(pathToScan)) {
        const auto filenameStr = entry.path().filename().string();
        if (entry.is_directory() && (filenameStr.find("IGNORE") != std::string::npos) ) {
            // Recurse to any sub-directories
            WalkDirectoryTree(entry, level + 1);
        }
        else if (entry.is_regular_file()) {
            if (((filenameStr.find(".png") > 0) &&
                (filenameStr.find(".jpg") > 0) &&
                (filenameStr.find(".jpeg") > 0)) &&
                ((filenameStr.find("IGNORE") == std::string::npos) &&
                    (filenameStr.find("TEST_IMAGE_PREFIX") == std::string::npos))
                ) {
                test_image(pathToScan.generic_string(), filenameStr);
            }
        }
        else
            std::cout << "(ignoring)" << filenameStr << "\n";
    }
}

void test_all_test_files() {
//    std::string rootdir = "D:/GolfSim/C++Code/GolfSim/ImageProcessing/Images";
    std::string rootdir = "D:/GolfSim/TestPictures";


    WalkDirectoryTree(rootdir);
}

void test_calibrated_location(std::string twoFootImgName, std::string threeFootImgName, std::string fourFootImgName) {
    
    cv::Mat img = cv::imread(twoFootImgName);
    LoggingTools::ShowImage(twoFootImgName, img);

    // Test of the GetCalibratedBall function
    GolfSimCamera c;
    GolfBall b;

    std::vector<cv::Vec3d> camera_positions_from_origin = std::vector<cv::Vec3d>({ GolfSimCamera::kCamera1PositionsFromExpectedBallMeters, GolfSimCamera::kCamera2PositionsFromExpectedBallMeters });
    bool success = c.GetCalibratedBall(c, img, b);

    // Now, test the calibration by seeing if the same ball can be found using the calibrated ball
    GS_LOG_TRACE_MSG(trace, "GET BALL LOCATION AGAIN FOR 2 FEET");
    GolfBall newBall;
    success = c.GetCurrentBallLocation(c, img, b, newBall);

    if (!threeFootImgName.empty()) {
        // This original HSV masking range from the calibration is not working well.Try a lower H ?
        // b.ball_hsv_range_ = [(0, 0, 175), (175, 102, 255)]
        GS_LOG_TRACE_MSG(trace, "GET BALL LOCATION FOR 3 FEET");
        img = cv::imread(threeFootImgName);

        // TBD - Consider the fact that the ball should be no larger than the radius of the last found
        // ball, and should have that ball"s average color
        success = c.GetCurrentBallLocation(c, img, b, newBall);
        // TBD _ FIX b.average_color_, b.median_color_, b.std_color_ = cu.GetBallColorRgb(c.img, newBall.ball_circle_)
    }

    if (!fourFootImgName.empty()) {
        GS_LOG_TRACE_MSG(trace, "GET BALL LOCATION FOR 4 FEET");
        img = cv::imread(fourFootImgName);
        success = c.GetCurrentBallLocation(c, img, b, newBall);
    }
}



bool testProjection() {

    cv::Mat ball1Img, ball2Img;
    GolfBall ball1, ball2;


    std::string kBaseTestDir = "D:\\GolfSim\\C++Code\\GolfSim\\ImageProcessing\\";


    // We prefer the command-line setting even if there's one in the .json config file
    if (!GolfSimOptions::GetCommandLineOptions().base_image_logging_dir_.empty()) {
        kBaseTestDir = GolfSimOptions::GetCommandLineOptions().base_image_logging_dir_;
    }
    else {
        // Attempt to get the image logging directory from the .json config file
#ifdef __unix__
        GolfSimConfiguration::SetConstant("gs_config.logging.kLinuxBaseImageLoggingDir", kBaseTestDir);
#else
        GolfSimConfiguration::SetConstant("gs_config.logging.kPCBaseImageLoggingDir", kBaseTestDir);
#endif
    }


    const std::string k0_DegreeBallFileName_00 = kBaseTestDir + "test_ball_masked_0_deg_dulled.png";
    const std::string k45_DegreeBallFileName_00 = kBaseTestDir + "test_ball_masked_45_deg_dulled.png";

    ball1Img = cv::imread(k0_DegreeBallFileName_00, cv::IMREAD_COLOR);
    ball2Img = cv::imread(k45_DegreeBallFileName_00, cv::IMREAD_COLOR);

    /*
    gfilters = create_gaborfilter()
    image_g = apply_filter(myimage, gfilters)
    
    min_interval = 120
    max_interval = 250
    image_edge_g = cv2.Canny(image_g, min_interval, max_interval)

    // Create a simple matrix of 3D points
    // cv::Mat<> test3DPoints{ {0,0,1} }

    std::vector<cv::Point3i> test2DPoints{ {0,0,1}, {1,0,0} };
    */
    return true;
}

void showVisualization() {
    /* TBD - probably too much work to get Viz working 
    ///Createawindow 
    viz::Viz3dmyWindow("VizDemo"); 
    ///Starteventloop 
    myWindow.spin();

    ///Eventloopisoverwhenpressedq,Q,e,E cout<<"Firsteventloopisover"<<endl; 
    ///Accesswindowviaitsname 
    viz::Viz3dsameWindow=viz::getWindowByName("VizDemo"); 
    /// ///Starteventloop 
    sameWindow.spin(); 
    /// ///Eventloopisoverwhenpressedq,Q,e,E
    cout<<"Secondeventloopisover"<<endl;
    /// ///Eventloopisoverwhenpressedq,Q,e,E
    /// ///Starteventlooponcefor1millisecond
    sameWindow.spinOnce(1,true);

    while (!sameWindow.wasStopped()) {
        ///Interactwithwindow

        ///Eventloopfor1millisecond
        sameWindow.spinOnce(1,true);
    }
    */
}


bool testSpinDetection() {

    /*
    const std::string k0_DegreeBallFileName_00 = "test_ball_spin_strong_landmarks_00d_3280w_bright_00.png";
    const std::string kUnknown_DegreeBallFileName_00 = "test_ball_spin_strong_landmarks_14d_3280w_bright_00.png";

    const std::string k0_DegreeBallFileName_00 = "test_ball_spin_strong_landmarks_00d_2592w_bright_01.png";
    const std::string kUnknown_DegreeBallFileName_00 = "test_ball_spin_strong_landmarks_08d_2592w_bright_01.png";

    const std::string k0_DegreeBallFileName_00 = "test_ball_spin_strong_landmarks_00d_2592w_bright_00.png";
    const std::string kUnknown_DegreeBallFileName_00 = "test_ball_spin_strong_landmarks_45d_2592w_bright_00.png";

    const std::string k0_DegreeBallFileName_00 = k"test_ball_spin_strong_landmarks_00d_2592w_bright_01.png";
    const std::string kUnknown_DegreeBallFileName_00 = "test_ball_spin_strong_landmarks_35d_2592w_bright_01.png";

    const std::string k0_DegreeBallFileName_00 = "test_ball_spin_strong_landmarks_00d-x_3280w_bright_02.png";
    const std::string kUnknown_DegreeBallFileName_00 = "test_ball_spin_strong_landmarks_15d-x_3280w_bright_02.png";

    const std::string k0_DegreeBallFileName_00 = "test_ball_spin_st-landmarks_rand_1st_3280w_bright_04.png";
    const std::string kUnknown_DegreeBallFileName_00 = k"test_ball_spin_st-landmarks_rand_2nd_3280w_bright_04.png";

    const std::string k0_DegreeBallFileName_00 = "test_pos_2592w_BASE6off_22Dist_00inz_00degx_00iny_00.png";
    const std::string kUnknown_DegreeBallFileName_00 = "test_pos_2592w_6off_22Dist_10inz_30degx_.75iny_00.png";

    const std::string k0_DegreeBallFileName_00 = "test_ball_spin_strong_landmarks_00d_2592w_bright_00.png";
    const std::string kUnknown_DegreeBallFileName_00 = "test_ball_spin_strong_landmarks_45d_2592w_bright_00.png";
   */

    const std::string k0_DegreeBallFileName_00 = "strobed_spin_test_0z_ctr_02.png";
    const std::string kUnknown_DegreeBallFileName_00 = "strobed_spin_test_30z_-30x_ctr_02.png";
    // const std::string kUnknown_DegreeBallFileName_00 = "loc_test_20_degree_right_strobed.png";
    // NEEDS TO BE CORRECTED FOR EACH TEST -  Assume only 1 camera for now, so all deltas are 0
    // In meters
    std::vector<cv::Vec3d> camera_positions_from_origin = std::vector<cv::Vec3d>({ GolfSimCamera::kCamera1PositionsFromExpectedBallMeters, GolfSimCamera::kCamera2PositionsFromExpectedBallMeters });


    cv::Mat ball1ImgGray;
    cv::Mat ball2ImgGray;
    cv::Mat ball1ImgColor;
    cv::Mat ball2ImgColor;

    CameraHardware::CameraModel  camera_2_model = GolfSimCamera::kSystemSlot1CameraType;

    if (!GsAutomatedTesting::ReadTestImages(k0_DegreeBallFileName_00, kUnknown_DegreeBallFileName_00, ball1ImgGray, ball2ImgGray, ball1ImgColor, ball2ImgColor, camera_2_model, false /*No Undistort*/)) {
        GS_LOG_TRACE_MSG(trace, "Failed to read valid images.");
        return false;
    }

    // Get the ball data.  We will calibrate based on the first ball and then get the second one
    // using that calibrated data from the first ball.
    
    GolfSimCamera c;
    c.camera_hardware_.init_camera_parameters(GsCameraNumber::kGsCamera1, camera_2_model);

    GolfBall ball1, ball2;

    c.camera_hardware_.firstCannedImageFileName = kBaseTestDir + k0_DegreeBallFileName_00;
    c.camera_hardware_.firstCannedImage = ball1ImgColor;

    cv::Vec2i expectedBallCenter = cv::Vec2i(1456 / 3, 1088 / 2);

    if (GolfSimOptions::GetCommandLineOptions().search_center_x_ > 0) {
        expectedBallCenter[0] = GolfSimOptions::GetCommandLineOptions().search_center_x_;
    }

    if (GolfSimOptions::GetCommandLineOptions().search_center_y_ > 0) {
        expectedBallCenter[1] = GolfSimOptions::GetCommandLineOptions().search_center_y_;
    }


    bool success = c.GetCalibratedBall(c, ball1ImgColor, ball1, expectedBallCenter);

    if (!success) {
        GS_LOG_TRACE_MSG(trace, "Failed to GetCalibratedBall.");
        return false;
    }
    c.camera_hardware_.firstCannedImageFileName = kBaseTestDir + k0_DegreeBallFileName_00;
    c.camera_hardware_.secondCannedImageFileName = kBaseTestDir + kUnknown_DegreeBallFileName_00;
    c.camera_hardware_.firstCannedImage = ball1ImgColor;
    c.camera_hardware_.secondCannedImage = ball2ImgColor;

    success = c.GetCurrentBallLocation(c, ball2ImgColor, ball1, ball2);

    if (!success) {
        GS_LOG_TRACE_MSG(trace, "Could not find 2nd ball");
        return false;
    }

    boost::timer::cpu_timer timer1;

    cv::Vec3d rotationResults = BallImageProc::GetBallRotation(ball1ImgGray, ball1, ball2ImgGray, ball2);

    timer1.stop();
    boost::timer::cpu_times times = timer1.elapsed();
    std::cout << "BallImageProc::GetBallRotation: ";
    std::cout << std::fixed << std::setprecision(8)
        << times.wall / 1.0e9 << "s wall, "
        << times.user / 1.0e9 << "s user + "
        << times.system / 1.0e9 << "s system.\n";

    // TBD - Now implemented in the GetBallRotation() function.  See how the original image would look if rotated as the GetBallRotation function calculated

    std::string s = "Ball Rotation (degrees):  X: " + std::to_string(rotationResults[0]) + "\tY: " + std::to_string(rotationResults[1]) + "\tZ: " + std::to_string(rotationResults[2]) + "\n";

    return true;
}



bool TestSpin() {

    GolfBall ball1;
    GolfBall ball2;
    cv::Mat img1;
    cv::Mat img2;

    GS_LOG_MSG(info, "TestSpin is in process.");
    GS_LOG_TRACE_MSG(trace, "Please position the ball for a first image and hit any key.");

    int keyPressed = cv::waitKey(0) & 0xFF;

#ifdef __unix__   

    // Find the first ball.  This will cause a pause to view the image
    // that will allow the user to reposition the ball for a second time
    if (!CheckForBall(ball1, img1)) {
        GS_LOG_TRACE_MSG(trace, "Failed to CheckForBall.");
        return false;
    }

    GS_LOG_TRACE_MSG(trace, "Position the ball for a second image and hit any key.");

    if (!CheckForBall(ball2, img2)) {
        GS_LOG_TRACE_MSG(trace, "Failed to CheckForBall.");
        return false;
    }

    LoggingTools::LogImage("test_spin_img_ball1", img1, std::vector < cv::Point >{}, true);
    LoggingTools::LogImage("test_spin_img_ball2", img2, std::vector < cv::Point >{}, true);

    cv::Mat grayImage1;
    cv::Mat grayImage2;
    cv::cvtColor(img1, grayImage1, cv::COLOR_BGR2GRAY);
    cv::cvtColor(img2, grayImage2, cv::COLOR_BGR2GRAY);

    cv::Vec3d rotationResults = BallImageProc::GetBallRotation(grayImage1, ball1, grayImage2, ball2);
#endif

    return true;
}

bool testAnalyzeStrobedBalls() {

    // Have to call this here because we are not starting the FSM, but need (simulated) pulse information
    PulseStrobe::InitGPIOSystem();

    std::string kTwoImageTestTeedBallImage;
    std::string kTwoImageTestStrobedImage;
    std::string kTwoImageTestPreImage;

    GolfSimConfiguration::SetConstant("gs_config.testing.kTwoImageTestTeedBallImage", kTwoImageTestTeedBallImage);
    GolfSimConfiguration::SetConstant("gs_config.testing.kTwoImageTestStrobedImage", kTwoImageTestStrobedImage);
    GolfSimConfiguration::SetConstant("gs_config.testing.kTwoImageTestPreImage", kTwoImageTestPreImage);

    const std::string kTestCamImageFileName_00 = kTwoImageTestTeedBallImage;
   
    const std::string kTestCam2StrobedmageFileName = kTwoImageTestStrobedImage;

    cv::Mat ball1ImgGray;
    cv::Mat ball2ImgGray;
    cv::Mat ball1ImgColor;
    cv::Mat ball2ImgColor; 

    const GsCameraNumber camera_number = GolfSimOptions::GetCommandLineOptions().GetCameraNumber();
    const CameraHardware::CameraModel camera_model = GolfSimCamera::kSystemSlot1CameraType;

    if (!GsAutomatedTesting::ReadTestImages(kTestCamImageFileName_00, kTestCam2StrobedmageFileName, ball1ImgGray, ball2ImgGray, ball1ImgColor, ball2ImgColor, camera_model, false /*No Undistort*/)) {
        GS_LOG_TRACE_MSG(trace, "Failed to read valid images.");
        return false;
    }

    cv::Mat camera2_pre_image_color;
    /****  NO LONGER USED
    // Also read the test  pre-image
    std::string preImageFileName = kBaseTestDir + kTwoImageTestPreImage;

    GS_LOG_TRACE_MSG(trace, "Pre Image1: " + preImageFileName);

    camera2_pre_image_color = cv::imread(preImageFileName, cv::IMREAD_COLOR);

    if (camera2_pre_image_color.empty()) {
        return false;
    }
    ***/

    GolfBall result_ball;
    cv::Vec3d rotation_results;
    cv::Mat exposures_image;
    std::vector<GolfBall> exposure_balls;

    if (!GolfSimCamera::ProcessReceivedCam2Image(ball1ImgColor, 
                                                 ball2ImgColor, 
                                                 camera2_pre_image_color, 
                                                 result_ball, 
                                                 rotation_results, 
                                                 exposures_image, 
                                                 exposure_balls)) {
        GS_LOG_MSG(error, "Failed ProcessReceivedCam2Image.");
        return false;
    }

#ifdef __unix__  // Ignore in Windows environment
    GsUISystem::SaveWebserverImage("kCameraXBallLocation_", ball1ImgColor, exposure_balls);
#endif
    GsGSProResults results(result_ball);
    GS_LOG_TRACE_MSG(trace, "Results are: " + results.Format());

    PulseStrobe::DeinitGPIOSystem();

    return true;
}
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
int main(int argc, char *argv[])
{
    try {
        if (!GolfSimOptions::GetCommandLineOptions().Parse(argc, argv))
        {
            GS_LOG_MSG(error, "Could not GetCommandLineOptions.  Exiting.");
            return 0;
        }

	// If we're just showing the help information, that's already been
	// done when we called parse.  So just exit.
	if (GolfSimOptions::GetCommandLineOptions().help_)
	{
		return 1;
	}

        LoggingTools::InitLogging();

        GS_LOG_MSG(info, "Golf Sim Launch Monitor Started");

        GolfSimOptions::GetCommandLineOptions().Print();

        std::string config_file_name = "golf_sim_config.json";

        if (!GolfSimOptions::GetCommandLineOptions().config_file_.empty()) {
            config_file_name = GolfSimOptions::GetCommandLineOptions().config_file_;
        }

        if (!GolfSimConfiguration::Initialize(config_file_name)) {
            GS_LOG_MSG(error, "Could not initialize configuration module using config file: " + config_file_name + ".  Exiting.");
            return 0;
        }

        LoggingTools::logging_tool_wait_for_keypress_ = GolfSimOptions::GetCommandLineOptions().wait_for_key_on_images_;

        // We prefer the command-line setting even if there's one in the .json config file
        if (!GolfSimOptions::GetCommandLineOptions().base_image_logging_dir_.empty()) {
            kBaseTestDir = GolfSimOptions::GetCommandLineOptions().base_image_logging_dir_;
        }
        else {
            // Attempt to get the image logging directory from the .json config file
#ifdef __unix__
            GolfSimConfiguration::SetConstant("gs_config.logging.kLinuxBaseImageLoggingDir", kBaseTestDir);
#else
            GolfSimConfiguration::SetConstant("gs_config.logging.kPCBaseImageLoggingDir", kBaseTestDir);
#endif
        }
        // If the configuration file forgot to add a "/" at the end of the logging directory, we should add it here ourselves
        if (kBaseTestDir.back() != '/') {
            kBaseTestDir += '/';
        }


        // TBD - consider if there is a better place for this?
        GolfSimGlobals::golf_sim_running_ = true;

        run_main(argc, argv);
    }
    catch (std::exception const& e)
    {
        GS_LOG_MSG(error, "Exception occurred. ERROR: *** " + std::string(e.what()) + " ***");
        return false;
    }

    GS_LOG_TRACE_MSG(trace, "Finished run_main.");
    
    // GS_LOG_TRACE_MSG(trace, "Waiting for any keypress to end program.");
    // cv::waitKey(0);

    GS_LOG_TRACE_MSG(trace, "Tests Complete");
}

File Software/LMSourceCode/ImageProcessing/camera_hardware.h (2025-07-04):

/* SPDX-License-Identifier: GPL-2.0-only */
/*
 * Copyright (C) 2022-2025, Verdant Consultants, LLC.
 */

// Attempts to hide some details about the specific camera hardware in use.
// Coding for any new cameras should start here

#pragma once

#include <string>
#include "logging_tools.h"
#include "cv_utils.h"
#include "gs_globals.h"
#include "gs_options.h"

namespace golf_sim {

    class CameraHardware {

    public:

        // If set to >0, init_camera_parameters will use these values instead of camera-model-specific values
        // That way, if you want to use an image with X,Y resolution different than the current camera, you
        // can sort of make-believe that a camera with just your X,Y resolution took the picture.
        // TBD - Should not be static
        static int resolution_x_override_;
        static int resolution_y_override_;

        int CAMERA_NUM_PICTURES_TO_TAKE = 2;

        enum CameraModel {
            PiCam13 = 1,
            PiCam2 = 2,
            PiHQCam6mmWideLens = 3,
            PiGSCam6mmWideLens = 4,
            PiGSCam3_6mmLens = 5,
            InnoMakerIMX296GS3_6mmM12Lens = 6,
            kUnknown = 100
        };

        // An initial set of states to simulate a camera repeatedly taking pictures until
        // (at some point in time), the object of interest in the image changes.
        // Was used to test the camera 1 movement processing.
        enum TestVideoState {
            ImagesLoaded,
            TakingInitialStaticFrames,
            FirstMovementFrame,
            BallGoneFrames
        };

        // This is the camera number from the perspective of the PiTrac system.
        // So kGsCamera1 is the camera that watches the teed-up ball, and 
        // kGsCamera2 is the camera that images the ball in flight
        GsCameraNumber camera_number_ = GsCameraNumber::kGsCamera1;

        CameraModel camera_model_ = CameraModel::PiHQCam6mmWideLens;
        float focal_length_ = 0;        // In millimeters
        float horizontalFoV_ = 0;        // In degrees
        float verticalFoV_ = 0;          // In degrees
        float sensor_width_ = 0;        // The physical size of the camera sensor, inclusive of all the pixels.  In mm
        float sensor_height_ = 0;       // In mm

        bool use_calibration_matrix_ = false;

        cv::Mat calibrationMatrix_;
        cv::Mat cameraDistortionVector_;

        // These SHOULD depend on camera model
        // -1 if not set via init_camera_parameters or otherwise overridden
        int resolution_x_ = -1;
        int resolution_y_ = -1;

        // For some cameras, the video resolution may be different (and 
        // typically lower) than the still-picture resolution
        int video_resolution_x_ = -1;
        int video_resolution_y_ = -1;

        cv::Vec2d camera_angles_;

        // Will be set to a reasonable default based on the camera in use
        // Can be overridden from the .json config file using either of 
        // kExpectedBallRadiusPixelsAt40cmCamera1 or 2
        int expected_ball_radius_pixels_at_40cm_ = 0;

        bool is_mono_camera_ = false;

        // if set, the camera will use this image (file) as if (it were the image that the
        // camera took on the Pi, regardless of operating system.  First will be used first, then
        // if another picture is needed, the second will be used.
        std::string firstCannedImageFileName;
        std::string secondCannedImageFileName;

        cv::Mat firstCannedImage;
        cv::Mat secondCannedImage;

        // true; if the camera is all ready to go to take a picture.
        bool cameraReady = false;

        CameraHardware();
        ~CameraHardware();

        static CameraModel string_to_camera_model(const std::string& model_enum_value_string);

        // Used when using test images instead of live photos
        // Pre-loads the test images to allow for faster simulated returns of them
        void load_test_images();

        void init_camera();
        void deinit_camera();

        void init_camera_parameters(const GsCameraNumber camera_number, 
                                    const CameraModel model, 
                                    const bool use_default_focal_length = false);

        bool prepareToTakePhoto();
        cv::Mat take_photo();

        bool prepareToTakeVideo();
        cv::Mat getNextFrame();

        // TBD - Probably should be private, but the higher-level golf_sim_camara needs to check this sometimes
        bool cameraInitialized = false;

    private:

        // Counts the number of static images that have been sent so far if this camera is
        // being emulated by software to take the place of a real camera.
        int staticImagesSent = 0;

        TestVideoState testVideoState = TestVideoState::ImagesLoaded;
        int currentStaticImageIndex = 0;
    };

}

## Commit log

2024-12-17 Adding subprojects and small docs edits
    [Camera Mount - Bottom Variation.3mf, Camera Mount - Bottom Variation.stl, Camera Mount - Bottom.FCStd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]
2024-12-17 New docs
    [PiTrac - Camera Calibration Worksheet.xlsx]
2024-12-20 Create LED Light Mount.3mf
    [LED Light Mount.3mf]
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2024-12-27 First commit of the source code.
    [rotation_estimate_analysis.xlsx, spin_analysis_coarse.csv, spin_analysis_fine.csv]
2024-12-27 Changing build directory name
    [rotation_estimate_analysis.xlsx, spin_analysis_coarse.csv, spin_analysis_fine.csv]
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2024-12-31 Pi trac team development branch updates (#19)
    * Removed some unused configuration parameters
    kShowDebugImagesDuringExposureSelection was not used and was confusing.
    * Improved Tomcat webshare process, added HOUGH_GRADIENT_ALT - specific parameters to improve circle detection, updated and added documents.
    [spin_analysis_coarse.csv, spin_analysis_fine.csv]
2025-01-01 Pi trac team dev branch - mostly work for Visual Studio compile environment. (#27)
    * Improvements for running PiTrac in Visual Studio
    * Fixes to compile better in Visual Studio
    [ball_image_proc.cpp]
2025-01-03 Changes for Issue #35 - Improved Golf Sim Arming Processing (#42)
    Added new states to FSM, new internal and IPC events for waiting for arming and to let the GUI know what is happening. Also updated the GUI show a yellow-colored band at the top when waiting for a golf sim arming message.
    [ball_image_proc.cpp, ball_image_proc.h, golf_ball.h]
2025-01-05 Adding top camera mount files
    [Camera Mount - Top Variation (Cam1).FCStd, Camera Mount - Top Variation.3mf, Camera Mount - Top Variation.stl]
2025-01-06 Adding logo stl files
    [PiTrac Logo-Individual Characters Body.stl, PiTrac Logo-Logo - Back Plate Object.stl]
2025-01-06 Adding Combined model files
    [Base Layer - Pi Side - Upper Floor.3mf, Base Layer - Pi Side - Upper Floor.FCStd, Base Layer - Pi Side - Upper Floor.stl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]
2025-01-06 Removing mis-named model files
    [Base Layer - Pi Side - Upper Floor.3mf, Base Layer - Pi Side - Upper Floor.FCStd, Base Layer - Pi Side - Upper Floor.stl]
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2025-01-12 Fixes to remove warnings.
    [ball_image_proc.cpp, ball_image_proc.h, gs_camera.h]
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2025-01-16 Fixes to remove warnings and error when using --help command line.
    [lm_main.cpp]
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2025-01-17 Adding thumbscrew cutaways.
    [Camera Mount - Bottom Variation.3mf, Camera Mount - Bottom Variation.stl, Camera Mount - Bottom.FCStd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]
2025-01-21 Adding CLAHE processing and fixed ball-spin pair selection problem with differing radii.
    [ball_image_proc.cpp, ball_image_proc.h, lm_main.cpp]
2025-01-22 Fixed inconsistency with typical z-axis distance numbers.
2025-01-22 Adding steps to ensure extraneous lens adapter is removed and warning about possible thumb-screw impingement on the mount.
2025-01-23 Modifying the camera mounts and floors to try to have the lens thumbscrews have more room.
    [Base Layer - Pi Side - Floor.3mf, Base Layer - Pi Side - Floor.FCStd, Base Layer - Pi Side - Floor.stl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]
2025-01-29 Added back in the missing camera calibration code.
2025-01-30 Added discoverPiCamLocation.sh to camera tools to allow identification of where the Pi Camera is.
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2025-02-07 Update PiTrac - DIY LM Parts List.md
    Added note about how the LED strip light should not produce any IR.
2025-02-10 Fixed sign issue that was causing side-spin to be wrong.
    [ball_image_proc.cpp]
2025-03-06 Fixed dropped frames during ball motion detection by setting kFramePeriod to 0. Users may need to tee ball closer to the middle of the unit now.
    [spin_analysis_coarse.csv, spin_analysis_fine.csv]
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2025-03-07 Docs: Fixed Search and Split Tee Camera page one more time. (#73)
    * docs: splitting tee cam page.
    * bug: fixed search bar.
    ---------
    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
2025-03-30 Adding new Version 2 Enclosure 3D models and documents.
    [Backplate - Copy (2).FCStd, Backplate - Copy.FCStd, Backplate.FCStd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]
2025-04-01 Adding new Version 2 Enclosure 3D Model for Pi4-5 and Connector Board Tower.
    [Tower Backplate Bodies.3mf, Tower Backplate Body - Connector Board Variant.stl, Tower Backplate Body.stl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]
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2025-04-04 Fixed a couple problems with basebox height parameterization to make it easier to stretch it vertically.
    [BaseBox.FCStd, Master Document.FCStd]
2025-04-07 Added cross-bracing between the fingers of the upper half of the case to reduce vibration-induced print problems. Also added cooling slots near the Pi Compute Moduels.
    [CaseCover.FCStd, Master Document.FCStd, Upper Case Cover Body.stl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]
2025-04-10 Added calibration rig to help with auto-calibration process.
    [Calibration Rig.3mf, Calibration Rig.stl, CalibrationRigFCStd.FCStd]
2025-04-14 Recreated Connector-Board-Variant of the Tower model. Now includes pre-split parts.
    [Tower Backplate Body - Connector Board Variant - Split Pieces.3mf, Tower Backplate Body - Connector Board Variant - Split Pieces.stl, Tower Backplate Body.stl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]
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2025-04-15 Adding missing files to support adding the start of auto-calibration, improved ball-identification parameters, and some code changes to help accomodate left-handed golfing. Also finished the camera2 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
    [lm_main.cpp]
2025-04-15 Added Testing directory to support automated testing and left-handed operations.
    [PiTrac_Test_Results.csv, Uneekor Comparison 2025-02-07 - Full.csv, Uneekor Comparison 2025-02-07_Small_Test.csv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]
2025-04-29 Added support material to reduce problems due to long cooling ribs vibrating during print.
    [BaseBox- Main Body.3mf, BaseBox- Main Body.stl, BaseBox.FCStd]
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2025-05-07 Dimensional tweaks to add more room around the LED Strobe holder and bay. Also added some assembly hints.
    [LED Light Mount.3mf, LED Light Mount.FCStd, LED Light Mount.stl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]
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2025-05-09 Update Raspberry Pi Setup and Configuration.md
    fix type in boost instructions
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2025-05-12 Update PiTrac - DIY LM Parts List.md
    Fixed link to opto-isolator part and noted need for DIP (not surface-mounted) pins.
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2025-05-16 Update PiTrac - DIY LM Parts List.md
    Shortened LED mounting screw length to 8mm from 10.
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2025-05-21 Added ports at bottom of case cover to accomodate cables.
    [CaseCover.FCStd, Lower Case Cover Body.3mf, Lower Case Cover Body.stl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]
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2025-05-21 Added a port for the camera ribbon cable to come up from the bottom of the first floor for camera 2.
    [Master Document.FCStd, Tower Backplate Body (pieces split).stl, Tower Backplate Body.stl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]
2025-05-22 Fixed problem where running in Camera 1 ball location mode was choosing the wrong camera.
    [lm_main.cpp]
2025-06-10 Fixed pulse-train creation to send only one long-ish pulse when taking a single picture using the flight camera.
2025-06-11 Update Raspberry Pi Setup and Configuration.md
    Fixed some activemq issues.
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2025-06-13 Added to short pieces to position teed ball near to the center of the PiTrac.
    [Calibration Rig.3mf, Calibration Rig.stl, CalibrationRig.FCStd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]
2025-06-13 Added two short pieces to position teed ball near to the center of the PiTrac.
    [Master Document.FCStd]
2025-06-13 Updated the two short pieces of the calibration rig to position teed ball near to the center of the PiTrac.
    [Calibration Rig - Pieces Laid Out.stl, Calibration Rig.3mf, Calibration Rig.stl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]
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2025-06-20 Fixed compile error in pulse_strobe.cpp (linux). Moved tower feet mount holes further outboard to make it easier to screw them in. Shifted tower slightly forward to make more room in the back for cab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
    [BaseBox- Main Body.3mf, BaseBox- Main Body.stl, Master Document.FCStd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]
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2025-06-23 Fixed shot-counting problem and tweaked image_processing.
    [lm_main.cpp]
2025-06-24 Adding a filter holder for M12 lenses.
    [Master Document.FCStd, Pi Cam Filter Holder - M12 Lens - Both Halves Split.stl, Pi Cam Filter Holder - M12 Lens.3mf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]
2025-06-24 Widened calibration stick hole and created access to get tool to tighten bottom camera mount.
    [BaseBox.FCStd, Master Document.FCStd]
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2025-06-26 Added a camera-mount model for the Innomaker CAM-IMX296.
    [Camera Mount - Bottom Variation - Both Parts Separated.stl, Camera Mount - Bottom Variation.3mf, Camera Mount - Bottom Variation.stl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]
2025-06-26 Added parameters for a camera-mount model for the Innomaker CAM-IMX296.
    [Master Document.FCStd]
2025-06-26 Update PiTrac - DIY LM Parts List.md
    corrected IR wavelength references to be 730. Added info on the Innomaker camera
2025-06-26 Increased default height of base box. This should accomodate larger LED drivers when they are installed instead of a power supply. Also corrected some parameterization issues and cleaned up the 3D pr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
    [BaseBox- Light Shield Body.3mf, BaseBox- Light Shield Body.stl, BaseBox- Main Body - OLD.3mf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]
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2025-06-27 Various small tweaks and improvements to Basebox, Innomaker camera-mount and Tower parts, including moving the Pi 5 board mounts to allow for easier cable routing and lowering the top camera-mount.
    [Camera Mount - Innomaker Top.FCStd, Camera Mount - Top Variation - Both Parts Separated.stl, Camera Mount - Top Variation.3mf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]
2025-06-30 Added a shank shield model and corresponding .dxf file to help folks cut/mill the shield.
    [BaseBox-Shank Shield Body.dxf, BaseBox.FCStd, Master Document.FCStd]
2025-06-30 Fixed the gimbal nut indent, which was too large to prevent the nut from spinning.
    [Camera Mount - Bottom Variation - Both Parts Separated.stl, Camera Mount - Bottom Variation.stl, Camera Mount - Innomaker Bottom.FCStd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]
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2025-07-04 Update Raspberry Pi Setup and Configuration.md
    Corrected and clarified tomee system setup.
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2025-07-08 Single-pi scripts that generate the strobe pulses now run at nice level -10 to try to prevent the pulses from being interrupted from other processes.
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2025-07-08 Fixed missing code for Pi GS camera and 3.6 M12 lens combination.
2025-07-09 Moved camera closer to filter and relaxed the filter fit.
    [Master Document.FCStd, Pi Cam Filter Holder - M12 Lens - Both Halves Split.stl, Pi Cam Filter Holder - M12 Lens.3mf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]
2025-07-10 Update Raspberry Pi Setup and Configuration.md
    Small correction for pitrac gui install
2025-07-12 Various improvments, including removing concentric balls, better pre-Hough filtering, fixed some edge case problems.
    [ball_image_proc.cpp, ball_image_proc.h, gs_camera.h]
2025-07-12 Automated tests of a camera bounded context (#87)
    * Preparing a clean architecture for the camera bounded context
    * Adding unit tests
    * Testing workflow
    * set environment variable Boost_ROOT for consistency
    * docs: Add comprehensive TODO list and learnings from bounded context implementation
    - Captured all namespace architecture issues and solutions
    - Documented missing value objects and domain types that need implementation
    - Identified interface design mismatches between layers
    - Created incremental implementation strategy with specific phases
    - Added build process lessons learned and recommended approaches
    - Defined technical architecture decisions that need to be made
    - Provided cle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
2025-07-12 Image Analysis Bounded Context with Approval Test framework (#89)
    * Extracting an ImageAnalysis bounded context
    * Add image BC automated tests CI workflow
    * Install OpenCV on build agent
    * vcpkg opencv
    * CMAke policy for boost compatibility
    * simplified cmake config
    * configure opencv library path
    * use opencv config path in pipeline
    * check opencv config path is the build folder - to fix pipeline
    * use cmake command argument for opencv path
    * check the path contains the CMake config for opencv
    * I think opencv is installed to C:\tools\opencv
    * I think opencv is installed to wherever the exe is run
    * logging to debug boost libraries needed for cmake
    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
    [approval_test_config.hpp, test_image_analysis_domain.cpp]
